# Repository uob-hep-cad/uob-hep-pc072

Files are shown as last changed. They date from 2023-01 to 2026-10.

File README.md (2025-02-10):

# uob-hep-pc072
DUNE Timing System MicroTCA Interface Board(MIB). 

Schematic capture in Cadence DE-HDL. PCB Layout in Cadence Allegro.

Design files for the current (v3) board at https://github.com/uob-hep-cad/uob-hep-pc072/tree/main/hardware/Cadence/top/mtca_interface_board_reocc/top_mib_v3 (project file https://github.com/uob-hep-cad/uob-hep-pc072/blob/main/hardware/Cadence/top/top_mib_v3.cpm)

Design files for the tongue-2 board at https://github.com/uob-hep-cad/uob-hep-pc072/tree/main/hardware/Cadence/top/mtca_interface_board_reocc/mib_tongue2 (project file https://github.com/uob-hep-cad/uob-hep-pc072/blob/main/hardware/Cadence/top/top_mib_v3.cpm)

Schematic capture and PCB layout of the original (v1) version done at University of Pensylvania by Godwin Meyers in Cadence Orcad/Allegro

The v1 design translated to Cadence Allegro Design Entry HDL by Elgris Technologies

Changes to v1 design done by Magnus Loutit and David Cussans to produce the v2 and then v3 design

PCB layout of the v3 design done at the University of Oxford by Pete Hastings

The MIB v2 onwards has no ADN2814 CDR - recovery of clock done directly by Si5395 PLL

List of changes w.r.t. v0.1 MIB at https://webapps-pp.bris.ac.uk/elog/DUNE/34

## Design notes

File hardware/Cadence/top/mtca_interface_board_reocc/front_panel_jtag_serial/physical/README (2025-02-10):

pc072_mib_jtag_serial

Version = A
Subversion = 20

This file describes PCB fabrication details for the
JTAG/Serial mezzanine board for the MIB v2 
for the DUNE timing system
 
contact:	David.Cussans@bristol.ac.uk
		tel: 0117 95 46879
		     0117 33 17199
		fax: 0117 925 5624

Files produced by Cadence Allegro PE17.4

Artwork:
--------

Format: Gerber RS-274X , parameters described in art_param.txt. 
All layers viewed from top

Build:
------

"PCBTrain" 4-layer build from Newbury
Immersion silver finish to outer layers

Layers as follows:

pc072_mib_jtag_serial_20_01_Top.art
pc072_mib_jtag_serial_20_02_Gnd.art
pc072_mib_jtag_serial_20_03_Vcc.art
pc072_mib_jtag_serial_20_04_Bottom.art

Solder Masks
------------

pc072_mib_jtag_serial_20_13_smask_top.art
pc072_mib_jtag_serial_20_14_smask_bot.art

Colour - green. 

Solderpaste mask (N.B. No SMD components on bottom face of board)
-----------------

pc072_mib_jtag_serial_20_27_pmask_top.art
pc072_mib_jtag_serial_20_28_pmask_bot.art

Silk screen
-----------

pc072_mib_jtag_serial_20_11_silk_top.art
pc072_mib_jtag_serial_20_12_silk_bot.art

Colour - white.

Board outline: (Gerber RS-274X)
-------------------------------

pc072_mib_jtag_serial_20_18_DESIGN_OUTLINE.art

Fabrication drawing: ( Including illustration of hole sizes/position and board stack-up)
----------------------------------------------------------------------------------------

pc072_mib_jtag_serial_20_fab_plot.art

Drill information ( Excellon format, described in nc_param.txt. Drill size also in nc_tools_auto.txt )
----------------------------------------------------------------

pc072_mib_jtag_serial_20-1-4.drl

Router information ( Excellon format, described in nc_param.txt. Router bit information also in ncroutebits_auto.txt )
----------------------------------------------------------------

mib_fp_jtag_serial_20_1-4.rou 

Drill figure (Gerber format)
----------------------------

pc072_mib_jtag_serial_20_10_drill_figure.art

Bill of Materials for Assembly (Microsoft Excel XLSX format)
------------------------------------------------------------

uob-hep-pc072-mib_fp_jtag_serial_10.xlsx

Assembly Information (IPC2581 format)
-------------------------------------

mib_fp_jtag_serial_20_ipc2581.xml

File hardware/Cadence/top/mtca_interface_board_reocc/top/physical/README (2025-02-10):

pc072

Version = A
Subversion = 205

This file describes PCB fabrication details for the MIB v2 
for the DUNE timing system
 
contact:	David.Cussans@bristol.ac.uk
		tel: 0117 95 46879
		     0117 33 17199
		fax: 0117 925 5624

Files produced by Cadence Allegro PE17.4

Artwork:
--------

Format: Gerber RS-274X , parameters described in art_param.txt. 
All layers viewed from top

Build:
------

"PCBTrain" 10-layer build from Newbury
ENIG finish to outer layers

Layers as follows:

mib_rev2_v205_01_Top.art
mib_rev2_v205_02_GND.art
mib_rev2_v205_03_sig1.art
mib_rev2_v205_04_GND.art
mib_rev2_v205_05_PWR1.art
mib_rev2_v205_06_GND.art
mib_rev2_v205_07_SIG2.art
mib_rev2_v205_08_GND.art
mib_rev2_v205_09_SIG3.art
mib_rev2_v205_10_Bottom.art

Solder Masks
------------

mib_rev2_v205_13_smask_top.art
mib_rev2_v205_14_smask_bot.art

Colour - green. 

Solderpaste mask
-----------------

mib_rev2_v205_27_pmask_top.art
mib_rev2_v205_28_pmask_bot.art

Silk screen
-----------

mib_rev2_v205_11_silk_top.art
mib_rev2_v205_12_silk_bot.art

Colour - white.

Board outline: (Gerber RS-274X)
-------------------------------

mib_rev2_v205_18_DESIGN_OUTLINE.art

Board cutout: 
-------------------------------

The board has one cutout. outline of cutout in:

mib_rev2_v199_19_CUTOUT.art  (Gerber RS-274X)
mib_rev2_v205_1-10.rou       (Excellon)

Fabrication drawing: ( Including illustration of hole sizes/position and board stack-up)
-------------

N.B. Ignore comments about hard-gold on connector "fingers"

mib_rev2_v199_15_fab_plot.art

Drill information ( Excellon format, described in nc_param.txt )
----------------------------------------------------------------

mib_rev2_v205-1-10.drl

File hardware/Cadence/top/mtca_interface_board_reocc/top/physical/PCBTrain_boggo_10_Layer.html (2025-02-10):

Version : 17.400

Date/Time : 2023-03-20T18:32:34

Worksheet Name : Cross Section\Layer\Cross Section\Properties

Objects | | Types | | | | Thickness | | | Physical | | | | | | Embedded | | Signal Integrity
# | Name | Layer | Layer Function | Manufacture | Constraint | Value | (+)Tol. | (-)Tol. | Layer ID | Material | Negative Artwork | No Fillet | Unused Pin Suppression | Unused Via Suppression | Embedded Status | Attach Method | Conductivity | Dielectric Constant | Width | Impedance | Loss Tangent | Shield | Freq. Dep. File | Etch Factor | Diff Coupling Type | Diff Spacing | Diff Z0 | SI Ignore

| | | | | | mm | mm | mm | | | | | | | | | mho/cm | | mm | Ohm | | | | | | mm | Ohm
* | * | * | * | * | * | * | * | * | * | * | * | * | * | * | * | * | * | * | * | * | * | * | * | * | * | * | * | *
| | Surface | | | | | | | | | | | | | | | | 1 | | | 0
1 | TOP | Conductor | Conductor | | | 0.035 | 0.00254 | 0.00254 | 1 | 1oz Copper | | | | | Not embedded | | 580000 | 1 | 0.1871 | 54.267 | 0 | | | 90 | Edge | 0.2500 | 99.932
| | Dielectric | Dielectric | | | 0.12 | 0 | 0 | | Fr-4 | | | | | | | 0 | 4.2 | | | 0.035
2 | 02_GND | Plane | Plane | | | 0.035 | 0.00254 | 0.00254 | 2 | 1oz Copper | | | | | Not embedded | | 580000 | 1 | | | 0 | | | 90
| | Dielectric | Dielectric | | | 0.2 | 0 | 0 | | Fr-4 | | | | | | | 0 | 4.2 | | | 0.035
3 | 03_SIG1 | Conductor | Conductor | | | 0.035 | 0.00254 | 0.00254 | 3 | 1oz Copper | | | | | Not embedded | | 580000 | 1 | 0.1250 | 49.054 | 0 | | | 90 | Edge | 0.5000 | 96.692
| | Dielectric | Dielectric | | | 0.12 | 0 | 0 | | Fr-4 | | | | | | | 0 | 4.2 | | | 0.035
4 | 04_GND | Plane | Plane | | | 0.035 | 0 | 0 | 4 | 1oz Copper | | | | | Not embedded | | 580000 | 1 | | | 0 | | | 90
| | Dielectric | Dielectric | | | 0.2 | 0 | 0 | | Fr-4 | | | | | | | 0 | 4.2 | | | 0.035
5 | 05_PWR1 | Plane | Plane | | | 0.035 | 0 | 0 | 5 | 1oz Copper | | | | | Not embedded | | 580000 | 1 | | | 0 | | | 90
| | Dielectric | Dielectric | | | 0.12 | 0 | 0 | | Fr-4 | | | | | | | 0 | 4.2 | | | 0.035
6 | 06_GND | Plane | Plane | | | 0.035 | 0.00254 | 0.00254 | 6 | 1oz Copper | | | | | Not embedded | | 580000 | 1 | | | 0 | | | 90
| | Dielectric | Dielectric | | | 0.2 | 0 | 0 | | Fr-4 | | | | | | | 0 | 4.2 | | | 0.035
7 | 07_SIG2 | Conductor | Conductor | | | 0.035 | 0.00254 | 0.00254 | 7 | 1oz Copper | | | | | Not embedded | | 580000 | 1 | 0.1250 | 49.054 | 0 | | | 90 | Edge | 0.5000 | 96.692
| | Dielectric | Dielectric | | | 0.12 | 0 | 0 | | Fr-4 | | | | | | | 0 | 4.2 | | | 0.035
8 | 08_GND | Plane | Plane | | | 0.035 | 0.00254 | 0.00254 | 8 | 1oz Copper | | | | | Not embedded | | 580000 | 1 | | | 0 | | | 90
| | Dielectric | Dielectric | | | 0.2 | 0 | 0 | | Fr-4 | | | | | | | 0 | 4.2 | | | 0.035
9 | 09_SIG3 | Conductor | Conductor | | | 0.035 | 0.00254 | 0.00254 | 9 | 1oz Copper | | | | | Not embedded | | 580000 | 1 | 0.1917 | 64.587 | 0 | | | 90 | Edge | 0.2000 | 100.04
| | Dielectric | Dielectric | | | 0.12 | 0 | 0 | | Fr-4 | | | | | | | 0 | 4.2 | | | 0.035
10 | BOTTOM | Conductor | Conductor | | | 0.035 | 0.00254 | 0.00254 | 10 | 1oz Copper | | | | | Not embedded | | 580000 | 1 | 0.3272 | 79.191 | 0 | | | 90 | Edge | 0.1250 | 99.968
| | Surface | | | | | | | | | | | | | | | | 1 | | | 0

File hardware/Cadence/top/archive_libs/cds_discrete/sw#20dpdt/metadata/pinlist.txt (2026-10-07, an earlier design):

(Pinlist
	(Pin
		(Name COMMON1)
		(MSB )
		(LSB )
		(Type ANALOG)
		(Location Left)
		(InputLoadLow )
		(InputLoadHigh )
		(OutputLoadLow )
		(OutputLoadHigh )
		(CheckLoad Off)
		(CheckIO Off)
		(CheckDir 0)
		(CheckAssert 0)
		(CheckOutput 0)
		(UnknownLoading 0)
		(PinShape )
		(DIFF_PAIR_PINS_POS )
		(DIFF_PAIR_PINS_NEG )
	)

	(Pin
		(Name NC1)
		(MSB )
		(LSB )
		(Type ANALOG)
		(Location Right)
		(InputLoadLow )
		(InputLoadHigh )
		(OutputLoadLow )
		(OutputLoadHigh )
		(CheckLoad Off)
		(CheckIO Off)
		(CheckDir 0)
		(CheckAssert 0)
		(CheckOutput 0)
		(UnknownLoading 0)
		(PinShape )
		(DIFF_PAIR_PINS_POS )
		(DIFF_PAIR_PINS_NEG )
	)

	(Pin
		(Name NO1)
		(MSB )
		(LSB )
		(Type ANALOG)
		(Location Right)
		(InputLoadLow )
		(InputLoadHigh )
		(OutputLoadLow )
		(OutputLoadHigh )
		(CheckLoad Off)
		(CheckIO Off)
		(CheckDir 0)
		(CheckAssert 0)
		(CheckOutput 0)
		(UnknownLoading 0)
		(PinShape )
		(DIFF_PAIR_PINS_POS )
		(DIFF_PAIR_PINS_NEG )
	)

	(Pin
		(Name COMMON2)
		(MSB )
		(LSB )
		(Type ANALOG)
		(Location Left)
		(InputLoadLow )
		(InputLoadHigh )
		(OutputLoadLow )
		(OutputLoadHigh )
		(CheckLoad Off)
		(CheckIO Off)
		(CheckDir 0)
		(CheckAssert 0)
		(CheckOutput 0)
		(UnknownLoading 0)
		(PinShape )
		(DIFF_PAIR_PINS_POS )
		(DIFF_PAIR_PINS_NEG )
	)

	(Pin
		(Name NC2)
		(MSB )
		(LSB )
		(Type ANALOG)
		(Location Right)
		(InputLoadLow )
		(InputLoadHigh )
		(OutputLoadLow )
		(OutputLoadHigh )
		(CheckLoad Off)
		(CheckIO Off)
		(CheckDir 0)
		(CheckAssert 0)
		(CheckOutput 0)
		(UnknownLoading 0)
		(PinShape )
		(DIFF_PAIR_PINS_POS )
		(DIFF_PAIR_PINS_NEG )
	)

	(Pin
		(Name NO2)
		(MSB )
		(LSB )
		(Type ANALOG)
		(Location Right)
		(InputLoadLow )
		(InputLoadHigh )
		(OutputLoadLow )
		(OutputLoadHigh )
		(CheckLoad Off)
		(CheckIO Off)
		(CheckDir 0)
		(CheckAssert 0)
		(CheckOutput 0)
		(UnknownLoading 0)
		(PinShape )
		(DIFF_PAIR_PINS_POS )
		(DIFF_PAIR_PINS_NEG )
	)

)

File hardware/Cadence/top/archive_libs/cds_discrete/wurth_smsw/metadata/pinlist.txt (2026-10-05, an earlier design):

(Pinlist
	(Pin
		(Name K)
		(MSB )
		(LSB )
		(Type ANALOG)
		(Location Left)
		(InputLoadLow )
		(InputLoadHigh )
		(OutputLoadLow )
		(OutputLoadHigh )
		(CheckLoad Off)
		(CheckIO Off)
		(CheckDir 0)
		(CheckAssert 0)
		(CheckOutput 0)
		(UnknownLoading 0)
		(PinShape )
		(DIFF_PAIR_PINS_POS )
		(DIFF_PAIR_PINS_NEG )
	)

	(Pin
		(Name A)
		(MSB )
		(LSB )
		(Type ANALOG)
		(Location Left)
		(InputLoadLow )
		(InputLoadHigh )
		(OutputLoadLow )
		(OutputLoadHigh )
		(CheckLoad Off)
		(CheckIO Off)
		(CheckDir 0)
		(CheckAssert 0)
		(CheckOutput 0)
		(UnknownLoading 0)
		(PinShape Line)
		(DIFF_PAIR_PINS_POS )
		(DIFF_PAIR_PINS_NEG )
	)

	(Pin
		(Name 1)
		(MSB )
		(LSB )
		(Type ANALOG)
		(Location Left)
		(InputLoadLow )
		(InputLoadHigh )
		(OutputLoadLow )
		(OutputLoadHigh )
		(CheckLoad Off)
		(CheckIO Off)
		(CheckDir 0)
		(CheckAssert 0)
		(CheckOutput 0)
		(UnknownLoading 0)
		(PinShape )
		(DIFF_PAIR_PINS_POS )
		(DIFF_PAIR_PINS_NEG )
	)

	(Pin
		(Name 2)
		(MSB )
		(LSB )
		(Type ANALOG)
		(Location Right)
		(InputLoadLow )
		(InputLoadHigh )
		(OutputLoadLow )
		(OutputLoadHigh )
		(CheckLoad Off)
		(CheckIO Off)
		(CheckDir 0)
		(CheckAssert 0)
		(CheckOutput 0)
		(UnknownLoading 0)
		(PinShape )
		(DIFF_PAIR_PINS_POS )
		(DIFF_PAIR_PINS_NEG )
	)

	(Pin
		(Name WURTH SMSW)
		(MSB )
		(LSB )
		(Type ANALOG)
		(Location Right)
		(InputLoadLow )
		(InputLoadHigh )
		(OutputLoadLow )
		(OutputLoadHigh )
		(CheckLoad Off)
		(CheckIO Off)
		(CheckDir 0)
		(CheckAssert 0)
		(CheckOutput 0)
		(UnknownLoading 0)
		(PinShape Line)
		(DIFF_PAIR_PINS_POS )
		(DIFF_PAIR_PINS_NEG )
	)

)

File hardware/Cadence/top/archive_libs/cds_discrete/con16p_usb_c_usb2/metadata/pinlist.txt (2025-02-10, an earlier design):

(Pinlist
	(Pin
		(Name GND1)
		(MSB )
		(LSB )
		(Type POWER)
		(Location Right)
		(InputLoadLow )
		(InputLoadHigh )
		(OutputLoadLow )
		(OutputLoadHigh )
		(CheckLoad Off)
		(CheckIO Off)
		(CheckDir 0)
		(CheckAssert 0)
		(CheckOutput 0)
		(UnknownLoading 0)
		(PinShape )
		(DIFF_PAIR_PINS_POS )
		(DIFF_PAIR_PINS_NEG )
	)

	(Pin
		(Name VBUS1)
		(MSB )
		(LSB )
		(Type POWER)
		(Location Left)
		(InputLoadLow )
		(InputLoadHigh )
		(OutputLoadLow )
		(OutputLoadHigh )
		(CheckLoad Off)
		(CheckIO Off)
		(CheckDir 0)
		(CheckAssert 0)
		(CheckOutput 0)
		(UnknownLoading 0)
		(PinShape )
		(DIFF_PAIR_PINS_POS )
		(DIFF_PAIR_PINS_NEG )
	)

	(Pin
		(Name CC1)
		(MSB )
		(LSB )
		(Type BIDIR)
		(Location Left)
		(InputLoadLow -0.01)
		(InputLoadHigh 0.01)
		(OutputLoadLow 1.0)
		(OutputLoadHigh -1.0)
		(CheckLoad Both)
		(CheckIO Both)
		(CheckDir 1)
		(CheckAssert 1)
		(CheckOutput 1)
		(UnknownLoading 0)
		(PinShape )
		(DIFF_PAIR_PINS_POS )
		(DIFF_PAIR_PINS_NEG )
	)

	(Pin
		(Name DA+)
		(MSB )
		(LSB )
		(Type BIDIR)
		(Location Left)
		(InputLoadLow -0.01)
		(InputLoadHigh 0.01)
		(OutputLoadLow 1.0)
		(OutputLoadHigh -1.0)
		(CheckLoad Both)
		(CheckIO Both)
		(CheckDir 1)
		(CheckAssert 1)
		(CheckOutput 1)
		(UnknownLoading 0)
		(PinShape )
		(DIFF_PAIR_PINS_POS )
		(DIFF_PAIR_PINS_NEG )
	)

	(Pin
		(Name DA-)
		(MSB )
		(LSB )
		(Type BIDIR)
		(Location Left)
		(InputLoadLow -0.01)
		(InputLoadHigh 0.01)
		(OutputLoadLow 1.0)
		(OutputLoadHigh -1.0)
		(CheckLoad Both)
		(CheckIO Both)
		(CheckDir 1)
		(CheckAssert 1)
		(CheckOutput 1)
		(UnknownLoading 0)
		(PinShape )
		(DIFF_PAIR_PINS_POS )
		(DIFF_PAIR_PINS_NEG )
	)

	(Pin
		(Name SBU1)
		(MSB )
		(LSB )
		(Type BIDIR)
		(Location Left)
		(InputLoadLow -0.01)
		(InputLoadHigh 0.01)
		(OutputLoadLow 1.0)
		(OutputLoadHigh -1.0)
		(CheckLoad Both)
		(CheckIO Both)
		(CheckDir 1)
		(CheckAssert 1)
		(CheckOutput 1)
		(UnknownLoading 0)
		(PinShape )
		(DIFF_PAIR_PINS_POS )
		(DIFF_PAIR_PINS_NEG )
	)

	(Pin
		(Name GND2)
		(MSB )
		(LSB )
		(Type POWER)
		(Location Right)
		(InputLoadLow )
		(InputLoadHigh )
		(OutputLoadLow )
		(OutputLoadHigh )
		(CheckLoad Off)
		(CheckIO Off)
		(CheckDir 0)
		(CheckAssert 0)
		(CheckOutput 0)
		(UnknownLoading 0)
		(PinShape )
		(DIFF_PAIR_PINS_POS )
		(DIFF_PAIR_PINS_NEG )
	)

	(Pin
		(Name VBUS2)
		(MSB )
		(LSB )
		(Type POWER)
		(Location Left)
		(InputLoadLow )
		(InputLoadHigh )
		(OutputLoadLow )
		(OutputLoadHigh )
		(CheckLoad Off)
		(CheckIO Off)
		(CheckDir 0)
		(CheckAssert 0)
		(CheckOutput 0)
		(UnknownLoading 0)
		(PinShape )
		(DIFF_PAIR_PINS_POS )
		(DIFF_PAIR_PINS_NEG )
	)

	(Pin
		(Name SBU2)
		(MSB )
		(LSB )
		(Type BIDIR)
		(Location Right)
		(InputLoadLow -0.01)
		(InputLoadHigh 0.01)
		(OutputLoadLow 1.0)
		(OutputLoadHigh -1.0)
		(CheckLoad Both)
		(CheckIO Both)
		(CheckDir 1)
		(CheckAssert 1)
		(CheckOutput 1)
		(UnknownLoading 0)
		(PinShape )
		(DIFF_PAIR_PINS_POS )
		(DIFF_PAIR_PINS_NEG )
	)

	(Pin
		(Name CC2)
		(MSB )
		(LSB )
		(Type BIDIR)
		(Location Right)
		(InputLoadLow -0.01)
		(InputLoadHigh 0.01)
		(OutputLoadLow 1.0)
		(OutputLoadHigh -1.0)
		(CheckLoad Both)
		(CheckIO Both)
		(CheckDir 1)
		(CheckAssert 1)
		(CheckOutput 1)
		(UnknownLoading 0)
		(PinShape )
		(DIFF_PAIR_PINS_POS )
		(DIFF_PAIR_PINS_NEG )
	)

	(Pin
		(Name DB+)
		(MSB )
		(LSB )
		(Type BIDIR)
		(Location Right)
		(InputLoadLow -0.01)
		(InputLoadHigh 0.01)
		(OutputLoadLow 1.0)
		(OutputLoadHigh -1.0)
		(CheckLoad Both)
		(CheckIO Both)
		(CheckDir 1)
		(CheckAssert 1)
		(CheckOutput 1)
		(UnknownLoading 0)
		(PinShape )
		(DIFF_PAIR_PINS_POS )
		(DIFF_PAIR_PINS_NEG )
	)

	(Pin
		(Name DB-)
		(MSB )
		(LSB )
		(Type BIDIR)
		(Location Right)
		(InputLoadLow -0.01)
		(InputLoadHigh 0.01)
		(OutputLoadLow 1.0)
		(OutputLoadHigh -1.0)
		(CheckLoad Both)
		(CheckIO Both)
		(CheckDir 1)
		(CheckAssert 1)
		(CheckOutput 1)
		(UnknownLoading 0)
		(PinShape )
		(DIFF_PAIR_PINS_POS )
		(DIFF_PAIR_PINS_NEG )
	)

	(Pin
		(Name SHIELD1)
		(MSB )
		(LSB )
		(Type ANALOG)
		(Location Right)
		(InputLoadLow )
		(InputLoadHigh )
		(OutputLoadLow )
		(OutputLoadHigh )
		(CheckLoad Off)
		(CheckIO Off)
		(CheckDir 0)
		(CheckAssert 0)
		(CheckOutput 0)
		(UnknownLoading 0)
		(PinShape )
		(DIFF_PAIR_PINS_POS )
		(DIFF_PAIR_PINS_NEG )
	)

	(Pin
		(Name SHIELD2)
		(MSB )
		(LSB )
		(Type ANALOG)
		(Location Right)
		(InputLoadLow )
		(InputLoadHigh )
		(OutputLoadLow )
		(OutputLoadHigh )
		(CheckLoad Off)
		(CheckIO Off)
		(CheckDir 0)
		(CheckAssert 0)
		(CheckOutput 0)
		(UnknownLoading 0)
		(PinShape )
		(DIFF_PAIR_PINS_POS )
		(DIFF_PAIR_PINS_NEG )
	)

	(Pin
		(Name SHIELD3)
		(MSB )
		(LSB )
		(Type ANALOG)
		(Location Right)
		(InputLoadLow )
		(InputLoadHigh )
		(OutputLoadLow )
		(OutputLoadHigh )
		(CheckLoad Off)
		(CheckIO Off)
		(CheckDir 0)
		(CheckAssert 0)
		(CheckOutput 0)
		(UnknownLoading 0)
		(PinShape )
		(DIFF_PAIR_PINS_POS )
		(DIFF_PAIR_PINS_NEG )
	)

	(Pin
		(Name SHIELD4)
		(MSB )
		(LSB )
		(Type ANALOG)
		(Location Right)
		(InputLoadLow )
		(InputLoadHigh )
		(OutputLoadLow )
		(OutputLoadHigh )
		(CheckLoad Off)
		(CheckIO Off)
		(CheckDir 0)
		(CheckAssert 0)
		(CheckOutput 0)
		(UnknownLoading 0)
		(PinShape )
		(DIFF_PAIR_PINS_POS )
		(DIFF_PAIR_PINS_NEG )
	)

	(Pin
		(Name GND3)
		(MSB )
		(LSB )
		(Type POWER)
		(Location Right)
		(InputLoadLow )
		(InputLoadHigh )
		(OutputLoadLow )
		(OutputLoadHigh )
		(CheckLoad Off)
		(CheckIO Off)
		(CheckDir 0)
		(CheckAssert 0)
		(CheckOutput 0)
		(UnknownLoading 0)
		(PinShape )
		(DIFF_PAIR_PINS_POS )
		(DIFF_PAIR_PINS_NEG )
	)

	(Pin
		(Name VBUS3)
		(MSB )
		(LSB )
		(Type POWER)
		(Location Left)
		(InputLoadLow )
		(InputLoadHigh )
		(OutputLoadLow )
		(OutputLoadHigh )
		(CheckLoad Off)
		(CheckIO Off)
		(CheckDir 0)
		(CheckAssert 0)
		(CheckOutput 0)
		(UnknownLoading 0)
		(PinShape )
		(DIFF_PAIR_PINS_POS )
		(DIFF_PAIR_PINS_NEG )
	)

	(Pin
		(Name GND4)
		(MSB )
		(LSB )
		(Type POWER)
		(Location Right)
		(InputLoadLow )
		(InputLoadHigh )
		(OutputLoadLow )
		(OutputLoadHigh )
		(CheckLoad Off)
		(CheckIO Off)
		(CheckDir 0)
		(CheckAssert 0)
		(CheckOutput 0)
		(UnknownLoading 0)
		(PinShape )
		(DIFF_PAIR_PINS_POS )
		(DIFF_PAIR_PINS_NEG )
	)

	(Pin
		(Name VBUS4)
		(MSB )
		(LSB )
		(Type POWER)
		(Location Left)
		(InputLoadLow )
		(InputLoadHigh )
		(OutputLoadLow )
		(OutputLoadHigh )
		(CheckLoad Off)
		(CheckIO Off)
		(CheckDir 0)
		(CheckAssert 0)
		(CheckOutput 0)
		(UnknownLoading 0)
		(PinShape )
		(DIFF_PAIR_PINS_POS )
		(DIFF_PAIR_PINS_NEG )
	)

)

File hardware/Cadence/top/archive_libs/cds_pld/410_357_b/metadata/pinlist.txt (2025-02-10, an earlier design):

(Pinlist
	(Pin
		(Name GND_1)
		(MSB )
		(LSB )
		(Type UNSPEC)
		(Location Bottom)
		(InputLoadLow )
		(InputLoadHigh )
		(OutputLoadLow )
		(OutputLoadHigh )
		(CheckLoad Off)
		(CheckIO Off)
		(CheckDir 1)
		(CheckAssert 1)
		(CheckOutput 0)
		(UnknownLoading 0)
		(PinShape Line)
		(DIFF_PAIR_PINS_POS )
		(DIFF_PAIR_PINS_NEG )
	)

	(Pin
		(Name VREF)
		(MSB )
		(LSB )
		(Type UNSPEC)
		(Location Bottom)
		(InputLoadLow )
		(InputLoadHigh )
		(OutputLoadLow )
		(OutputLoadHigh )
		(CheckLoad Off)
		(CheckIO Off)
		(CheckDir 1)
		(CheckAssert 1)
		(CheckOutput 0)
		(UnknownLoading 0)
		(PinShape Line)
		(DIFF_PAIR_PINS_POS )
		(DIFF_PAIR_PINS_NEG )
	)

	(Pin
		(Name CTS)
		(MSB )
		(LSB )
		(Type UNSPEC)
		(Location Bottom)
		(InputLoadLow )
		(InputLoadHigh )
		(OutputLoadLow )
		(OutputLoadHigh )
		(CheckLoad Off)
		(CheckIO Off)
		(CheckDir 1)
		(CheckAssert 1)
		(CheckOutput 0)
		(UnknownLoading 0)
		(PinShape Line)
		(DIFF_PAIR_PINS_POS )
		(DIFF_PAIR_PINS_NEG )
	)

	(Pin
		(Name RTS)
		(MSB )
		(LSB )
		(Type UNSPEC)
		(Location Bottom)
		(InputLoadLow )
		(InputLoadHigh )
		(OutputLoadLow )
		(OutputLoadHigh )
		(CheckLoad Off)
		(CheckIO Off)
		(CheckDir 1)
		(CheckAssert 1)
		(CheckOutput 0)
		(UnknownLoading 0)
		(PinShape Line)
		(DIFF_PAIR_PINS_POS )
		(DIFF_PAIR_PINS_NEG )
	)

	(Pin
		(Name RXD)
		(MSB )
		(LSB )
		(Type UNSPEC)
		(Location Bottom)
		(InputLoadLow )
		(InputLoadHigh )
		(OutputLoadLow )
		(OutputLoadHigh )
		(CheckLoad Off)
		(CheckIO Off)
		(CheckDir 1)
		(CheckAssert 1)
		(CheckOutput 0)
		(UnknownLoading 0)
		(PinShape Line)
		(DIFF_PAIR_PINS_POS )
		(DIFF_PAIR_PINS_NEG )
	)

	(Pin
		(Name TXD)
		(MSB )
		(LSB )
		(Type UNSPEC)
		(Location Right)
		(InputLoadLow )
		(InputLoadHigh )
		(OutputLoadLow )
		(OutputLoadHigh )
		(CheckLoad Off)
		(CheckIO Off)
		(CheckDir 1)
		(CheckAssert 1)
		(CheckOutput 0)
		(UnknownLoading 0)
		(PinShape Line)
		(DIFF_PAIR_PINS_POS )
		(DIFF_PAIR_PINS_NEG )
	)

	(Pin
		(Name GND_2)
		(MSB )
		(LSB )
		(Type UNSPEC)
		(Location Right)
		(InputLoadLow )
		(InputLoadHigh )
		(OutputLoadLow )
		(OutputLoadHigh )
		(CheckLoad Off)
		(CheckIO Off)
		(CheckDir 1)
		(CheckAssert 1)
		(CheckOutput 0)
		(UnknownLoading 0)
		(PinShape Line)
		(DIFF_PAIR_PINS_POS )
		(DIFF_PAIR_PINS_NEG )
	)

	(Pin
		(Name VREF_JTAG)
		(MSB )
		(LSB )
		(Type UNSPEC)
		(Location Right)
		(InputLoadLow )
		(InputLoadHigh )
		(OutputLoadLow )
		(OutputLoadHigh )
		(CheckLoad Off)
		(CheckIO Off)
		(CheckDir 1)
		(CheckAssert 1)
		(CheckOutput 0)
		(UnknownLoading 0)
		(PinShape Line)
		(DIFF_PAIR_PINS_POS )
		(DIFF_PAIR_PINS_NEG )
	)

	(Pin
		(Name PS_SRST_B)
		(MSB )
		(LSB )
		(Type UNSPEC)
		(Location Right)
		(InputLoadLow )
		(InputLoadHigh )
		(OutputLoadLow )
		(OutputLoadHigh )
		(CheckLoad Off)
		(CheckIO Off)
		(CheckDir 1)
		(CheckAssert 1)
		(CheckOutput 0)
		(UnknownLoading 0)
		(PinShape Line)
		(DIFF_PAIR_PINS_POS )
		(DIFF_PAIR_PINS_NEG )
	)

	(Pin
		(Name TCK)
		(MSB )
		(LSB )
		(Type UNSPEC)
		(Location Top)
		(InputLoadLow )
		(InputLoadHigh )
		(OutputLoadLow )
		(OutputLoadHigh )
		(CheckLoad Off)
		(CheckIO Off)
		(CheckDir 1)
		(CheckAssert 1)
		(CheckOutput 0)
		(UnknownLoading 0)
		(PinShape Line)
		(DIFF_PAIR_PINS_POS )
		(DIFF_PAIR_PINS_NEG )
	)

	(Pin
		(Name TDO)
		(MSB )
		(LSB )
		(Type UNSPEC)
		(Location Top)
		(InputLoadLow )
		(InputLoadHigh )
		(OutputLoadLow )
		(OutputLoadHigh )
		(CheckLoad Off)
		(CheckIO Off)
		(CheckDir 1)
		(CheckAssert 1)
		(CheckOutput 0)
		(UnknownLoading 0)
		(PinShape Line)
		(DIFF_PAIR_PINS_POS )
		(DIFF_PAIR_PINS_NEG )
	)

	(Pin
		(Name TDI)
		(MSB )
		(LSB )
		(Type UNSPEC)
		(Location Top)
		(InputLoadLow )
		(InputLoadHigh )
		(OutputLoadLow )
		(OutputLoadHigh )
		(CheckLoad Off)
		(CheckIO Off)
		(CheckDir 1)
		(CheckAssert 1)
		(CheckOutput 0)
		(UnknownLoading 0)
		(PinShape Line)
		(DIFF_PAIR_PINS_POS )
		(DIFF_PAIR_PINS_NEG )
	)

	(Pin
		(Name TMS)
		(MSB )
		(LSB )
		(Type UNSPEC)
		(Location Top)
		(InputLoadLow )
		(InputLoadHigh )
		(OutputLoadLow )
		(OutputLoadHigh )
		(CheckLoad Off)
		(CheckIO Off)
		(CheckDir 1)
		(CheckAssert 1)
		(CheckOutput 0)
		(UnknownLoading 0)
		(PinShape Line)
		(DIFF_PAIR_PINS_POS )
		(DIFF_PAIR_PINS_NEG )
	)

	(Pin
		(Name GND_3)
		(MSB )
		(LSB )
		(Type UNSPEC)
		(Location Top)
		(InputLoadLow )
		(InputLoadHigh )
		(OutputLoadLow )
		(OutputLoadHigh )
		(CheckLoad Off)
		(CheckIO Off)
		(CheckDir 1)
		(CheckAssert 1)
		(CheckOutput 0)
		(UnknownLoading 0)
		(PinShape Line)
		(DIFF_PAIR_PINS_POS )
		(DIFF_PAIR_PINS_NEG )
	)

	(Pin
		(Name VDD)
		(MSB )
		(LSB )
		(Type UNSPEC)
		(Location Left)
		(InputLoadLow )
		(InputLoadHigh )
		(OutputLoadLow )
		(OutputLoadHigh )
		(CheckLoad Off)
		(CheckIO Off)
		(CheckDir 1)
		(CheckAssert 1)
		(CheckOutput 0)
		(UnknownLoading 0)
		(PinShape Line)
		(DIFF_PAIR_PINS_POS )
		(DIFF_PAIR_PINS_NEG )
	)

	(Pin
		(Name USB_DM)
		(MSB )
		(LSB )
		(Type UNSPEC)
		(Location Left)
		(InputLoadLow )
		(InputLoadHigh )
		(OutputLoadLow )
		(OutputLoadHigh )
		(CheckLoad Off)
		(CheckIO Off)
		(CheckDir 1)
		(CheckAssert 1)
		(CheckOutput 0)
		(UnknownLoading 0)
		(PinShape Line)
		(DIFF_PAIR_PINS_POS )
		(DIFF_PAIR_PINS_NEG )
	)

	(Pin
		(Name USB_DP)
		(MSB )
		(LSB )
		(Type UNSPEC)
		(Location Left)
		(InputLoadLow )
		(InputLoadHigh )
		(OutputLoadLow )
		(OutputLoadHigh )
		(CheckLoad Off)
		(CheckIO Off)
		(CheckDir 1)
		(CheckAssert 1)
		(CheckOutput 0)
		(UnknownLoading 0)
		(PinShape Line)
		(DIFF_PAIR_PINS_POS )
		(DIFF_PAIR_PINS_NEG )
	)

	(Pin
		(Name VBUS_DETECT)
		(MSB )
		(LSB )
		(Type UNSPEC)
		(Location Left)
		(InputLoadLow )
		(InputLoadHigh )
		(OutputLoadLow )
		(OutputLoadHigh )
		(CheckLoad Off)
		(CheckIO Off)
		(CheckDir 1)
		(CheckAssert 1)
		(CheckOutput 0)
		(UnknownLoading 0)
		(PinShape Line)
		(DIFF_PAIR_PINS_POS )
		(DIFF_PAIR_PINS_NEG )
	)

)

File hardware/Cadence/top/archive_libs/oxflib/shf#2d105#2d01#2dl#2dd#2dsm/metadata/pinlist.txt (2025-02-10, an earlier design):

(Pinlist
	(Pin
		(Name 1)
		(MSB )
		(LSB )
		(Type ANALOG)
		(Location Left)
		(InputLoadLow )
		(InputLoadHigh )
		(OutputLoadLow )
		(OutputLoadHigh )
		(CheckLoad Off)
		(CheckIO Off)
		(CheckDir 0)
		(CheckAssert 0)
		(CheckOutput 0)
		(UnknownLoading 0)
		(PinShape )
		(DIFF_PAIR_PINS_POS )
		(DIFF_PAIR_PINS_NEG )
	)

	(Pin
		(Name 2)
		(MSB )
		(LSB )
		(Type ANALOG)
		(Location Right)
		(InputLoadLow )
		(InputLoadHigh )
		(OutputLoadLow )
		(OutputLoadHigh )
		(CheckLoad Off)
		(CheckIO Off)
		(CheckDir 0)
		(CheckAssert 0)
		(CheckOutput 0)
		(UnknownLoading 0)
		(PinShape )
		(DIFF_PAIR_PINS_POS )
		(DIFF_PAIR_PINS_NEG )
	)

	(Pin
		(Name 3)
		(MSB )
		(LSB )
		(Type ANALOG)
		(Location Left)
		(InputLoadLow )
		(InputLoadHigh )
		(OutputLoadLow )
		(OutputLoadHigh )
		(CheckLoad Off)
		(CheckIO Off)
		(CheckDir 0)
		(CheckAssert 0)
		(CheckOutput 0)
		(UnknownLoading 0)
		(PinShape )
		(DIFF_PAIR_PINS_POS )
		(DIFF_PAIR_PINS_NEG )
	)

	(Pin
		(Name 4)
		(MSB )
		(LSB )
		(Type ANALOG)
		(Location Right)
		(InputLoadLow )
		(InputLoadHigh )
		(OutputLoadLow )
		(OutputLoadHigh )
		(CheckLoad Off)
		(CheckIO Off)
		(CheckDir 0)
		(CheckAssert 0)
		(CheckOutput 0)
		(UnknownLoading 0)
		(PinShape )
		(DIFF_PAIR_PINS_POS )
		(DIFF_PAIR_PINS_NEG )
	)

	(Pin
		(Name 5)
		(MSB )
		(LSB )
		(Type ANALOG)
		(Location Left)
		(InputLoadLow )
		(InputLoadHigh )
		(OutputLoadLow )
		(OutputLoadHigh )
		(CheckLoad Off)
		(CheckIO Off)
		(CheckDir 0)
		(CheckAssert 0)
		(CheckOutput 0)
		(UnknownLoading 0)
		(PinShape )
		(DIFF_PAIR_PINS_POS )
		(DIFF_PAIR_PINS_NEG )
	)

	(Pin
		(Name 6)
		(MSB )
		(LSB )
		(Type ANALOG)
		(Location Right)
		(InputLoadLow )
		(InputLoadHigh )
		(OutputLoadLow )
		(OutputLoadHigh )
		(CheckLoad Off)
		(CheckIO Off)
		(CheckDir 0)
		(CheckAssert 0)
		(CheckOutput 0)
		(UnknownLoading 0)
		(PinShape )
		(DIFF_PAIR_PINS_POS )
		(DIFF_PAIR_PINS_NEG )
	)

	(Pin
		(Name 7)
		(MSB )
		(LSB )
		(Type ANALOG)
		(Location Left)
		(InputLoadLow )
		(InputLoadHigh )
		(OutputLoadLow )
		(OutputLoadHigh )
		(CheckLoad Off)
		(CheckIO Off)
		(CheckDir 0)
		(CheckAssert 0)
		(CheckOutput 0)
		(UnknownLoading 0)
		(PinShape )
		(DIFF_PAIR_PINS_POS )
		(DIFF_PAIR_PINS_NEG )
	)

	(Pin
		(Name 8)
		(MSB )
		(LSB )
		(Type ANALOG)
		(Location Right)
		(InputLoadLow )
		(InputLoadHigh )
		(OutputLoadLow )
		(OutputLoadHigh )
		(CheckLoad Off)
		(CheckIO Off)
		(CheckDir 0)
		(CheckAssert 0)
		(CheckOutput 0)
		(UnknownLoading 0)
		(PinShape )
		(DIFF_PAIR_PINS_POS )
		(DIFF_PAIR_PINS_NEG )
	)

	(Pin
		(Name 9)
		(MSB )
		(LSB )
		(Type ANALOG)
		(Location Left)
		(InputLoadLow )
		(InputLoadHigh )
		(OutputLoadLow )
		(OutputLoadHigh )
		(CheckLoad Off)
		(CheckIO Off)
		(CheckDir 0)
		(CheckAssert 0)
		(CheckOutput 0)
		(UnknownLoading 0)
		(PinShape )
		(DIFF_PAIR_PINS_POS )
		(DIFF_PAIR_PINS_NEG )
	)

	(Pin
		(Name 10)
		(MSB )
		(LSB )
		(Type ANALOG)
		(Location Right)
		(InputLoadLow )
		(InputLoadHigh )
		(OutputLoadLow )
		(OutputLoadHigh )
		(CheckLoad Off)
		(CheckIO Off)
		(CheckDir 0)
		(CheckAssert 0)
		(CheckOutput 0)
		(UnknownLoading 0)
		(PinShape )
		(DIFF_PAIR_PINS_POS )
		(DIFF_PAIR_PINS_NEG )
	)

)

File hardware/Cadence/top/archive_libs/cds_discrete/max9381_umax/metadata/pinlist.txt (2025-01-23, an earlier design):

(Pinlist
	(Pin
		(Name D_P)
		(MSB )
		(LSB )
		(Type INPUT)
		(Location Left)
		(InputLoadLow -0.01)
		(InputLoadHigh 0.01)
		(OutputLoadLow )
		(OutputLoadHigh )
		(CheckLoad Both)
		(CheckIO Both)
		(CheckDir 1)
		(CheckAssert 1)
		(CheckOutput 1)
		(UnknownLoading 0)
		(PinShape Line)
		(DIFF_PAIR_PINS_POS )
		(DIFF_PAIR_PINS_NEG )
	)

	(Pin
		(Name D_N)
		(MSB )
		(LSB )
		(Type INPUT)
		(Location Left)
		(InputLoadLow -0.01)
		(InputLoadHigh 0.01)
		(OutputLoadLow )
		(OutputLoadHigh )
		(CheckLoad Both)
		(CheckIO Both)
		(CheckDir 1)
		(CheckAssert 1)
		(CheckOutput 1)
		(UnknownLoading 0)
		(PinShape Line)
		(DIFF_PAIR_PINS_POS )
		(DIFF_PAIR_PINS_NEG )
	)

	(Pin
		(Name CLK_P)
		(MSB )
		(LSB )
		(Type INPUT)
		(Location Left)
		(InputLoadLow -0.01)
		(InputLoadHigh 0.01)
		(OutputLoadLow )
		(OutputLoadHigh )
		(CheckLoad Both)
		(CheckIO Both)
		(CheckDir 1)
		(CheckAssert 1)
		(CheckOutput 1)
		(UnknownLoading 0)
		(PinShape Line)
		(DIFF_PAIR_PINS_POS )
		(DIFF_PAIR_PINS_NEG )
	)

	(Pin
		(Name CLK_N)
		(MSB )
		(LSB )
		(Type INPUT)
		(Location Left)
		(InputLoadLow -0.01)
		(InputLoadHigh 0.01)
		(OutputLoadLow )
		(OutputLoadHigh )
		(CheckLoad Both)
		(CheckIO Both)
		(CheckDir 1)
		(CheckAssert 1)
		(CheckOutput 1)
		(UnknownLoading 0)
		(PinShape Line)
		(DIFF_PAIR_PINS_POS )
		(DIFF_PAIR_PINS_NEG )
	)

	(Pin
		(Name VEE)
		(MSB )
		(LSB )
		(Type POWER)
		(Location Bottom)
		(InputLoadLow )
		(InputLoadHigh )
		(OutputLoadLow )
		(OutputLoadHigh )
		(CheckLoad Off)
		(CheckIO Off)
		(CheckDir 0)
		(CheckAssert 0)
		(CheckOutput 0)
		(UnknownLoading 0)
		(PinShape )
		(DIFF_PAIR_PINS_POS )
		(DIFF_PAIR_PINS_NEG )
	)

	(Pin
		(Name Q_N)
		(MSB )
		(LSB )
		(Type OUTPUT)
		(Location Right)
		(InputLoadLow )
		(InputLoadHigh )
		(OutputLoadLow 1.0)
		(OutputLoadHigh -1.0)
		(CheckLoad Both)
		(CheckIO Both)
		(CheckDir 1)
		(CheckAssert 1)
		(CheckOutput 1)
		(UnknownLoading 0)
		(PinShape Line)
		(DIFF_PAIR_PINS_POS )
		(DIFF_PAIR_PINS_NEG )
	)

	(Pin
		(Name Q_P)
		(MSB )
		(LSB )
		(Type OUTPUT)
		(Location Right)
		(InputLoadLow )
		(InputLoadHigh )
		(OutputLoadLow 1.0)
		(OutputLoadHigh -1.0)
		(CheckLoad Both)
		(CheckIO Both)
		(CheckDir 1)
		(CheckAssert 1)
		(CheckOutput 1)
		(UnknownLoading 0)
		(PinShape Line)
		(DIFF_PAIR_PINS_POS )
		(DIFF_PAIR_PINS_NEG )
	)

	(Pin
		(Name VCC)
		(MSB )
		(LSB )
		(Type POWER)
		(Location Top)
		(InputLoadLow )
		(InputLoadHigh )
		(OutputLoadLow )
		(OutputLoadHigh )
		(CheckLoad Off)
		(CheckIO Off)
		(CheckDir 0)
		(CheckAssert 0)
		(CheckOutput 0)
		(UnknownLoading 0)
		(PinShape )
		(DIFF_PAIR_PINS_POS )
		(DIFF_PAIR_PINS_NEG )
	)

	(Pin
		(Name D*)
		(MSB )
		(LSB )
		(Type UNSPEC)
		(Location Left)
		(InputLoadLow )
		(InputLoadHigh )
		(OutputLoadLow )
		(OutputLoadHigh )
		(CheckLoad Off)
		(CheckIO Off)
		(CheckDir 0)
		(CheckAssert 0)
		(CheckOutput 0)
		(UnknownLoading 0)
		(PinShape Line)
		(DIFF_PAIR_PINS_POS )
		(DIFF_PAIR_PINS_NEG )
	)

	(Pin
		(Name CLK*)
		(MSB )
		(LSB )
		(Type UNSPEC)
		(Location Left)
		(InputLoadLow )
		(InputLoadHigh )
		(OutputLoadLow )
		(OutputLoadHigh )
		(CheckLoad Off)
		(CheckIO Off)
		(CheckDir 0)
		(CheckAssert 0)
		(CheckOutput 0)
		(UnknownLoading 0)
		(PinShape Line)
		(DIFF_PAIR_PINS_POS )
		(DIFF_PAIR_PINS_NEG )
	)

	(Pin
		(Name Q*)
		(MSB )
		(LSB )
		(Type UNSPEC)
		(Location Right)
		(InputLoadLow )
		(InputLoadHigh )
		(OutputLoadLow )
		(OutputLoadHigh )
		(CheckLoad Off)
		(CheckIO Off)
		(CheckDir 0)
		(CheckAssert 0)
		(CheckOutput 0)
		(UnknownLoading 0)
		(PinShape Line)
		(DIFF_PAIR_PINS_POS )
		(DIFF_PAIR_PINS_NEG )
	)

)

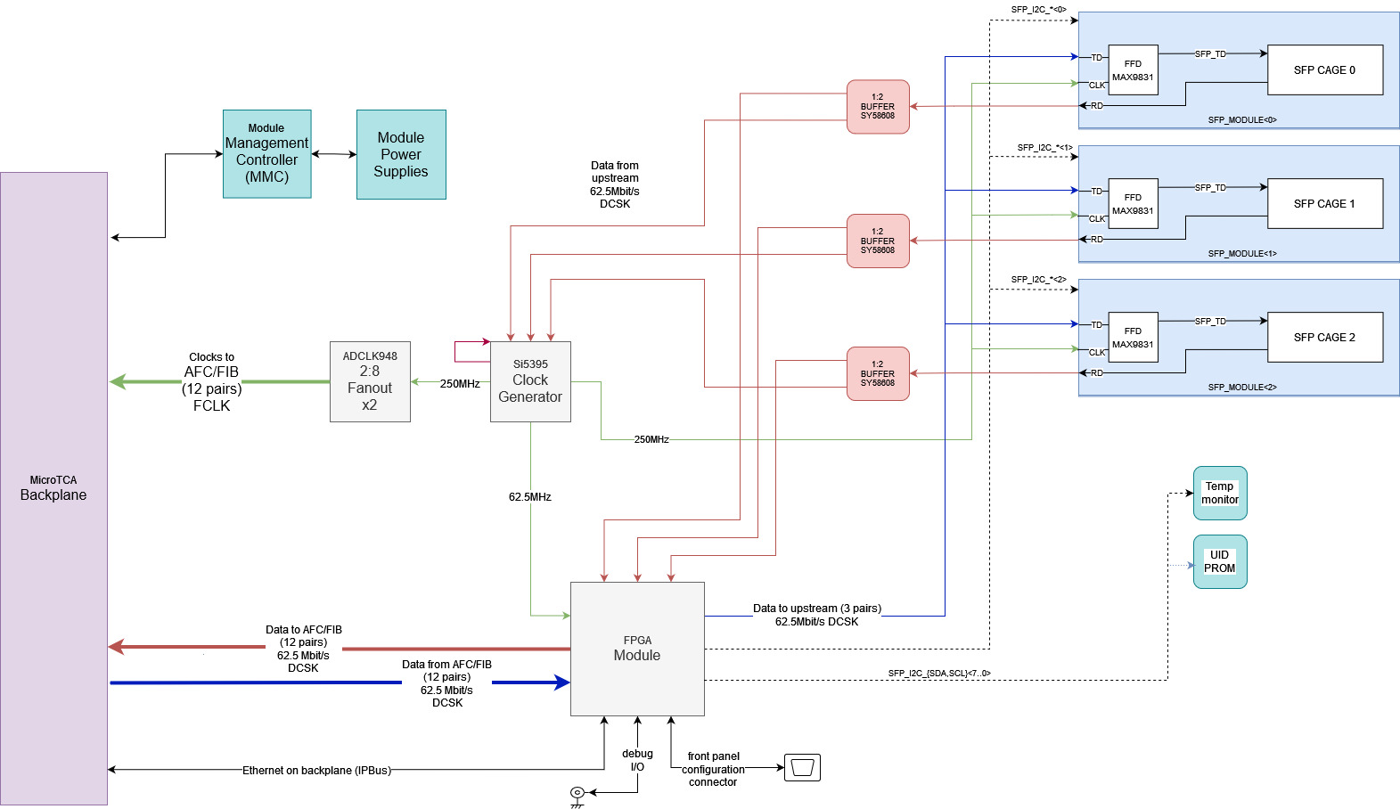
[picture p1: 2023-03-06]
hardware/Cadence/top/mtca_interface_board_reocc/top_mib_v3/images/dune_mib_v2a.jpg

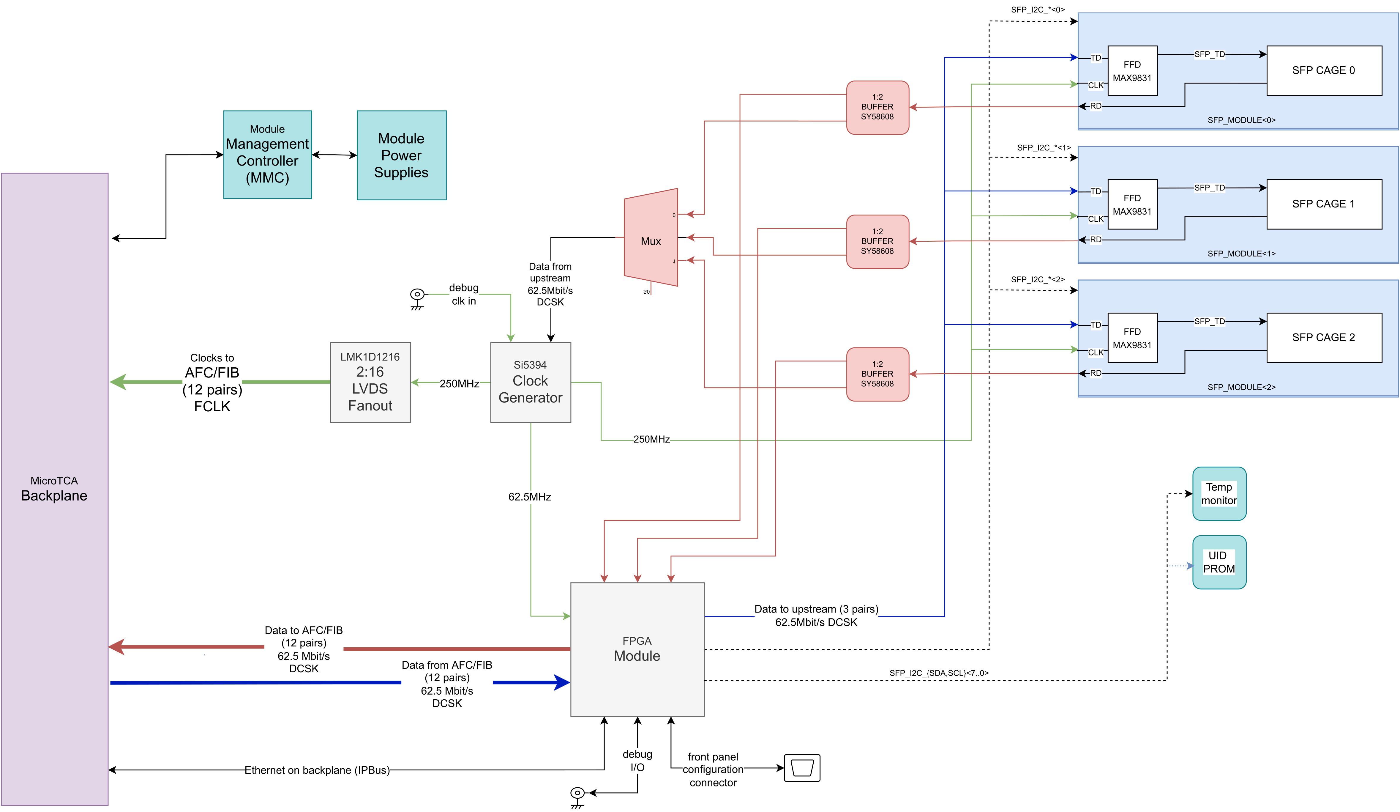
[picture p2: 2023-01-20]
hardware/Cadence/top/mtca_interface_board_reocc/top_mib_v3/images/dune_mib_v2_drawio-1.jpg

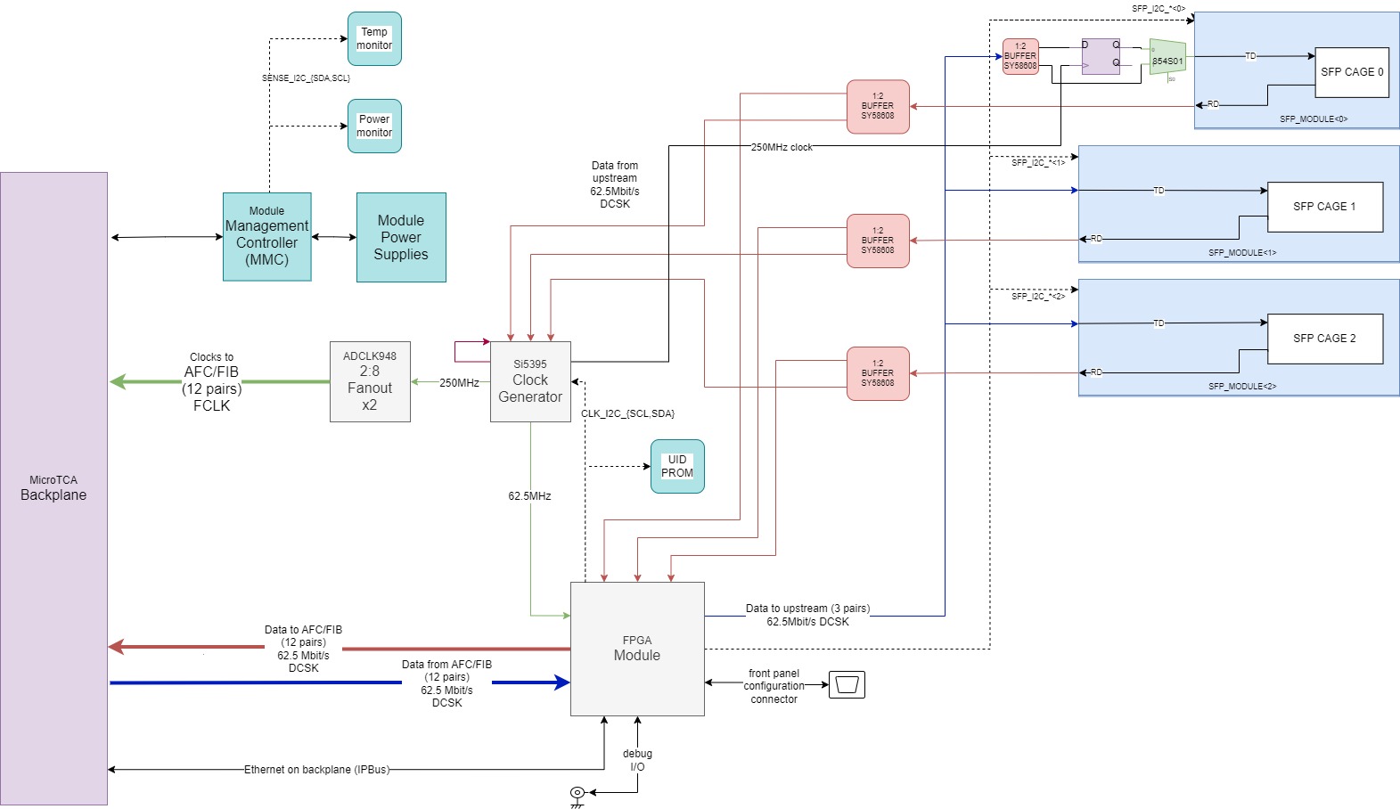
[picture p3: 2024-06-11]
hardware/Cadence/top/mtca_interface_board_reocc/top/images/dune_mib_v2b-7jun24.jpg

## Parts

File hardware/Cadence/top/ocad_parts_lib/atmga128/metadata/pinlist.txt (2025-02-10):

(Pinlist
	(Pin
		(Name AVCC)
		(MSB )
		(LSB )
		(Type BIDIR)
		(Location Right)
		(InputLoadLow -0.01)
		(InputLoadHigh 0.01)
		(OutputLoadLow 1.0)
		(OutputLoadHigh -1.0)
		(CheckLoad Both)
		(CheckIO Both)
		(CheckDir 1)
		(CheckAssert 1)
		(CheckOutput 1)
		(UnknownLoading 0)
		(PinShape )
		(DIFF_PAIR_PINS_POS )
		(DIFF_PAIR_PINS_NEG )
	)

	(Pin
		(Name AREF)
		(MSB )
		(LSB )
		(Type BIDIR)
		(Location Right)
		(InputLoadLow -0.01)
		(InputLoadHigh 0.01)
		(OutputLoadLow 1.0)
		(OutputLoadHigh -1.0)
		(CheckLoad Both)
		(CheckIO Both)
		(CheckDir 1)
		(CheckAssert 1)
		(CheckOutput 1)
		(UnknownLoading 0)
		(PinShape )
		(DIFF_PAIR_PINS_POS )
		(DIFF_PAIR_PINS_NEG )
	)

	(Pin
		(Name PF0)
		(MSB )
		(LSB )
		(Type BIDIR)
		(Location Right)
		(InputLoadLow -0.01)
		(InputLoadHigh 0.01)
		(OutputLoadLow 1.0)
		(OutputLoadHigh -1.0)
		(CheckLoad Both)
		(CheckIO Both)
		(CheckDir 1)
		(CheckAssert 1)
		(CheckOutput 1)
		(UnknownLoading 0)
		(PinShape )
		(DIFF_PAIR_PINS_POS )
		(DIFF_PAIR_PINS_NEG )
	)

	(Pin
		(Name PF1)
		(MSB )
		(LSB )
		(Type BIDIR)
		(Location Right)
		(InputLoadLow -0.01)
		(InputLoadHigh 0.01)
		(OutputLoadLow 1.0)
		(OutputLoadHigh -1.0)
		(CheckLoad Both)
		(CheckIO Both)
		(CheckDir 1)
		(CheckAssert 1)
		(CheckOutput 1)
		(UnknownLoading 0)
		(PinShape )
		(DIFF_PAIR_PINS_POS )
		(DIFF_PAIR_PINS_NEG )
	)

	(Pin
		(Name PF2)
		(MSB )
		(LSB )
		(Type BIDIR)
		(Location Right)
		(InputLoadLow -0.01)
		(InputLoadHigh 0.01)
		(OutputLoadLow 1.0)
		(OutputLoadHigh -1.0)
		(CheckLoad Both)
		(CheckIO Both)
		(CheckDir 1)
		(CheckAssert 1)
		(CheckOutput 1)
		(UnknownLoading 0)
		(PinShape )
		(DIFF_PAIR_PINS_POS )
		(DIFF_PAIR_PINS_NEG )
	)

	(Pin
		(Name PF3)
		(MSB )
		(LSB )
		(Type BIDIR)
		(Location Right)
		(InputLoadLow -0.01)
		(InputLoadHigh 0.01)
		(OutputLoadLow 1.0)
		(OutputLoadHigh -1.0)
		(CheckLoad Both)
		(CheckIO Both)
		(CheckDir 1)
		(CheckAssert 1)
		(CheckOutput 1)
		(UnknownLoading 0)
		(PinShape )
		(DIFF_PAIR_PINS_POS )
		(DIFF_PAIR_PINS_NEG )
	)

	(Pin
		(Name PF4)
		(MSB )
		(LSB )
		(Type BIDIR)
		(Location Right)
		(InputLoadLow -0.01)
		(InputLoadHigh 0.01)
		(OutputLoadLow 1.0)
		(OutputLoadHigh -1.0)
		(CheckLoad Both)
		(CheckIO Both)
		(CheckDir 1)
		(CheckAssert 1)
		(CheckOutput 1)
		(UnknownLoading 0)
		(PinShape )
		(DIFF_PAIR_PINS_POS )
		(DIFF_PAIR_PINS_NEG )
	)

	(Pin
		(Name PF5)
		(MSB )
		(LSB )
		(Type BIDIR)
		(Location Right)
		(InputLoadLow -0.01)
		(InputLoadHigh 0.01)
		(OutputLoadLow 1.0)
		(OutputLoadHigh -1.0)
		(CheckLoad Both)
		(CheckIO Both)
		(CheckDir 1)
		(CheckAssert 1)
		(CheckOutput 1)
		(UnknownLoading 0)
		(PinShape )
		(DIFF_PAIR_PINS_POS )
		(DIFF_PAIR_PINS_NEG )
	)

	(Pin
		(Name PF6)
		(MSB )
		(LSB )
		(Type BIDIR)
		(Location Right)
		(InputLoadLow -0.01)
		(InputLoadHigh 0.01)
		(OutputLoadLow 1.0)
		(OutputLoadHigh -1.0)
		(CheckLoad Both)
		(CheckIO Both)
		(CheckDir 1)
		(CheckAssert 1)
		(CheckOutput 1)
		(UnknownLoading 0)
		(PinShape )
		(DIFF_PAIR_PINS_POS )
		(DIFF_PAIR_PINS_NEG )
	)

	(Pin
		(Name PF7)
		(MSB )
		(LSB )
		(Type BIDIR)
		(Location Right)
		(InputLoadLow -0.01)
		(InputLoadHigh 0.01)
		(OutputLoadLow 1.0)
		(OutputLoadHigh -1.0)
		(CheckLoad Both)
		(CheckIO Both)
		(CheckDir 1)
		(CheckAssert 1)
		(CheckOutput 1)
		(UnknownLoading 0)
		(PinShape )
		(DIFF_PAIR_PINS_POS )
		(DIFF_PAIR_PINS_NEG )
	)

	(Pin
		(Name PA0)
		(MSB )
		(LSB )
		(Type BIDIR)
		(Location Left)
		(InputLoadLow -0.01)
		(InputLoadHigh 0.01)
		(OutputLoadLow 1.0)
		(OutputLoadHigh -1.0)
		(CheckLoad Both)
		(CheckIO Both)
		(CheckDir 1)
		(CheckAssert 1)
		(CheckOutput 1)
		(UnknownLoading 0)
		(PinShape )
		(DIFF_PAIR_PINS_POS )
		(DIFF_PAIR_PINS_NEG )
	)

	(Pin
		(Name PA1)
		(MSB )
		(LSB )
		(Type BIDIR)
		(Location Left)
		(InputLoadLow -0.01)
		(InputLoadHigh 0.01)
		(OutputLoadLow 1.0)
		(OutputLoadHigh -1.0)
		(CheckLoad Both)
		(CheckIO Both)
		(CheckDir 1)
		(CheckAssert 1)
		(CheckOutput 1)
		(UnknownLoading 0)
		(PinShape )
		(DIFF_PAIR_PINS_POS )
		(DIFF_PAIR_PINS_NEG )
	)

	(Pin
		(Name PA2)
		(MSB )
		(LSB )
		(Type BIDIR)
		(Location Left)
		(InputLoadLow -0.01)
		(InputLoadHigh 0.01)
		(OutputLoadLow 1.0)
		(OutputLoadHigh -1.0)
		(CheckLoad Both)
		(CheckIO Both)
		(CheckDir 1)
		(CheckAssert 1)
		(CheckOutput 1)
		(UnknownLoading 0)
		(PinShape )
		(DIFF_PAIR_PINS_POS )
		(DIFF_PAIR_PINS_NEG )
	)

	(Pin
		(Name PA3)
		(MSB )
		(LSB )
		(Type BIDIR)
		(Location Left)
		(InputLoadLow -0.01)
		(InputLoadHigh 0.01)
		(OutputLoadLow 1.0)
		(OutputLoadHigh -1.0)
		(CheckLoad Both)
		(CheckIO Both)
		(CheckDir 1)
		(CheckAssert 1)
		(CheckOutput 1)
		(UnknownLoading 0)
		(PinShape )
		(DIFF_PAIR_PINS_POS )
		(DIFF_PAIR_PINS_NEG )
	)

	(Pin
		(Name PA4)
		(MSB )
		(LSB )
		(Type BIDIR)
		(Location Left)
		(InputLoadLow -0.01)
		(InputLoadHigh 0.01)
		(OutputLoadLow 1.0)
		(OutputLoadHigh -1.0)
		(CheckLoad Both)
		(CheckIO Both)
		(CheckDir 1)
		(CheckAssert 1)
		(CheckOutput 1)
		(UnknownLoading 0)
		(PinShape )
		(DIFF_PAIR_PINS_POS )
		(DIFF_PAIR_PINS_NEG )
	)

	(Pin
		(Name PA5)
		(MSB )
		(LSB )
		(Type BIDIR)
		(Location Left)
		(InputLoadLow -0.01)
		(InputLoadHigh 0.01)
		(OutputLoadLow 1.0)
		(OutputLoadHigh -1.0)
		(CheckLoad Both)
		(CheckIO Both)
		(CheckDir 1)
		(CheckAssert 1)
		(CheckOutput 1)
		(UnknownLoading 0)
		(PinShape )
		(DIFF_PAIR_PINS_POS )
		(DIFF_PAIR_PINS_NEG )
	)

	(Pin
		(Name PA6)
		(MSB )
		(LSB )
		(Type BIDIR)
		(Location Left)
		(InputLoadLow -0.01)
		(InputLoadHigh 0.01)
		(OutputLoadLow 1.0)
		(OutputLoadHigh -1.0)
		(CheckLoad Both)
		(CheckIO Both)
		(CheckDir 1)
		(CheckAssert 1)
		(CheckOutput 1)
		(UnknownLoading 0)
		(PinShape )
		(DIFF_PAIR_PINS_POS )
		(DIFF_PAIR_PINS_NEG )
	)

	(Pin
		(Name PA7)
		(MSB )
		(LSB )
		(Type BIDIR)
		(Location Left)
		(InputLoadLow -0.01)
		(InputLoadHigh 0.01)
		(OutputLoadLow 1.0)
		(OutputLoadHigh -1.0)
		(CheckLoad Both)
		(CheckIO Both)
		(CheckDir 1)
		(CheckAssert 1)
		(CheckOutput 1)
		(UnknownLoading 0)
		(PinShape )
		(DIFF_PAIR_PINS_POS )
		(DIFF_PAIR_PINS_NEG )
	)

	(Pin
		(Name PG2)
		(MSB )
		(LSB )
		(Type BIDIR)
		(Location Right)
		(InputLoadLow -0.01)
		(InputLoadHigh 0.01)
		(OutputLoadLow 1.0)
		(OutputLoadHigh -1.0)
		(CheckLoad Both)
		(CheckIO Both)
		(CheckDir 1)
		(CheckAssert 1)
		(CheckOutput 1)
		(UnknownLoading 0)
		(PinShape )
		(DIFF_PAIR_PINS_POS )
		(DIFF_PAIR_PINS_NEG )
	)

	(Pin
		(Name PC7)
		(MSB )
		(LSB )
		(Type BIDIR)
		(Location Left)
		(InputLoadLow -0.01)
		(InputLoadHigh 0.01)
		(OutputLoadLow 1.0)
		(OutputLoadHigh -1.0)
		(CheckLoad Both)
		(CheckIO Both)
		(CheckDir 1)
		(CheckAssert 1)
		(CheckOutput 1)
		(UnknownLoading 0)
		(PinShape )
		(DIFF_PAIR_PINS_POS )
		(DIFF_PAIR_PINS_NEG )
	)

	(Pin
		(Name PC6)
		(MSB )
		(LSB )
		(Type BIDIR)
		(Location Left)
		(InputLoadLow -0.01)
		(InputLoadHigh 0.01)
		(OutputLoadLow 1.0)
		(OutputLoadHigh -1.0)
		(CheckLoad Both)
		(CheckIO Both)
		(CheckDir 1)
		(CheckAssert 1)
		(CheckOutput 1)
		(UnknownLoading 0)
		(PinShape )
		(DIFF_PAIR_PINS_POS )
		(DIFF_PAIR_PINS_NEG )
	)

	(Pin
		(Name PC5)
		(MSB )
		(LSB )
		(Type BIDIR)
		(Location Left)
		(InputLoadLow -0.01)
		(InputLoadHigh 0.01)
		(OutputLoadLow 1.0)
		(OutputLoadHigh -1.0)
		(CheckLoad Both)
		(CheckIO Both)
		(CheckDir 1)
		(CheckAssert 1)
		(CheckOutput 1)
		(UnknownLoading 0)
		(PinShape )
		(DIFF_PAIR_PINS_POS )
		(DIFF_PAIR_PINS_NEG )
	)

	(Pin
		(Name PC4)
		(MSB )
		(LSB )
		(Type BIDIR)
		(Location Left)
		(InputLoadLow -0.01)
		(InputLoadHigh 0.01)
		(OutputLoadLow 1.0)
		(OutputLoadHigh -1.0)
		(CheckLoad Both)
		(CheckIO Both)
		(CheckDir 1)
		(CheckAssert 1)
		(CheckOutput 1)
		(UnknownLoading 0)
		(PinShape )
		(DIFF_PAIR_PINS_POS )
		(DIFF_PAIR_PINS_NEG )
	)

	(Pin
		(Name PC3)
		(MSB )
		(LSB )
		(Type BIDIR)
		(Location Left)
		(InputLoadLow -0.01)
		(InputLoadHigh 0.01)
		(OutputLoadLow 1.0)
		(OutputLoadHigh -1.0)
		(CheckLoad Both)
		(CheckIO Both)
		(CheckDir 1)
		(CheckAssert 1)
		(CheckOutput 1)
		(UnknownLoading 0)
		(PinShape )
		(DIFF_PAIR_PINS_POS )
		(DIFF_PAIR_PINS_NEG )
	)

	(Pin
		(Name PC2)
		(MSB )
		(LSB )
		(Type BIDIR)
		(Location Left)
		(InputLoadLow -0.01)
		(InputLoadHigh 0.01)
		(OutputLoadLow 1.0)
		(OutputLoadHigh -1.0)
		(CheckLoad Both)
		(CheckIO Both)
		(CheckDir 1)
		(CheckAssert 1)
		(CheckOutput 1)
		(UnknownLoading 0)
		(PinShape )
		(DIFF_PAIR_PINS_POS )
		(DIFF_PAIR_PINS_NEG )
	)

	(Pin
		(Name PC1)
		(MSB )
		(LSB )
		(Type BIDIR)
		(Location Left)
		(InputLoadLow -0.01)
		(InputLoadHigh 0.01)
		(OutputLoadLow 1.0)
		(OutputLoadHigh -1.0)
		(CheckLoad Both)
		(CheckIO Both)
		(CheckDir 1)
		(CheckAssert 1)
		(CheckOutput 1)
		(UnknownLoading 0)
		(PinShape )
		(DIFF_PAIR_PINS_POS )
		(DIFF_PAIR_PINS_NEG )
	)

	(Pin
		(Name PC0)
		(MSB )
		(LSB )
		(Type BIDIR)
		(Location Left)
		(InputLoadLow -0.01)
		(InputLoadHigh 0.01)
		(OutputLoadLow 1.0)
		(OutputLoadHigh -1.0)
		(CheckLoad Both)
		(CheckIO Both)
		(CheckDir 1)
		(CheckAssert 1)
		(CheckOutput 1)
		(UnknownLoading 0)
		(PinShape )
		(DIFF_PAIR_PINS_POS )
		(DIFF_PAIR_PINS_NEG )
	)

	(Pin
		(Name PG1)
		(MSB )
		(LSB )
		(Type BIDIR)
		(Location Right)
		(InputLoadLow -0.01)
		(InputLoadHigh 0.01)
		(OutputLoadLow 1.0)
		(OutputLoadHigh -1.0)
		(CheckLoad Both)
		(CheckIO Both)
		(CheckDir 1)
		(CheckAssert 1)
		(CheckOutput 1)
		(UnknownLoading 0)
		(PinShape )
		(DIFF_PAIR_PINS_POS )
		(DIFF_PAIR_PINS_NEG )
	)

	(Pin
		(Name PG0)
		(MSB )
		(LSB )
		(Type BIDIR)
		(Location Right)
		(InputLoadLow -0.01)
		(InputLoadHigh 0.01)
		(OutputLoadLow 1.0)
		(OutputLoadHigh -1.0)
		(CheckLoad Both)
		(CheckIO Both)
		(CheckDir 1)
		(CheckAssert 1)
		(CheckOutput 1)
		(UnknownLoading 0)
		(PinShape )
		(DIFF_PAIR_PINS_POS )
		(DIFF_PAIR_PINS_NEG )
	)

	(Pin
		(Name PD7)
		(MSB )
		(LSB )
		(Type BIDIR)
		(Location Right)
		(InputLoadLow -0.01)
		(InputLoadHigh 0.01)
		(OutputLoadLow 1.0)
		(OutputLoadHigh -1.0)
		(CheckLoad Both)
		(CheckIO Both)
		(CheckDir 1)
		(CheckAssert 1)
		(CheckOutput 1)
		(UnknownLoading 0)
		(PinShape )
		(DIFF_PAIR_PINS_POS )
		(DIFF_PAIR_PINS_NEG )
	)

	(Pin
		(Name PD6)
		(MSB )
		(LSB )
		(Type BIDIR)
		(Location Right)
		(InputLoadLow -0.01)
		(InputLoadHigh 0.01)
		(OutputLoadLow 1.0)
		(OutputLoadHigh -1.0)
		(CheckLoad Both)
		(CheckIO Both)
		(CheckDir 1)
		(CheckAssert 1)
		(CheckOutput 1)
		(UnknownLoading 0)
		(PinShape )
		(DIFF_PAIR_PINS_POS )
		(DIFF_PAIR_PINS_NEG )
	)

	(Pin
		(Name PD5)
		(MSB )
		(LSB )
		(Type BIDIR)
		(Location Right)
		(InputLoadLow -0.01)
		(InputLoadHigh 0.01)
		(OutputLoadLow 1.0)
		(OutputLoadHigh -1.0)
		(CheckLoad Both)
		(CheckIO Both)
		(CheckDir 1)
		(CheckAssert 1)
		(CheckOutput 1)
		(UnknownLoading 0)
		(PinShape )
		(DIFF_PAIR_PINS_POS )
		(DIFF_PAIR_PINS_NEG )
	)

	(Pin
		(Name PD4)
		(MSB )
		(LSB )
		(Type BIDIR)
		(Location Right)
		(InputLoadLow -0.01)
		(InputLoadHigh 0.01)
		(OutputLoadLow 1.0)
		(OutputLoadHigh -1.0)
		(CheckLoad Both)
		(CheckIO Both)
		(CheckDir 1)
		(CheckAssert 1)
		(CheckOutput 1)
		(UnknownLoading 0)
		(PinShape )
		(DIFF_PAIR_PINS_POS )
		(DIFF_PAIR_PINS_NEG )
	)

	(Pin
		(Name PD3)
		(MSB )
		(LSB )
		(Type BIDIR)
		(Location Right)
		(InputLoadLow -0.01)
		(InputLoadHigh 0.01)
		(OutputLoadLow 1.0)
		(OutputLoadHigh -1.0)
		(CheckLoad Both)
		(CheckIO Both)
		(CheckDir 1)
		(CheckAssert 1)
		(CheckOutput 1)
		(UnknownLoading 0)
		(PinShape )
		(DIFF_PAIR_PINS_POS )
		(DIFF_PAIR_PINS_NEG )
	)

	(Pin
		(Name PD2)
		(MSB )
		(LSB )
		(Type BIDIR)
		(Location Right)
		(InputLoadLow -0.01)
		(InputLoadHigh 0.01)
		(OutputLoadLow 1.0)
		(OutputLoadHigh -1.0)
		(CheckLoad Both)
		(CheckIO Both)
		(CheckDir 1)
		(CheckAssert 1)
		(CheckOutput 1)
		(UnknownLoading 0)
		(PinShape )
		(DIFF_PAIR_PINS_POS )
		(DIFF_PAIR_PINS_NEG )
	)

	(Pin
		(Name PD1)
		(MSB )
		(LSB )
		(Type BIDIR)
		(Location Right)
		(InputLoadLow -0.01)
		(InputLoadHigh 0.01)
		(OutputLoadLow 1.0)
		(OutputLoadHigh -1.0)
		(CheckLoad Both)
		(CheckIO Both)
		(CheckDir 1)
		(CheckAssert 1)
		(CheckOutput 1)
		(UnknownLoading 0)
		(PinShape )
		(DIFF_PAIR_PINS_POS )
		(DIFF_PAIR_PINS_NEG )
	)

	(Pin
		(Name PD0)
		(MSB )
		(LSB )
		(Type BIDIR)
		(Location Right)
		(InputLoadLow -0.01)
		(InputLoadHigh 0.01)
		(OutputLoadLow 1.0)
		(OutputLoadHigh -1.0)
		(CheckLoad Both)
		(CheckIO Both)
		(CheckDir 1)
		(CheckAssert 1)
		(CheckOutput 1)
		(UnknownLoading 0)
		(PinShape )
		(DIFF_PAIR_PINS_POS )
		(DIFF_PAIR_PINS_NEG )
	)

	(Pin
		(Name XTAL1)
		(MSB )
		(LSB )
		(Type BIDIR)
		(Location Left)
		(InputLoadLow -0.01)
		(InputLoadHigh 0.01)
		(OutputLoadLow 1.0)
		(OutputLoadHigh -1.0)
		(CheckLoad Both)
		(CheckIO Both)
		(CheckDir 1)
		(CheckAssert 1)
		(CheckOutput 1)
		(UnknownLoading 0)
		(PinShape )
		(DIFF_PAIR_PINS_POS )
		(DIFF_PAIR_PINS_NEG )
	)

	(Pin
		(Name XTAL2)
		(MSB )
		(LSB )
		(Type BIDIR)
		(Location Left)
		(InputLoadLow -0.01)
		(InputLoadHigh 0.01)
		(OutputLoadLow 1.0)
		(OutputLoadHigh -1.0)
		(CheckLoad Both)
		(CheckIO Both)
		(CheckDir 1)
		(CheckAssert 1)
		(CheckOutput 1)
		(UnknownLoading 0)
		(PinShape )
		(DIFF_PAIR_PINS_POS )
		(DIFF_PAIR_PINS_NEG )
	)

	(Pin
		(Name RESET*)
		(MSB )
		(LSB )
		(Type BIDIR)
		(Location Left)
		(InputLoadLow -0.01)
		(InputLoadHigh 0.01)
		(OutputLoadLow 1.0)
		(OutputLoadHigh -1.0)
		(CheckLoad Both)
		(CheckIO Both)
		(CheckDir 1)
		(CheckAssert 1)
		(CheckOutput 1)
		(UnknownLoading 0)
		(PinShape Dot)
		(DIFF_PAIR_PINS_POS )
		(DIFF_PAIR_PINS_NEG )
	)

	(Pin
		(Name PG4)
		(MSB )
		(LSB )
		(Type BIDIR)
		(Location Right)
		(InputLoadLow -0.01)
		(InputLoadHigh 0.01)
		(OutputLoadLow 1.0)
		(OutputLoadHigh -1.0)
		(CheckLoad Both)
		(CheckIO Both)
		(CheckDir 1)
		(CheckAssert 1)
		(CheckOutput 1)
		(UnknownLoading 0)
		(PinShape )
		(DIFF_PAIR_PINS_POS )
		(DIFF_PAIR_PINS_NEG )
	)

	(Pin
		(Name PG3)
		(MSB )
		(LSB )
		(Type BIDIR)
		(Location Right)
		(InputLoadLow -0.01)
		(InputLoadHigh 0.01)
		(OutputLoadLow 1.0)
		(OutputLoadHigh -1.0)
		(CheckLoad Both)
		(CheckIO Both)
		(CheckDir 1)
		(CheckAssert 1)
		(CheckOutput 1)
		(UnknownLoading 0)
		(PinShape )
		(DIFF_PAIR_PINS_POS )
		(DIFF_PAIR_PINS_NEG )
	)

	(Pin
		(Name PB7)
		(MSB )
		(LSB )
		(Type BIDIR)
		(Location Left)
		(InputLoadLow -0.01)
		(InputLoadHigh 0.01)
		(OutputLoadLow 1.0)
		(OutputLoadHigh -1.0)
		(CheckLoad Both)
		(CheckIO Both)
		(CheckDir 1)
		(CheckAssert 1)
		(CheckOutput 1)
		(UnknownLoading 0)
		(PinShape )
		(DIFF_PAIR_PINS_POS )
		(DIFF_PAIR_PINS_NEG )
	)

	(Pin
		(Name PB6)
		(MSB )
		(LSB )
		(Type BIDIR)
		(Location Left)
		(InputLoadLow -0.01)
		(InputLoadHigh 0.01)
		(OutputLoadLow 1.0)
		(OutputLoadHigh -1.0)
		(CheckLoad Both)
		(CheckIO Both)
		(CheckDir 1)
		(CheckAssert 1)
		(CheckOutput 1)
		(UnknownLoading 0)
		(PinShape )
		(DIFF_PAIR_PINS_POS )
		(DIFF_PAIR_PINS_NEG )
	)

	(Pin
		(Name PB5)
		(MSB )
		(LSB )
		(Type BIDIR)
		(Location Left)
		(InputLoadLow -0.01)
		(InputLoadHigh 0.01)
		(OutputLoadLow 1.0)
		(OutputLoadHigh -1.0)
		(CheckLoad Both)
		(CheckIO Both)
		(CheckDir 1)
		(CheckAssert 1)
		(CheckOutput 1)
		(UnknownLoading 0)
		(PinShape )
		(DIFF_PAIR_PINS_POS )
		(DIFF_PAIR_PINS_NEG )
	)

	(Pin
		(Name PB4)
		(MSB )
		(LSB )
		(Type BIDIR)
		(Location Left)
		(InputLoadLow -0.01)
		(InputLoadHigh 0.01)
		(OutputLoadLow 1.0)
		(OutputLoadHigh -1.0)
		(CheckLoad Both)
		(CheckIO Both)
		(CheckDir 1)
		(CheckAssert 1)
		(CheckOutput 1)
		(UnknownLoading 0)
		(PinShape )
		(DIFF_PAIR_PINS_POS )
		(DIFF_PAIR_PINS_NEG )
	)

	(Pin
		(Name PB3)
		(MSB )
		(LSB )
		(Type BIDIR)
		(Location Left)
		(InputLoadLow -0.01)
		(InputLoadHigh 0.01)
		(OutputLoadLow 1.0)
		(OutputLoadHigh -1.0)
		(CheckLoad Both)
		(CheckIO Both)
		(CheckDir 1)
		(CheckAssert 1)
		(CheckOutput 1)
		(UnknownLoading 0)
		(PinShape )
		(DIFF_PAIR_PINS_POS )
		(DIFF_PAIR_PINS_NEG )
	)

	(Pin
		(Name PB2)
		(MSB )
		(LSB )
		(Type BIDIR)
		(Location Left)
		(InputLoadLow -0.01)
		(InputLoadHigh 0.01)
		(OutputLoadLow 1.0)
		(OutputLoadHigh -1.0)
		(CheckLoad Both)
		(CheckIO Both)
		(CheckDir 1)
		(CheckAssert 1)
		(CheckOutput 1)
		(UnknownLoading 0)
		(PinShape )
		(DIFF_PAIR_PINS_POS )
		(DIFF_PAIR_PINS_NEG )
	)

	(Pin
		(Name PB1)
		(MSB )
		(LSB )
		(Type BIDIR)
		(Location Left)
		(InputLoadLow -0.01)
		(InputLoadHigh 0.01)
		(OutputLoadLow 1.0)
		(OutputLoadHigh -1.0)
		(CheckLoad Both)
		(CheckIO Both)
		(CheckDir 1)
		(CheckAssert 1)
		(CheckOutput 1)
		(UnknownLoading 0)
		(PinShape )
		(DIFF_PAIR_PINS_POS )
		(DIFF_PAIR_PINS_NEG )
	)

	(Pin
		(Name PB0)
		(MSB )
		(LSB )
		(Type BIDIR)
		(Location Left)
		(InputLoadLow -0.01)
		(InputLoadHigh 0.01)
		(OutputLoadLow 1.0)
		(OutputLoadHigh -1.0)
		(CheckLoad Both)
		(CheckIO Both)
		(CheckDir 1)
		(CheckAssert 1)
		(CheckOutput 1)
		(UnknownLoading 0)
		(PinShape )
		(DIFF_PAIR_PINS_POS )
		(DIFF_PAIR_PINS_NEG )
	)

	(Pin
		(Name PE7)
		(MSB )
		(LSB )
		(Type BIDIR)
		(Location Right)
		(InputLoadLow -0.01)
		(InputLoadHigh 0.01)
		(OutputLoadLow 1.0)
		(OutputLoadHigh -1.0)
		(CheckLoad Both)
		(CheckIO Both)
		(CheckDir 1)
		(CheckAssert 1)
		(CheckOutput 1)
		(UnknownLoading 0)
		(PinShape )
		(DIFF_PAIR_PINS_POS )
		(DIFF_PAIR_PINS_NEG )
	)

	(Pin
		(Name PE6)
		(MSB )
		(LSB )
		(Type BIDIR)
		(Location Right)
		(InputLoadLow -0.01)
		(InputLoadHigh 0.01)
		(OutputLoadLow 1.0)
		(OutputLoadHigh -1.0)
		(CheckLoad Both)
		(CheckIO Both)
		(CheckDir 1)
		(CheckAssert 1)
		(CheckOutput 1)
		(UnknownLoading 0)
		(PinShape )
		(DIFF_PAIR_PINS_POS )
		(DIFF_PAIR_PINS_NEG )
	)

	(Pin
		(Name PE5)
		(MSB )
		(LSB )
		(Type BIDIR)
		(Location Right)
		(InputLoadLow -0.01)
		(InputLoadHigh 0.01)
		(OutputLoadLow 1.0)
		(OutputLoadHigh -1.0)
		(CheckLoad Both)
		(CheckIO Both)
		(CheckDir 1)
		(CheckAssert 1)
		(CheckOutput 1)
		(UnknownLoading 0)
		(PinShape )
		(DIFF_PAIR_PINS_POS )
		(DIFF_PAIR_PINS_NEG )
	)

	(Pin
		(Name PE4)
		(MSB )
		(LSB )
		(Type BIDIR)
		(Location Right)
		(InputLoadLow -0.01)
		(InputLoadHigh 0.01)
		(OutputLoadLow 1.0)
		(OutputLoadHigh -1.0)
		(CheckLoad Both)
		(CheckIO Both)
		(CheckDir 1)
		(CheckAssert 1)
		(CheckOutput 1)
		(UnknownLoading 0)
		(PinShape )
		(DIFF_PAIR_PINS_POS )
		(DIFF_PAIR_PINS_NEG )
	)

	(Pin
		(Name PE3)
		(MSB )
		(LSB )
		(Type BIDIR)
		(Location Right)
		(InputLoadLow -0.01)
		(InputLoadHigh 0.01)
		(OutputLoadLow 1.0)
		(OutputLoadHigh -1.0)
		(CheckLoad Both)
		(CheckIO Both)
		(CheckDir 1)
		(CheckAssert 1)
		(CheckOutput 1)
		(UnknownLoading 0)
		(PinShape )
		(DIFF_PAIR_PINS_POS )
		(DIFF_PAIR_PINS_NEG )
	)

	(Pin
		(Name PE2)
		(MSB )
		(LSB )
		(Type BIDIR)
		(Location Right)
		(InputLoadLow -0.01)
		(InputLoadHigh 0.01)
		(OutputLoadLow 1.0)
		(OutputLoadHigh -1.0)
		(CheckLoad Both)
		(CheckIO Both)
		(CheckDir 1)
		(CheckAssert 1)
		(CheckOutput 1)
		(UnknownLoading 0)
		(PinShape )
		(DIFF_PAIR_PINS_POS )
		(DIFF_PAIR_PINS_NEG )
	)

	(Pin
		(Name PE1)
		(MSB )
		(LSB )
		(Type BIDIR)
		(Location Right)
		(InputLoadLow -0.01)
		(InputLoadHigh 0.01)
		(OutputLoadLow 1.0)
		(OutputLoadHigh -1.0)
		(CheckLoad Both)
		(CheckIO Both)
		(CheckDir 1)
		(CheckAssert 1)
		(CheckOutput 1)
		(UnknownLoading 0)
		(PinShape )
		(DIFF_PAIR_PINS_POS )
		(DIFF_PAIR_PINS_NEG )
	)

	(Pin
		(Name PE0)
		(MSB )
		(LSB )
		(Type BIDIR)
		(Location Right)
		(InputLoadLow -0.01)
		(InputLoadHigh 0.01)
		(OutputLoadLow 1.0)
		(OutputLoadHigh -1.0)
		(CheckLoad Both)
		(CheckIO Both)
		(CheckDir 1)
		(CheckAssert 1)
		(CheckOutput 1)
		(UnknownLoading 0)
		(PinShape )
		(DIFF_PAIR_PINS_POS )
		(DIFF_PAIR_PINS_NEG )
	)

	(Pin
		(Name PEN*)
		(MSB )
		(LSB )
		(Type BIDIR)
		(Location Left)
		(InputLoadLow -0.01)
		(InputLoadHigh 0.01)
		(OutputLoadLow 1.0)
		(OutputLoadHigh -1.0)
		(CheckLoad Both)
		(CheckIO Both)
		(CheckDir 1)
		(CheckAssert 1)
		(CheckOutput 1)
		(UnknownLoading 0)
		(PinShape Dot)
		(DIFF_PAIR_PINS_POS )
		(DIFF_PAIR_PINS_NEG )
	)

	(Pin
		(Name VCC2)
		(MSB )
		(LSB )
		(Type POWER)
		(Location Top)
		(InputLoadLow )
		(InputLoadHigh )
		(OutputLoadLow )
		(OutputLoadHigh )
		(CheckLoad Both)
		(CheckIO Both)
		(CheckDir 1)
		(CheckAssert 1)
		(CheckOutput 1)
		(UnknownLoading 0)
		(PinShape )
		(DIFF_PAIR_PINS_POS )
		(DIFF_PAIR_PINS_NEG )
	)

	(Pin
		(Name VCC1)
		(MSB )
		(LSB )
		(Type POWER)
		(Location Top)
		(InputLoadLow )
		(InputLoadHigh )
		(OutputLoadLow )
		(OutputLoadHigh )
		(CheckLoad Both)
		(CheckIO Both)
		(CheckDir 1)
		(CheckAssert 1)
		(CheckOutput 1)
		(UnknownLoading 0)
		(PinShape )
		(DIFF_PAIR_PINS_POS )
		(DIFF_PAIR_PINS_NEG )
	)

	(Pin
		(Name GND3)
		(MSB )
		(LSB )
		(Type GROUND)
		(Location Bottom)
		(InputLoadLow )
		(InputLoadHigh )
		(OutputLoadLow )
		(OutputLoadHigh )
		(CheckLoad Both)
		(CheckIO Both)
		(CheckDir 1)
		(CheckAssert 1)
		(CheckOutput 1)
		(UnknownLoading 0)
		(PinShape )
		(DIFF_PAIR_PINS_POS )
		(DIFF_PAIR_PINS_NEG )
	)

	(Pin
		(Name GND2)
		(MSB )
		(LSB )
		(Type GROUND)
		(Location Bottom)
		(InputLoadLow )
		(InputLoadHigh )
		(OutputLoadLow )
		(OutputLoadHigh )
		(CheckLoad Both)
		(CheckIO Both)
		(CheckDir 1)
		(CheckAssert 1)
		(CheckOutput 1)
		(UnknownLoading 0)
		(PinShape )
		(DIFF_PAIR_PINS_POS )
		(DIFF_PAIR_PINS_NEG )
	)

	(Pin
		(Name GND1)
		(MSB )
		(LSB )
		(Type GROUND)
		(Location Bottom)
		(InputLoadLow )
		(InputLoadHigh )
		(OutputLoadLow )
		(OutputLoadHigh )
		(CheckLoad Both)
		(CheckIO Both)
		(CheckDir 1)
		(CheckAssert 1)
		(CheckOutput 1)
		(UnknownLoading 0)
		(PinShape )
		(DIFF_PAIR_PINS_POS )
		(DIFF_PAIR_PINS_NEG )
	)

)

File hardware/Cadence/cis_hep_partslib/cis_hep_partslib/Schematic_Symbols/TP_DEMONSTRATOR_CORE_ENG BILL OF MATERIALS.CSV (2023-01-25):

Item Number | Quantity | Value | Voltage | Tolerance | Description | Part Number | Part Reference
1 | 2 | 5.0PF | 50V |  | CAP 5.0PF 50V CERAMIC 0402 SMD | PCC050CQTR-ND | C1 C2
2 | 2 | 12PF | 50V |  | CAP 12PF 50V CERAMIC 0402 SMD | PCC120CQTR-ND | CB1 CB4
3 | 6 | 4.7UF | 6.3V |  | CAP CER 4.7UF 6.3V X5R 0402 | GRM155R60J475ME87D | CB2 CB18 CB70 CB164 CT2 CT3
4 | 139 | 0.1UF | 25V |  | CAP 0.1µF ±10% 25V Ceramic Capacitor X7R 0402 | C1005X7R1E104K050BB | CB3 CB5-CB15 CB17 CB19 CB20 CB22 CB23 CB28 CB30 CB31 CB33 CB34 CB39 CB40 CB45 CB48 CB52 CB54 CB55 CB57 CB61 CB62 CB71 CB75 CB77 CB89 CB90 CB93-CB95 CB100 CB102 CB104 CB106 CB158 CB161-CB163 CB165-CB169 CB395 CB664 CB678 CB681 CB689 CB690 CB693 CB702 CB710 CB711 CB719 CB727 CB731 CB735 CB737 CB744 CB757 CB769 CB770 CB773-CB775 CB777-CB780 CB782-CB784 CB791 CB797-CB799 CB802 CB803 CB812 CB813 CB820 CB821 CB824 CB827 CB829 CB831 CB832 CT1 CT20 CT22 CT27 CT33 CT42-CT45 CT56-CT61 CT68-CT70 CT72 CT74 CT76 CT78 CT90 CT94 CT102 CT104 CT112 CT113 CT116 CT123 CT130 CT135 CT138-CT140 CT143 CT144 CT157 CT160 CT161 CT169 CT170
5 | 5 | 10UF | 25V |  | CAP 10µF ±10% 25V Ceramic Capacitor X5R 0603 | C1608X5R1E106M080AC | CB16 CB816 CB819 CB825 CT18
6 | 15 | 10UF | 10V |  | CAP CER 10UF 10V X5R 0402 | CL05A106MP5NUNC | CB21 CB27 CB53 CB730 CB758 CB765 CB768 CB818 CB822 CT91 CT93 CT125 CT136 CT137 CT141
7 | 186 | 0.1UF | 25V | 10% | CAP CER 0.1UF 25V X5R 0201 | GRM033R61E104KE14J | CB24 CB25 CB35-CB38 CB41 CB42 CB46 CB47 CB49 CB51 CB56 CB58-CB60 CB63-CB66 CB68 CB69 CB72 CB74 CB76 CB78-CB82 CB85-CB88 CB91 CB92 CB126 CB131 CB159 CB160 CB366 CB368 CB396 CB410 CB436 CB437 CB449 CB450 CB465 CB478 CB508 CB523-CB525 CB536 CB549 CB575-CB577 CB590 CB601 CB602 CB613 CB614 CB624 CB632 CB633 CB635-CB650 CB656 CB657 CB659 CB665 CB666 CB668 CB670 CB673-CB676 CB679 CB682 CB684-CB687 CB691 CB692 CB695 CB696 CB698 CB699 CB701 CB703 CB705 CB706 CB708 CB709 CB713 CB715-CB717 CB720-CB722 CB724 CB725 CB728 CB729 CB732 CB734 CB736 CB740 CB743 CB763 CB764 CB766 CB767 CT6 CT7 CT9 CT11-CT17 CT21 CT23 CT24 CT34-CT41 CT80-CT87 CT96-CT101 CT103 CT105 CT106 CT109 CT110 CT117 CT118 CT120-CT122 CT124 CT126 CT132-CT134 CT145 CT146 CT151 CT152
8 | 25 | 1UF | 25V |  | CAP CER 1UF 25V X5R 0402 | GRT155R61E105ME01D | CB26 CB29 CB32 CB101 CB103 CB105 CB107 CB809 CB810 CB823 CB833 CT19 CT25 CT50-CT52 CT54 CT62-CT65 CT71 CT73 CT75 CT77
9 | 4 | 10UF | 50V | 20% | CAP CER 10UF 50V X5R 1206 | GRT31CR61H106ME01L | CB43 CB44 CB67 CB73
10 | 13 | 10UF | 10V | 10% | CAP CER 10UF 10V X5R 0603 | GRM188R61A106KE69D | CB50 CB96-CB99 CB771 CB776 CT32 CT46-CT48 CT53 CT55
11 | 14 | 22UF | 25V | 20% | CAP CER 22UF 25V X5R 0805 | GRT21BR61E226ME13L | CB83 CB84 CB677 CB718 CB814 CB815 CT67 CT89 CT108 CT142 CT153 CT154 CT167 CT168
12 | 48 | 0.01UF | 25V | 10% | CAP CER 10000PF 25V X5R 0201 | GRM033R61E103KA12D | CB108-CB125 CB127-CB130 CB132-CB157
13 | 11 | 470UF | 2V | 20% | CAP ALUM POLY 470UF 20% 2V SMD | EEF-GX0D471R | CB170 CB479 CB634 CB748 CB756 CT127-CT129 CT148-CT150
14 | 427 | 4.7UF | 4V | 20% | CAP CER 4.7UF 4V X6S 0402 | C1005X6S0G475M050BC | CB171-CB216 CB218-CB256 CB258-CB313 CB315-CB338 CB341-CB365 CB369-CB380 CB382-CB394 CB397-CB409 CB411-CB435 CB438-CB448 CB451-CB464 CB466-CB477 CB480-CB507 CB509-CB522 CB526-CB535 CB537-CB548 CB550-CB574 CB578-CB589 CB591-CB600 CB603-CB612 CB615-CB623 CB625-CB631
15 | 16 | 47UF | 6.3V | 20% | CAP CER 47UF 6.3V X6S 1206 | GRM31CC80J476ME18L | CB217 CB257 CB314 CB658 CB662 CB667 CB672 CB680 CB739 CB742 CB754 CB755 CB805-CB808
16 | 13 | 0.47UF | 16V |  | CAP CER 0.47UF 16V X6S 0402 | GRT155C81C474ME01D | CB339 CB340 CB367 CB381 CB652-CB655 CB738 CB741 CB746 CB747 CB749
17 | 15 | 100UF | 4V | 20% | CAP CER 100UF 4V X6S 1206 | C3216X6S0G107M160AC | CB651 CB694 CB704 CB714 CB723 CB733 CB750-CB753 CB759-CB762 CT147
18 | 22 | 100UF | 6.3V | 20% | CAP CER 100UF 6.3V X6T 1206 | GRM31CD80J107ME39K | CB660 CB661 CB671 CB688 CB726 CB781 CB789 CB790 CB795 CB800 CB811 CB817 CT49 CT88 CT95 CT111 CT114 CT115 CT131 CT162-CT164
19 | 3 | 47UF | 6.3V | 20% | CAP CER 47UF 6.3V X6S 1210 | C3225X6S0J476M250AC | CB663 CT165 CT166
20 | 2 | 1000pF | 2000V (2kV) | 10% | CAP CER 1000PF 2KV X7R 1206 | C1206C102KGRACAUTO | CB669 CB745
21 | 2 | 4.7UF | 10V | 20% | CAP CER 4.7UF 10V X5R 0603 | C0603C475M8PACTU | CB683 CB804
22 | 6 | DNP | 25V | 10% | CAP CER 10000PF 25V X7R 0402 | C0402C103K3RACTU | CB697 CB707 CB712 CB788 CB792 CB796
23 | 2 | 100PF | 50V |  | CAP 100PF 50V CERAMIC 0402 SMD | PCC101CQTR-ND | CB700 CB801
24 | 1 | 470UF | 6.3V | 20% | CAP TANT POLY 470UF 6.3V 2917 | 6TPE470MAZU | CB772
25 | 7 | 47UF | 10V |  | CAP CER 47UF 10V X5R 0805 | LMK212BBJ476MG-T | CB785 CB786 CB793 CB794 CB826 CB828 CT26
26 | 1 | 150PF | 25V |  | CAP CER 150PF 25V C0G/NP0 0402 | GRM1555C1E151JA01D | CB787
27 | 1 | 1000PF | 50V | 20% | CAP CER 1000PF 50V X7R 0402 | CC0402KRX7R9BB102 | CB830
28 | 3 | 0.01UF | 25V |  | CAP CER 10000PF 25V X5R 0402 | C1005X5R1E103K050BA | CT4 CT5 CT10
29 | 1 | 100UF | 100V | 20% | 100µF 100V Aluminum Electrolytic Capacitors Radial, Can 2000 Hrs @ 105°C | URY2A101MHD1TO | CT8
30 | 4 | 330UF | 100V | 20% | CAP ALUM 330UF 20% 100V RADIAL | UHE2A331MHD6 | CT28 CT79 CT155 CT156
31 | 2 | 2700UF | 25V | 20% | CAP ALUM 2700UF 20% 25V RADIAL | EEU-FR1E272SB | CT29 CT30
32 | 1 | 1UF | 6.3V |  | CAP CER 1UF 6.3V X5R 0402 | GRM152R60J105ME15D | CT31
33 | 1 | 1UF | 25V |  | CAP CER 1UF 25V X7R 0603 | C1608X7R1E105M080AB | CT66
34 | 5 | 470UF | 6.3V | 20% | CAP ALUM 470UF 20% 6.3V SMD | EEE-FKJ471XSP | CT92 CT107 CT119 CT158 CT159
35 | 10 | PGB1010603NR |  |  | TVS DIODE 24V 150V 0603 | PGB1010603NR | DB1-DB6 DB11-DB14
36 | 4 | LTST-S270KRKT |  |  | LED RED CLEAR CHIP SMD R/A | LTST-S270KRKT | DB7 DB10 DB19 DB21
37 | 1 | BAS40SL |  |  | Diode Schottky 40V 100mA Surface Mount SOD-923F | BAS40SL | DB8
38 | 6 | LTST-S270KGKT |  |  | LED GREEN CLEAR CHIP SMD R/A | LTST-S270KGKT | DB9 DB15-DB18 DB20
39 | 1 | LTST-S270TBKT |  |  | LED BLUE CLEAR CHIP SMD R/A | LTST-S270TBKT | DB22
40 | 2 | 15A |  |  | FUSE BRD MNT 15A 65VAC/VDC 2SMD | 0448015.MR | FT1 FT2
41 | 4 | 1A |  |  | FUSE BRD MNT 1A 125VAC/VDC 2SMD | 0448001.MR | FT3-FT5 FT8
42 | 2 | 20A |  |  | FUSE BRD MNT 20A 65VAC/VDC 2410 | 2410SFV20.0FM/065-2 | FT6 FT7
43 | 2 | ZA8H-24-0.33-Z-07 |  |  | HIGH-SPEED DUAL COMPRESSION ARRAYS | ZA8H-24-0.33-Z-07_pwr | J1 J5
44 | 2 | ZA8H-24-0.33-Z-07 |  |  | HIGH-SPEED DUAL COMPRESSION ARRAYS | ZA8H-24-0.33-Z-07_B | J2 J6
45 | 4 | ZA8H-24-0.33-Z-07 |  |  | HIGH-SPEED DUAL COMPRESSION ARRAYS | ZA8H-24-0.33-Z-07_A | J3 J4 J7 J8
46 | 9 | HDR1x3 |  |  | CONN3, Header,TH | M20-9990345 | J9 J10 J14 J17-J19 J24 J30 J31
47 | 2 | 7x2RECPT_SMD_2mm |  |  | CONN HEADER SMD 14POS 2MM | 878321420 | J11 J13
48 | 1 | Hdr2x3_SM |  |  | CONN6, Header,SM | Hdr2x3_SM | J12
49 | 1 | HDR1x2 |  |  | CONN2, Header,TH | 77311-118-02LF | J15
50 | 1 | RJMG20162141BER |  |  | CONN MAGJACK 1PORT 1000 BASE-T | RJMG20162141BER | J16
51 | 4 | 2065657-1 |  |  | CONN RCPT HI SPEED 120P EDGE MT | TE-2065657-1 | J20-J23
52 | 2 | EBTF-4-10-2.0-RA-1 |  |  | CONN RCPT EXAMAX 80POS PCB | EBTF-4-10-2.0-RA-1 | J25 J26
53 | 2 | FX10A-168P-SV(71) |  |  | CONN HEADER 168POS W/POST SMD | FX10A-168P-SV(71) | J27 J29
54 | 1 | 87782-3003 |  |  | CONN SKT MINIDIMM 244POS SMD | 87782-3003 | J28
55 | 3 | 10118194-0001LF |  |  | CONN RCPT HI SPEED 120P EDGE MT | 10118194-0001LF | J32-J34
56 | 2 | 600 Ohm@100MHz |  | 25 % | 600 Ohms @ 100MHz 1 Signal Line Ferrite Bead 0603 (1608 Metric) 500mA 400mOhm | MMZ1608Y601BTA00 | LB1 LT1
57 | 11 | 1000ohm |  | 25% | Ferrite Bead, 1000ohm, 25%, 250mA, 0402 | BLM15HD102SN1D | LB2-LB4 LB11-LB13 LT4-LT8
58 | 4 | 220 Ohm |  | 25 % | 220 Ohms @ 100MHz 1 Ferrite Bead 0402 (1005 Metric) 450mA 290mOhm | BLM15AG221SN1D | LB5 LB6 LT2 LT3
59 | 2 | 600 Ohm@100MHz |  | 25 % | 600 Ohms @ 100MHz 1 Signal Line Ferrite Bead 0805 (2012 Metric) 500mA 300mOhm | HZ0805E601R-10 | LB7 LB8
60 | 2 | 30 Ohm@100MHz |  | 25 % | 30 Ohms @ 100MHz 1 Power Line Ferrite Bead 0805 (2012 Metric) 4A 14mOhm | BLM21PG300SZ1D | LB9 LB10
61 | 19 | Mt_Hole |  |  | PCB MOUNT-HOLE PAD200C_128 DRILL | Mt_Hole | MH1-MH19
62 | 9 | DNP |  | - | SHUNT 2.54MM PITCH | MSDA-G | MJB1-MJB9
63 | 1 | 120943-1 |  |  | CONN RCPT BLADE PWR 3POS EDGE MT | TE-120943-1 | P2
64 | 1 | 1766500-1 |  |  | CONN PLUG ATCA 34POS PCB | 1766500-1 | P10
65 | 4 | BSS138K |  |  | MOSFET N-CH 50V 220MA SOT-23-3 | BSS138K | QB1-QB4
66 | 1 | BSC016N03LS G |  |  | MOSFET N-Ch 30V 100A TDSON-8 OptiMOS 3 | BSC016N03LS G | QT1
67 | 1 | DNE |  |  | P-Channel 30V 4A (Ta) 1.4W (Ta) Surface Mount SOT-23-3L | AO3401A | QT2
68 | 3 | 499 Ohm |  | 1 % | RES SMD 499 OHM 1% 1/10W 0402 | ERJ-2RKF4990X | R1 R2 RB138
69 | 35 | 49.9 |  | 1% | RES SMD 49.9 OHM 1% 1/16W 0402 | RC0402FR-0749R9L | R3 R4 RB38 RB39 RB41 RB43 RB46-RB48 RB50 RB52 RB54 RB56 RB57 RB163 RB164 RB167 RB169 RB173 RB176 RB182 RB184 RB188 RB189 RB191 RB192 RB198 RB199 RB201 RB202 RB240-RB244
70 | 24 | 24.9 |  | 1% | RES SMD 24.9 OHM 1% 1/16W 0402 | RC0402FR-0724R9L | RB1-RB4 RB7-RB10 RB13-RB16 RB23 RB24 RB27 RB29 RB31-RB33 RB35 RB219-RB222
71 | 39 | 10K |  | 1% | RES SMD 10K OHM 1% 1/20W 0402 | M55342K11B10E0RS3 | RB5 RB17 RB18 RB20-RB22 RB26 RB34 RB42 RB44 RB79 RB80 RB84 RB86 RB87 RB105 RB108 RB110 RB114 RB116-RB124 RB140 RB168 RB181 RB207 RB208 RB226 RB235 RB238 RB252 RT21 RT40
72 | 35 | 2.2k |  | 1% | RES SMD 2.2K OHM 1% 1/10W 0402 | ERJ-2RKF2201X | RB6 RB51 RB55 RB58 RB60-RB62 RB64 RB68-RB72 RB74-RB77 RB195 RB197 RB203 RB223 RB224 RT9 RT11-RT13 RT17-RT20 RT24 RT25 RT35-RT37
73 | 2 | 499 Ohm |  | 1.0 % | RES, Thick Film, 499 Ohm, 1.0 %, 1/16 W, SMD, 0402 | CRCW0402499RFKEE | RB11 RB12
74 | 2 | 150 |  | 1% | RES SMD 150 OHM 1% 1/20W 0201 | ERJ-1GNF1500C | RB19 RB40
75 | 1 | 39k |  | 1% | RES SMD 39K OHM 0.1% 1/16W 0402 | ERA-2AEB393X | RB25
76 | 7 | 100 |  | 1% | RES SMD 100 OHM 1% 1/10W 0402 | ERJ-2RKF1000X | RB28 RB133 RB134 RB136 RB137 RB142 RB143
77 | 1 | 422 Ohm |  | 1 % | RES SMD 422 OHM 1% 1/10W 0402 | ERJ-2RKF4220X | RB30
78 | 1 | 6.81k |  | 1% | RES SMD 6.81K OHM 1% 1/10W 0402 | ERJ-2RKF6811X | RB36
79 | 2 | 3.32k |  | 1% | RES SMD 3.32K OHM 1% 1/10W 0402 | ERJ-2RKF3321X | RB37 RB109
80 | 28 | DNP |  | 1% | RES NS 1/10W 0402 | NO_STUFF | RB45 RB49 RB53 RB63 RB65 RB73 RB83 RB85 RB113 RB115 RB152-RB155 RB175 RB194 RB196 RB204 RB232 RB239 RB263 RB266 RT22 RT32 RT41 RT42 RT44 RT47
81 | 5 | 0.001 |  | 1% | RES 0.001 OHM 1% 1W 1206 | CSR1206-0R001F1 | RB59 RB210 RB215 RB247 RT23
82 | 34 | 0 |  | Jumper | RES, Thick Film, 0, Jumper, 1/10W, SMD, 0402 | ERJ-2GE0R00X | RB66 RB67 RB78 RB81 RB82 RB106 RB107 RB111 RB112 RB156 RB170 RB177 RB183 RB185 RB211-RB213 RB217 RB225 RB229 RB233 RB236 RB249 RB251 RB264 RB265 RT6 RT14 RT15 RT26 RT33 RT38 RT45 RT46
83 | 7 | 249 Ohm |  | 1.0 % | RES, Thick Film, 249 Ohm, 1.0 %, 1/10 W, SMD, 0603 | MCR03EZPFX2490 | RB88 RB96 RB102 RB160 RB161 RB166 RB172
84 | 21 | 4.99k |  | 1% | RES SMD 4.99K OHM 1% 1/10W 0402 | ERJ-2RKF4991X | RB89-RB95 RB97-RB101 RB103 RB104 RB214 RB227 RB228 RB248 RB250 RB262 RT43
85 | 12 | 240 |  | 1 % | RES SMD 240 OHM 1% 1/10W 0402 | ERJ-2RKF2400X | RB125-RB130 RB148-RB150 RB157-RB159
86 | 4 | 1k |  | 1% | RES SMD 1K OHM 1% 1/10W 0402 | ERJ-2RKF1001X | RB131 RB135 RB139 RB151
87 | 6 | 4.7k |  | 1% | RES SMD 4.7K OHM 1% 1/10W 0402 | ERJ-2RKF4701X | RB132 RB145-RB147 RT2 RT29
88 | 2 | 10 |  | 1% | RES SMD 10 OHM 1% 1/16W 0402 | RC0402FR-0710RL | RB141 RB144
89 | 8 | 75 Ohm |  | 1 % | RES SMD 75 OHM 1% 1/10W 0402 | ERJ-2RKF75R0X | RB162 RB165 RB171 RB180 RB187 RB190 RB193 RB200
90 | 2 | 60.4K |  | 1 % | RES SMD 60.4K OHM 1% 1/10W 0402 | ERJ-2RKF6042X | RB174 RB186
91 | 2 | 100K |  | 1% | RES SMD 100K OHM 1% 1/16W 0402 | RC0402FR-07100KL | RB178 RB245
92 | 3 | 121k |  | 1 % | RES SMD 121K OHM 1% 1/10W 0402 | ERJ-2RKF1213X | RB179 RB230 RB231
93 | 1 | 16.2K |  | 1 % | RES SMD 16.2K OHM 1% 1/10W 0402 | ERJ-2RKF1622X | RB205
94 | 1 | 61.9k |  | 1 % | RES SMD 61.9K OHM 1% 1/10W 0402 | ERJ-2RKF6192X | RB206
95 | 1 | 160 Ohm |  | 1 % | RES SMD 160 OHM 1% 1/10W 0603 | ERJ-3EKF1600V | RB209
96 | 2 | 0.0055 |  | 1 % | Thick Film Resistors - SMD 5.6M ohm 1% 1/8W AEC-Q200 | AC0805FR-075M6L | RB216 RB218
97 | 1 | 19.1k |  | 1 % | RES SMD 19.1K OHM 1% 1/10W 0402 | ERJ-2RKF1912X | RB234
98 | 2 | 2.49K |  | 1% | RES, Thick Film, 2.49K, 1%, 1/10W, SMD, 0603 | ERJ-3EKF2491V | RB237 RT28
99 | 4 | 10 |  | 1% | RES, Thick Film, 10, 1%, 1/10W, SMD, 0603 | RMCF0603FT10R0 | RB246 RT7 RT50 RT51
100 | 8 | 0 Ohm |  | 1 % | RES SMD 0 OHM JUMPER 1/10W 0603 | P0.0GCT-ND | RB253 RB254 RB256-RB261
101 | 1 | 20k |  | 1% | RES SMD 20K OHM 1% 1/5W 0402 | CRCW040220K0FKEDHP | RB255
102 | 1 | 12.1K |  | 1% | RES SMD 12.1K OHM 1% 1/10W 0402 | ERJ-2RKF1212X | RT1
103 | 2 | 499 Ohm |  | 0.1 % | RES SMD 499 OHM 0.1% 1/16W 0402 | ERA-2AEB4990X | RT3 RT4
104 | 1 | 4.99 kOhm |  | 1.0 % | RES, Thick Film, 4.99 kOhm, 1.0 %, 1/16 W, SMD, 0402 | CRCW04024K99FKED | RT5
105 | 2 | 1.24K |  | 1 % | RES SMD 1.24KOHM 0.1% 1/16W 0402 | ERA-2AEB1241X | RT8 RT31
106 | 1 | 0.005 |  | 1% | RES 0.005 OHM 1% 1/2W 0805 | ERJ-6LWFR005V | RT10
107 | 6 | 0.001 |  | 1 % | RES 0.001 OHM 1% 3W 1216 | WSK12161L000FEB | RT16 RT30 RT34 RT39 RT48 RT49
108 | 1 | 6.65 kOhm |  | 1.0 % | RES, Thick Film, 6.65 kOhm, 1.0 %, 1/10 W, SMD, 0603 | RK73H1JTTP6651F | RT27
109 | 2 | 100 |  | 10% | RES SMD 0.75W 100ohm 10% 200ppm Anti-Surge | SG732HTTE101K | RT52 RT53
110 | 2 | 10 M |  | 1% | RES 10M OHM 1% 1W 2010 | HVCB2010FKC10M0 | RT54 RT55
111 | 1 | MDS6500AL02LL |  |  | SWITCH SNAP ACT SPST-NO 100MA 6V | MDS6500AL02LL | SWB1
112 | 3 | PTS645SM43SMTR92 LFS |  |  | SWITCH TACTILE SPST-NO 0.05A 12V | PTS645SM43SMTR92 LFS | SWT1-SWT3
113 | 13 | 5000 Red |  |  | MISC, Testpoint, 5000 Red, TH, 2.5x2.5x4.6 mm | EMA-00001075 | TP1-TP13
114 | 4 | 5002 White |  |  | MISC, Testpoint, 5002 White, TH, 2.5x2.5x4.6 mm | EMA-00001481V22 | TP14-TP17
115 | 3 | 74CBTLV3257 |  |  | IC MUX/DEMUX DUAL 1OF4 16TSSOP | 74CBTLV3257 | UB1 UB2 UB5
116 | 1 | 93LC56BT-I/OT |  |  | IC EEPROM 2K SPI 2MHZ SOT23-6 | 93LC56BT-I/OT | UB3
117 | 1 | FT4232HQ |  |  | USB Bridge, USB to UART USB 2.0 UART Interface 64-QFN (9x9) | FT4232HQ-REEL | UB4
118 | 1 | TPS2458RHBT |  |  | IC CTRLR HOT SWAP 3.3V 32-QFN | TPS2458RHBT | UB6
119 | 1 | TXS0104EDR |  |  | IC TRNSLTR BIDIRECTIONAL 14VQFN | TXS0104EDR | UB7
120 | 2 | BCM5482SA2KFBG |  |  | IC TRANSCEIVER FULL/HALF 2/2 | BCM5482SA2KFBG | UB8 UB17
121 | 2 | 25MHz |  |  | XTAL OSC XO 25.0000MHZ CMOS SMD | SG-210STF 25.0000MS3 | UB9 UB30
122 | 11 | LTC2945CUD |  |  | IC POWER MONITOR I2C 12-QFN | LTC2945CUD | UB10 UB18 UB19 UB21-UB23 UB28 UT3 UT5 UT7 UT12
123 | 1 | TCA9548ARGER |  |  | IC I2C SW 8CH W/RESET 24VQFN | TCA9548ARGER | UB11
124 | 2 | TMP100NA/250 |  |  | SENSOR DGTL -40C-150C 16LFCSP | TMP100NA/250 | UB12 UT11
125 | 2 | XR21V1410IL16-F |  |  | IC UART FIFO USB SGL 16QFN | XR21V1410 | UB13 UB16
126 | 2 | SI5332E-D-GM3-5MHz-333.33MHz |  |  | Clock Generators & Support Products Base/blank prototyping device: 6-output, INT+FRAC, 5MHz - 312.5MHz, embedded ref crystal | SI5332E-D-GM3 | UB14 UB15
127 | 1 | BCM5396KFBG |  |  | Ethernet ICs 16 PORT LAYER 2 GE SWITCH W/SE | BCM5396KFBG | UB20
128 | 1 | TPS3808G25DBVT |  |  | IC SUPERVISOR 1 CHANNEL SOT23-6 | TPS3808G25DBVT | UB24
129 | 3 | TPS7A8500RGRT |  |  | IC REG LINEAR POS ADJ 4A 20VQFN | TPS7A8500RGRT | UB25 UB26 UB31
130 | 1 | LMK00804BPW |  |  | IC CLK BUFFER 1:4 350MHZ 16TSSOP | LMK00804BPW | UB27
131 | 1 | ADM1066ACPZ |  |  | IC, Power Management, Supervisory Circuit, ADM1232A, SOIC-8 | ADM1066ACPZ | UB29
132 | 1 | 24AA025E48T-I/OT |  |  | IC EEPROM 2K I2C 400KHZ SOT23-6 | 24AA025E48T-I/OT | UB32
133 | 1 | ACPL-217-50BE |  |  | OPTOISOLATOR 3KV TRANSISTOR 4-SO | ACPL-217-50BE | UT1
134 | 1 | PQ60120QZB33 |  |  | Isolated DC/DC Converters 600W 40 - 60Vin 12Vout@50A | PQ60120QZB33NNS-G | UT2
135 | 1 | SIP32408DNP-T1-GE4 |  |  | IC PWR SWITCH N-CHAN 1:1 4TDFN | SIP32408DNP-T1-GE4 | UT4
136 | 1 | FPGA-XCVU37P-H2892 |  |  | ULTRASCALE-PLUS VU37P | XCVU37P-L2FSVH2892EES9837 | UT6
137 | 2 | LTM4630EY#PBF |  |  | DC DC CNVRTR 0.6-1.8V 0.6-1.8V | LTM4630EY#PBF | UT8 UT13
138 | 1 | TG1G-S205NV6RL |  |  | Audio Transformers / Signal Transformers GIGABIT ISO MOD SMD 48P 2-Port No Choke | TG1G-S205NV6RL | UT9
139 | 1 | LGA80D-00DADJJ |  |  | DC DC CNVRTR 0.6-5.2V 0.6-5.2V | LGA80D-00DADJJ | UT10
140 | 1 | IQ65033QTA14-G |  |  | POWER INTERFACE MODULE | IQ65033QTA14-G | UT14
141 | 1 | 12MHz |  |  | CRYSTAL 12.0000MHZ 12PF SMD | CX2520DB12000H0FLJC1 | X1
142 | 1 | Mercury Holes 56x54mm |  |  |  |  | Z1

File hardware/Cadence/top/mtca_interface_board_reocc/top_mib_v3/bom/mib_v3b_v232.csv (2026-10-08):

TITLE: Bill of Materials
DATE: 10/08/2026
DESIGN: top_mib_v3
TEMPLATE: Z:\cad\tools\cadence_templates\spreadsheet-format.bom
CALLOUT:
Part Name | Ref Des | Qty | PART_NUMBER | PART_DESCRIPTION | OL_COMMENTS | KL_COMMENTS | PL_COMMENTS | Do Not Fit | MANUFACTURER | DNF
155060RS73200 | DS1 | 1 | 155060RS73200 | Wurth, SMSW, LED, Red, SMD, 0603 [1608 Metric], 20 mA, 2 V, 624 nm | ? | ? | ? | ? | ? | ?
24AA025E48T-I/SN-24AA025E48T-I/SN,24AA025E48T-I/SN | U18 | 1 | 24AA025E48T-I/SN | ? | ? | ? | ? | ? | MICROCHIP TECHNOLOGY | ?
7X2RECPT_SMD_2MM-878321420,7X2RECPT_SMD_2MM | J10 | 1 | 878321420 | ? | ? | ? | ? | ? | MOLEX CONNECTOR CORPORATION | ?
854S01AKILF | IC8 | 1 | 854S01AKILF | ? | ? | ? | ? | ? | IDT | ?
ADCLK948BCPZ | IC3,IC4 | 2 | ADCLK948BCPZ | ? | ? | ? | ? | ? | ANALOG DEVICES | ?
ATMGA128-ATMEGA128A-AU,ATMGA128 | U4 | 1 | ATMEGA128A-AU | ? | ? | ? | ? | ? | MICRO CHIP | ?
CAPCERSMDCL2_0402-100NF,16V_GEN | C8,C12,C13,C14,C15,C19,C24,C27,C29,C32,C37,C49,C79,C80,C84,C97,C99,C102,C122,C133,C135,C136,C137,C138,C139,C142,C146,C148,C149,C150,C151,C152,C153,C154,C157,C158,C159,C165,C166,C167,C169,C170,C174,C175,C176,C177,C178,C179,C180,C181,C182,C183,C184,C185,C186,C187,C188,C189,C190,C191,C192,C193,C194,C195,C196,C197,C198,C199 | 68 | CC0402_100NF_16V_10%_X7R | ? | ? | ? | ? | ? | GENERIC | ?
CAPCERSMDCL2_0402-1NF_X7R,50V | C18,C21,C22,C85,C125 | 5 | CC0402_1NF_50V_10%_X7R | ? | ? | ? | ? | ? | GENERIC | ?
CAPCERSMDCL2_0402-1UF,16V | C5,C6,C7,C83,C118,C130,C131,C132,C134,C160,C168,C173 | 12 | CC0402_1.0UF_16V_10%_X5R | ? | ? | ? | ? | ? | GENERIC | ?
CAPCERSMDCL2_0603-10UF,6.3V | C126,C127,C128,C129,C162,C163,C171,C172 | 8 | CC0603_10UF_6V3_20%_X5R | ? | ? | ? | ? | ? | GENERIC | ?
CAPCERSMDCL2_0603-1UF,16V | C23,C41 | 2 | CC0603_1UF_16V_10%_X5R | ? | ? | ? | ? | ? | GENERIC | ?
CAP_NP-445-7348-2-ND,CAP_NP | C57,C62,C64,C66,C69,C86,C90,C94,C103,C107,C111,C115,C140,C145,C156 | 15 | 445-7348-2-ND | ? | ? | ? | ? | ? | TDK CORP | ?
CAP_NP-445-8173-1-ND,CAP_NP | C42,C47,C48,C75,C76,C92 | 6 | 445-8173-1-ND | ? | ? | ? | ? | ? | TDK CORP | ?
CAP_NP-C0402C104K9RACTU,CAP_NP | C53,C93,C104 | 3 | C0402C104K9RACTU | ? | ? | ? | ? | ? | KEMET | ?
CAP_NP-GRM152R60J105ME15D,CAP_NP | C9,C20,C38,C147 | 4 | GRM152R60J105ME15D | ? | ? | ? | ? | ? | MURATA | ?
CAP_NP-GRM155R60J474KE19J,CAP_NP | C46 | 1 | GRM155R60J474KE19J | ? | ? | ? | ? | ? | MURATA | ?
CAP_NP-GRM188R60J226MEA0D,CAP_NP | C88,C96,C109,C117,C143,C161 | 6 | GRM188R60J226MEA0D | ? | ? | ? | ? | ? | MURATA | ?
CAP_NP-GRM188R61A106KE69D,CAP_NP | C87,C108,C112,C121,C141,C155 | 6 | GRM188R61A106KE69D | ? | ? | ? | ? | ? | MURATA | ?
CAP_NP-GRM21BR60J476ME15K,CAP_NP | C50,C54,C55,C56,C59,C60,C65,C68,C71,C72,C81,C82 | 12 | GRM21BR60J476ME15K | ? | ? | ? | ? | ? | MURATA | ?
CAP_NP-GRM31CD80J107ME39K,CAP_NP | C16,C95 | 2 | GRM31CD80J107ME39K | ? | ? | ? | ? | ? | MURATA | ?
CAP_NP-GRT155R61E105ME01D,CAP_NP | C89,C110,C144 | 3 | GRT155R61E105ME01D | ? | ? | ? | ? | ? | MURATA | ?
CAP_NP_0-445-7348-2-ND,CAP_NP_0 | C1,C2,C3,C4,C10,C11,C26,C28,C30,C31,C33,C34,C35,C36,C39,C40,C43,C45,C91 | 19 | 445-7348-2-ND | ? | ? | ? | ? | ? | TDK CORP | ?
CON20P_SFP-1367073-1-1367073-1,CON20P_SFP-1367073-1 | J3,J6,J11 | 3 | 1367073-1 | ? | ? | ? | ? | ? | TE CONNECTIVITY AMP CONNECTORS | ?
CON4P-53398-0471 | J16 | 1 | 53398-0471 | ? | ? | ? | ? | ? | MOLEX | ?
CONN30P-FTSH-115-01-L-DV,CONN30P | J4 | 1 | FTSH-115-01-L-DV | ? | ? | ? | ? | ? | SAMTEC | ?
ELCAPTAN_SMD-220UF,25V | C25,C51,C52,C58 | 4 | 597D227X0025M2T | ? | ? | ? | ? | ? | VISHAY | ?
FERRITE_SMD-BLM21PG221SN1,MURATA | L9 | 1 | BLM21PG221SN1 | ? | ? | ? | ? | ? | MURATA | ?
FERRITE_SMD-MPZ1608S101A,TDK | L12 | 1 | MPZ1608S101A | ? | ? | ? | ? | ? | TDK | ?
HDR1X3-HDR1X3,HDR1X3 | J12 | 1 | HDR1x3 | ? | ? | ? | ? | ? | SAMTEC | ?
HDT0001-HDT0001,HDT0001 | SW1 | 1 | HDT0001 | ? | ? | ? | ? | ? | C&K | ?
HEADER2X1_STR-HARWIN | PL1 | 1 | Harwin M20-999 02 05 | Harwin Straight 2 pin Header | Can be cut from M20-999 36 05 | - | - | ? | ? | ?
IND-74438323100,IND | L4 | 1 | 74438323100 | ? | ? | ? | ? | ? | W__RTH ELEKTRONIK | ?
IND-BLM18AG121SN1D,IND | L1,L2,L3,L10 | 4 | BLM18AG121SN1D | ? | ? | ? | ? | ? | MURATA ELECTRONICS | ?
IND-CIGT201208EH1R0MNE,IND | L5,L6,L7,L8,L11,L13 | 6 | CIGT201208EH1R0MNE | ? | ? | ? | ? | ? | SAMSUNG ELECTRO-MECHANICS | ?
INV_1CH_OD-SN74LVC1G06DBVTE4,INV_1CH_OD | U15 | 1 | SN74LVC1G06DBVTE4 | ? | ? | ? | ? | ? | TEXAS INSTRUMENTS | ?
KKCON3_STR-MOLEX | SK1 | 1 | Onecall 146-2950 | Square pin header 0.1 straight | - | - | - | ? | ? | ?
KPA-2107LVVBC-D | DS2 | 1 | KPA-2107LVVBC-D | Kingbright, edge launch LED, 2.1mm x 0.6mm, Blue, SMD, 2.1mm x 0.7mm, 2 mA, 2.65 V, 470 nm | ? | ? | ? | ? | ? | ?
LED GREEN 0603_0-LNJ326W83RA,LED GREEN 0603_0 | D1,D5,D6 | 3 | LNJ326W83RA | ? | ? | ? | ? | ? | PANASONIC | ?
LED RED 0603_0-LNJ237W82RA,LED RED 0603_0 | D4 | 1 | LNJ237W82RA | ? | ? | ? | ? | ? | PANASONIC | ?
LM75A-LM75AIMME/NOPB,LM75A | U25 | 1 | LM75AIMME/NOPB | ? | ? | ? | ? | ? | TEXAS INSTRUMENTS | ?
LSHM-130-0XXX-L-DV-A-S-LSHM-130-03.0-L-DV-A-S-K-TR,LSHM-130-0XXX-L-DV-A-S | J2 | 1 | LSHM-130-03.0-L-DV-A-S-K-TR | ? | ? | ? | ? | ? | SAMTEC | ?
LSHM-150-0XXX-L-DV-A-S-LSHM-150-03.0-L-DV-A-S-K-TR,LSHM-150-0XXX-L-DV-A-S | J9 | 1 | LSHM-150-03.0-L-DV-A-S-K-TR | ? | ? | ? | ? | ? | SAMTEC | ?
LTC2991CMS#PBF | IC6 | 1 | LTC2991CMS#PBF | ? | ? | ? | ? | ? | LINEAR TECHNOLOGY | ?
MAX9381ESA_SMD-MAX9381ESA | U2 | 1 | MAX9381ESA | ? | ? | ? | ? | ? | ? | ?
MCH_CONNECTOR1-MCH1B-EDGE-170,MCH_CONNECTOR1 | J7 | 1 | MCH1B-EDGE-170 | ? | ? | ? | ? | ? | HEP | ?
MT_HOLE-MT_HOLE,MT_HOLE | MH1,MH2,MH3,MH4,MH5,MH6,MH7,MH8,MH9,MH10 | 10 | Mt_Hole | ? | ? | ? | ? | ? | HEP | ?
PCOAX-U.FL-R-SMT-1(10) | J14,J15,J17,J18,J19,J20 | 6 | U.FL-R-SMT-1(10) | ? | ? | ? | ? | ? | HIROSE | ?
PTH08T210WAD | POWER1,PWR1 | 2 | PTH08T210WAD | ? | ? | ? | ? | ? | TEXAS INSTRUMENTS | ?
R-311-24.9LRCT-ND,R | R16,R31,R48,R50,R51,R53 | 6 | 311-24.9LRCT-ND | ? | ? | ? | ? | ? | YAGEO | ?
R-311-49.9LRCT-ND,R | R8,R9,R20,R23 | 4 | 311-49.9LRCT-ND | ? | ? | ? | ? | ? | YAGEO | ?
R-CRCW060310M0FKEAC,R | R137,R138 | 2 | CRCW060310M0FKEAC | ? | ? | ? | ? | ? | VISHAY DALE | ?
R-DNF,R | R81,R103 | 2 | DNF | ? | ? | ? | ? | ? | DNF | ?
R-EMA-00003608,R | R3,R63,R135 | 3 | EMA-00003608 | ? | ? | ? | ? | ? | ROHM | ?
R-EMA-00007500V42,R | R19,R26,R28,R29,R35,R36,R73,R75,R77,R91,R97,R147,R154,R191,R192 | 15 | EMA-00007500V42 | ? | ? | ? | ? | ? | PANASONIC | ?
R-ERA-2AEB303X,R | R110 | 1 | ERA-2AEB303X | ? | ? | ? | ? | ? | PANASONIC | ?
R-ERJ-2RKF1000X,R | R1,R10,R25,R27,R30,R32,R34,R134 | 8 | ERJ-2RKF1000X | ? | ? | ? | ? | ? | PANASONIC | ?
R-ERJ-2RKF1001X,R | R68,R107,R108,R109,R113 | 5 | ERJ-2RKF1001X | ? | ? | ? | ? | ? | PANASONIC | ?
R-ERJ-2RKF1503X,R | R33,R111 | 2 | ERJ-2RKF1503X | ? | ? | ? | ? | ? | PANASONIC | ?
R-ERJ-2RKF2201X,R | R54,R58,R119,R120,R121,R122,R124,R125,R126,R127 | 10 | ERJ-2RKF2201X | ? | ? | ? | ? | ? | PANASONIC | ?
R-ERJ-2RKF3302X,R | R39,R44,R45,R47,R57,R61,R93 | 7 | ERJ-2RKF3302X | ? | ? | ? | ? | ? | PANASONIC | ?
R-ERJ-2RKF33R0X,R | R102 | 1 | ERJ-2RKF33R0X | ? | ? | ? | ? | ? | PANASONIC | ?
R-ERJ-2RKF3903X,R | R104 | 1 | ERJ-2RKF3903X | ? | ? | ? | ? | ? | PANASONIC | ?
R-ERJ-2RKF4701X,R | R41,R52 | 2 | ERJ-2RKF4701X | ? | ? | ? | ? | ? | PANASONIC | ?
R-ERJ-2RKF4990X,R | R21,R22 | 2 | ERJ-2RKF4990X | ? | ? | ? | ? | ? | PANASONIC | ?
R-ERJ-2RKF4991X,R | R13,R17,R59,R67,R71,R86,R92,R95,R96,R98,R99,R112,R114,R115,R116,R117,R123,R128,R129,R130,R131,R132,R133 | 23 | ERJ-2RKF4991X | ? | ? | ? | ? | ? | PANASONIC | ?
R-ERJ-2RKF49R9X,R | R55,R56 | 2 | ERJ-2RKF49R9X | ? | ? | ? | ? | ? | PANASONIC | ?
R-ERJ-6GEY0R00V,R | R80 | 1 | ERJ-6GEY0R00V | ? | ? | ? | ? | ? | PANASONIC | ?
R-ERJ-PA2F3300X,R | R105 | 1 | ERJ-PA2F3300X | ? | ? | ? | ? | ? | PANASONIC - SCD | ?
R-M55342K11B10E0RS3,R | R72,R85,R94,R106,R136 | 5 | M55342K11B10E0RS3 | ? | ? | ? | ? | ? | VISHAY DALE | ?
R-NO_STUFF,R | R74,R76,R78 | 3 | NO_STUFF | ? | ? | ? | ? | ? | NS | ?
RES_SR_LVK12-0.05,1% | R62,R90 | 2 | LVK12R050FER | ? | ? | ? | ? | ? | OHMITE | ?
RSMD0402_1/16W-1K,1% | R11,R24,R37,R38,R40,R42,R155,R156 | 8 | R0402_1K_1%_0.063W_100PPM | ? | ? | ? | ? | ? | GENERIC | ?
RSMD0402_1/16W-2.2K,1% | R43,R46,R49,R100,R157,R158 | 6 | R0402_2K2_1%_0.063W_200PPM | ? | ? | ? | ? | ? | GENERIC | ?
RSMD0402_1/16W-200,1% | R159,R160,R161,R162,R163,R164,R165,R166,R167,R168,R169,R170,R171,R172,R173,R174,R175,R176,R177,R178,R179,R180,R181,R182,R183,R184,R185,R186,R187,R188,R189,R190 | 32 | R0402_200R_1%_0.063W_200PPM | ? | ? | ? | ? | ? | GENERIC | ?
RSMD0402_1/16W-6.2K,1% | R88 | 1 | R0402_6K2_1%_0.063W_200PPM | ? | ? | ? | ? | ? | GENERIC | ?
RSMD0603_-00, | R2,R5,R64,R66,R82,R89 | 6 | R0603_00_JUMPER | ? | ? | ? | ? | ? | GENERIC | ?
RSMD0603_1/10W-1,1% | R69,R84 | 2 | R0603_1R_1%_0.1W_100PPM | ? | ? | ? | ? | ? | GENERIC | ?
RSMD0603_1/10W-1.6K,1% | R70 | 1 | R0603_1K6_1%_0.1W_100PPM | ? | ? | ? | ? | ? | GENERIC | ?
RSMD0603_1/10W-20,1% | R4,R12 | 2 | R0603_20R_1%_0.1W_100PPM | ? | ? | ? | ? | ? | GENERIC | ?
RSMD0603_1/10W-5.6K,1% | R60 | 1 | R0603_5K6_1%_0.1W_100PPM | ? | ? | ? | ? | ? | GENERIC | ?
RSMD0603_1/10W-75K,1% | R6 | 1 | R0603_75K_1%_0.1W_100PPM | ? | ? | ? | ? | ? | GENERIC | ?
RSMD0603_1/10W-XX,1% | R65,R79 | 2 | R0603_XX_1%_0.1W_100PPM | ? | ? | ? | ? | ? | GENERIC | ?
RSMD0603_1/16W-270,1% | R7 | 1 | R0603_270R_1%_0.063W_100PPM | ? | ? | ? | ? | ? | GENERIC | ?
RSMD0805_125MW-0.27,1% | R87 | 1 | R0805_0R27_1%_0.125W_100PPM | ? | ? | ? | ? | ? | GENERIC | ?
SF-0603FP015F-2 | F2,F3 | 2 | ? | ? | ? | ? | ? | ? | ? | ?
SF-0603S300-2 | F1 | 1 | ? | ? | ? | ? | ? | ? | ? | ?
SFP_CAGE-2227023-1-2227023-1,SFP_CAGE-2227023-1 | U5,U11,U14 | 3 | 2227023-1 | ? | ? | ? | ? | ? | TE CONNECTIVITY AMP CONNECTORS | ?
SHF-105-01-L-D-SM | J13 | 1 | ? | ? | ? | ? | ? | ? | ? | ?
SI5395A-A-GM-SI5395A-A-GM,SI5395A-A-GM | U6 | 1 | SI5395A-A-GM | ? | ? | ? | ? | ? | SILICON LABS | ?
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

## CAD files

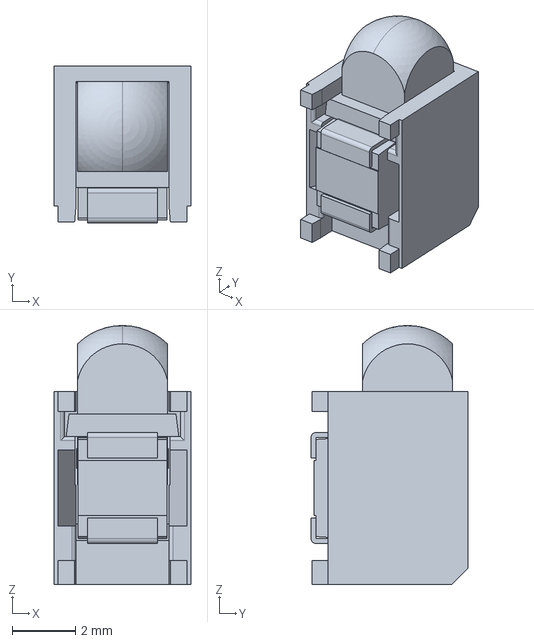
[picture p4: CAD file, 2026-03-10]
hardware/591-3001-113F.stp
4.32 x 4.95 x 8.18 mm

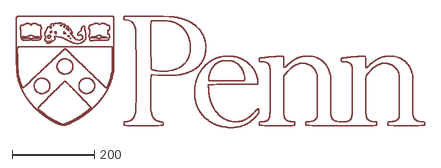
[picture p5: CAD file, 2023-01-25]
hardware/Cadence/cis_hep_partslib/cis_hep_partslib/Allegro_Library/symbols/Logos/UPENN_Logo.dxf
995.1 x 271.5

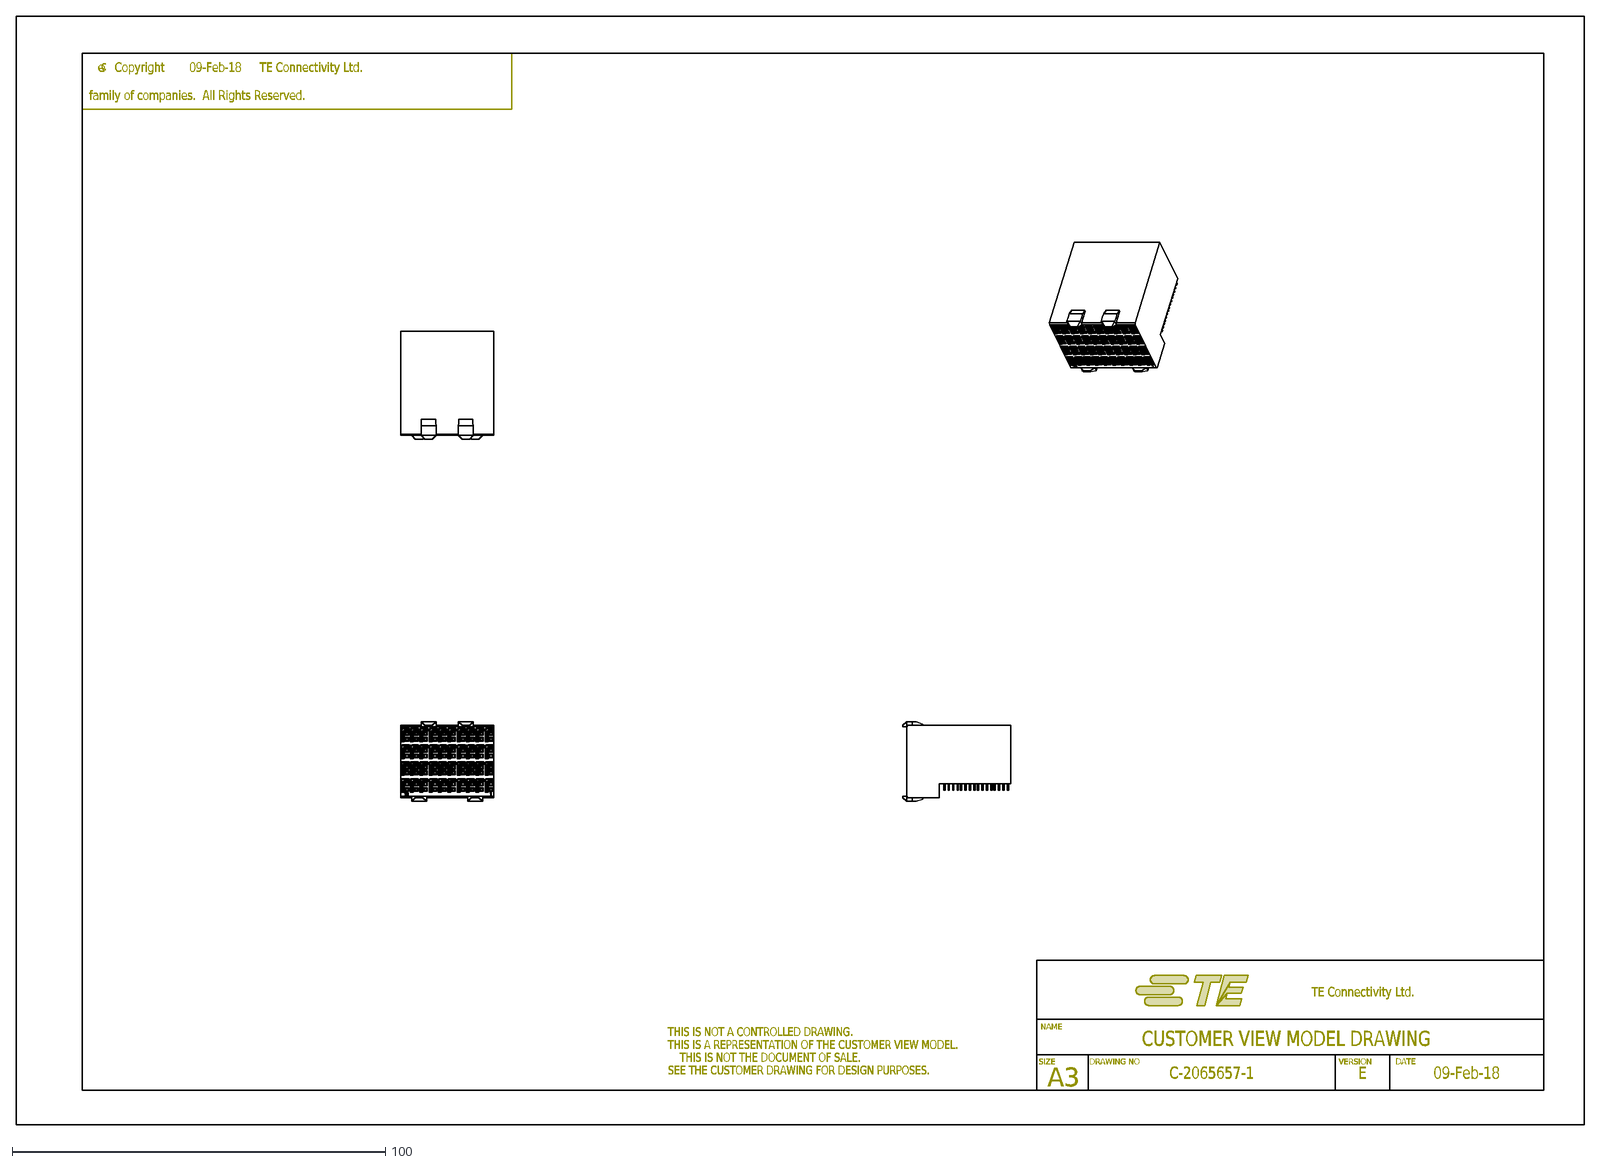
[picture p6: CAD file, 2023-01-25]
hardware/Cadence/cis_hep_partslib/cis_hep_partslib/DataSheets/c-2065657-1-e-2d.dxf
SIZE
DRAWING NO
VERSION
NAME
A3
CUSTOMER VIEW MODEL DRAWING
TE Connectivity Ltd.
DATE
THIS IS NOT A CONTROLLED DRAWING.
THIS IS A REPRESENTATION OF THE CUSTOMER VIEW MODEL.
THIS IS NOT THE DOCUMENT OF SALE.
SEE THE CUSTOMER DRAWING FOR DESIGN PURPOSES.
c
C-2065657-1
E
09-Feb-18
Copyright
family of companies. All Rights Reserved.

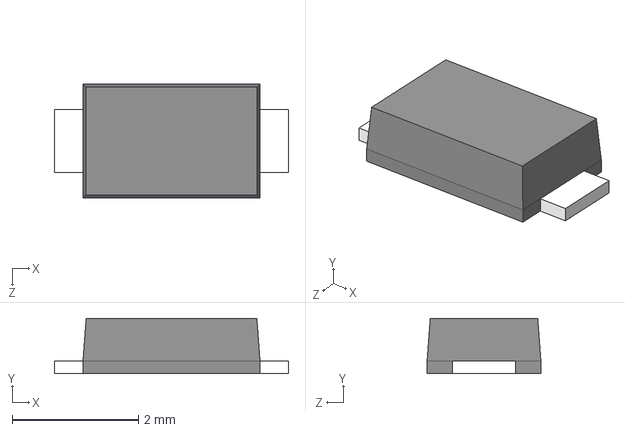
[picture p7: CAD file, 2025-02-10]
hardware/Cadence/top/mtca_interface_board_reocc/top_mib_v3/physical/SS16FP.stp
3.70 x 0.875 x 1.80 mm

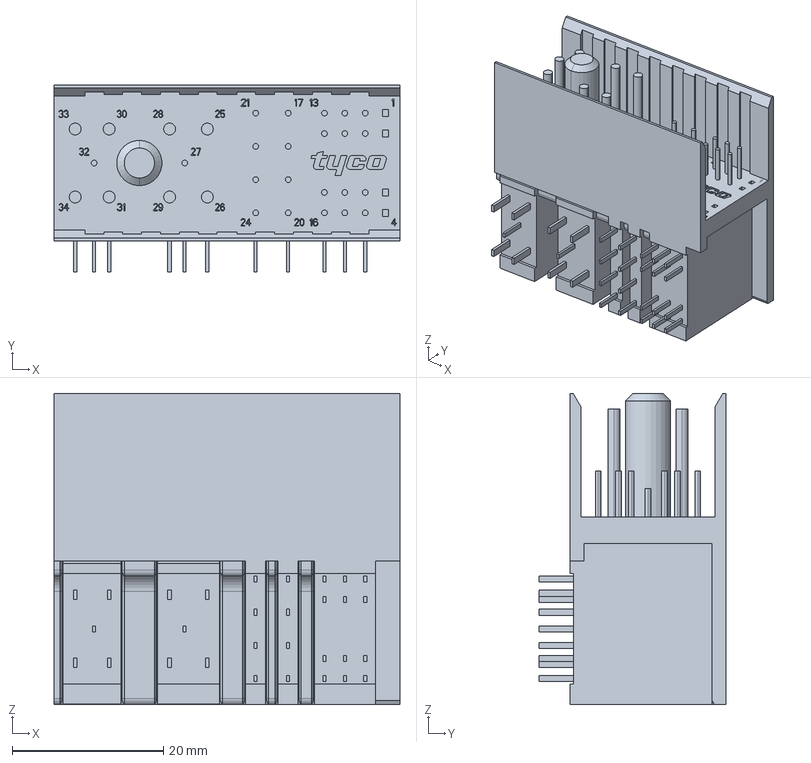
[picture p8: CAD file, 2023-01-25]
hardware/Cadence/cis_hep_partslib/cis_hep_partslib/DataSheets/c-1766500-1-c-3d.stp
45.8 x 24.8 x 41.2 mm

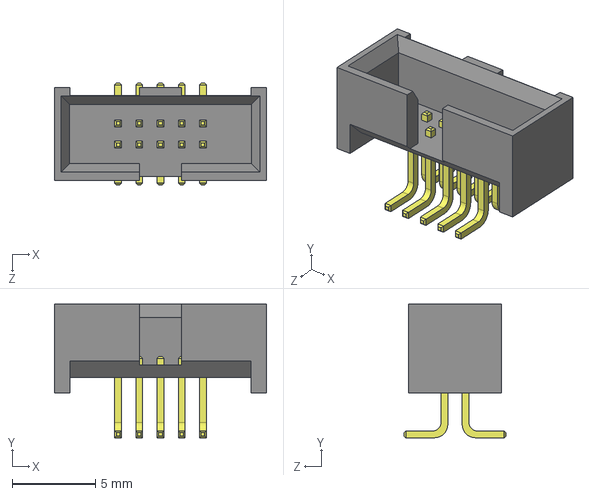
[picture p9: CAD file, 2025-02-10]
hardware/Cadence/top/mtca_interface_board_reocc/top_mib_v3/physical/SHF-105-01-L-D-SM.stp
12.7 x 8.00 x 6.10 mm

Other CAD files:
hardware/Cadence/cis_hep_partslib/cis_hep_partslib/Allegro_Library/ADC10065CIMT/sop65p640x120-28n.psm
hardware/Cadence/cis_hep_partslib/cis_hep_partslib/Allegro_Library/PTC_B/soic16.psm
hardware/Cadence/cis_hep_partslib/cis_hep_partslib/Allegro_Library/PTC_B/tssop24.psm
hardware/Cadence/cis_hep_partslib/cis_hep_partslib/Allegro_Library/ROCSTAR/1210rf_wv_12d.psm
hardware/Cadence/cis_hep_partslib/cis_hep_partslib/Allegro_Library/ROCSTAR/21-0382.psm
hardware/Cadence/cis_hep_partslib/cis_hep_partslib/Allegro_Library/ROCSTAR/ad9222_cp64-3.psm
hardware/Cadence/cis_hep_partslib/cis_hep_partslib/Allegro_Library/ROCSTAR/ad9287_cp48-1.psm
hardware/Cadence/cis_hep_partslib/cis_hep_partslib/Allegro_Library/ROCSTAR/as11av.psm
hardware/Cadence/cis_hep_partslib/cis_hep_partslib/Allegro_Library/ROCSTAR/asemp_cmos.psm
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

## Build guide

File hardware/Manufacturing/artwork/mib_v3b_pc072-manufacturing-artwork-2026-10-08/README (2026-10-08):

pc072

Version = £b
Subversion = 232

This file describes PCB fabrication details for the MIB v3b 
for the DUNE timing system
 
contact:	David.Cussans@bristol.ac.uk
		tel: 0117 95 46879
		     0117 33 17199
		fax: 0117 925 5624

Files produced by Cadence Allegro PE24.1

Artwork:
--------

Format: Gerber RS-274X , parameters described in art_param.txt. 
All layers viewed from top

Build:
------

10-layers
ENIG finish to outer layers except for edge connector which should have a "hard gold" finish.

Layers as follows:

mib_rev3b_v232_01_Top.art
mib_rev3b_v232_02_GND.art
mib_rev3b_v232_03_sig1.art
mib_rev3b_v232_04_GND.art
mib_rev3b_v232_05_PWR1.art
mib_rev3b_v232_06_GND.art
mib_rev3b_v232_07_SIG2.art
mib_rev3b_v232_08_GND.art
mib_rev3b_v232_09_SIG3.art
mib_rev3b_v232_10_Bottom.art

Areas with selective hard gold finish:
--------------------------------------
mib_rev3b_v232_16_hardgold_top.art
mib_rev3b_v232_17_hardgold_bot.art

Solder Masks
------------

mib_rev3b_v232_13_smask_top.art
mib_rev3b_v232_14_smask_bot.art

Colour - green. 

Solderpaste mask
-----------------

mib_rev3b_v232_27_pmask_top.art
mib_rev3b_v232_28_pmask_bot.art

Silk screen
-----------

mib_rev3b_v232_11_silk_top.art
mib_rev3b_v232_12_silk_bot.art

Colour - white.

Board outline: (Gerber RS-274X)
-------------------------------

mib_rev3b_v232_18_DESIGN_OUTLINE.art

Board cutout: 
-------------------------------

The board has one cutout. outline of cutout in:

mib_rev3b_v232_19_CUTOUT.art (Gerber RS-274X)
mib_rev3b_v232_1-10.rou      (Excellon)

Fabrication drawing: ( Including illustration of hole sizes/position and board stack-up)
-------------

mib_rev3b_v232_15_fab_plot.art

Drill information ( Excellon format, described in nc_param.txt )
----------------------------------------------------------------

mib_rev3b_v232_glossed-1-10.drl

Assembly drawings:
------------------
mib_rev3b_v232_29_assy_top.art
mib_rev3b_v232_30_assy_bot.art

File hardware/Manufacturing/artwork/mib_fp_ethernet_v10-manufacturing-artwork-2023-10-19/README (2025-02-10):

mib_fp_ethernet

Version = A
Subversion = 10

This file describes PCB fabrication details for the
Ethernet mezzanine board for the MIB v2 
for the DUNE timing system
 
contact:	David.Cussans@bristol.ac.uk
		tel: 0117 95 46879
		     0117 33 17199
		fax: 0117 925 5624

Files produced by Cadence Allegro PE17.4

Artwork:
--------

Format: Gerber RS-274X , parameters described in art_param.txt. 
All layers viewed from top

Build:
------

"PCBTrain" 4-layer build from Newbury
Immersion silver finish to outer layers

Layers as follows:

mib_fp_ethernet_10_01_Top.art
mib_fp_ethernet_10_02_Gnd.art
mib_fp_ethernet_10_03_Vcc.art
mib_fp_ethernet_10_04_Bottom.art

Solder Masks
------------

mib_fp_ethernet_10_13_smask_top.art
mib_fp_ethernet_10_14_smask_bot.art

Colour - green. 

Solderpaste mask
-----------------

mib_fp_ethernet_10_27_pmask_top.art
mib_fp_ethernet_10_28_pmask_bot.art

Silk screen
-----------

mib_fp_ethernet_10_11_silk_top.art
mib_fp_ethernet_10_12_silk_bot.art

Colour - white.

Board outline: (Gerber RS-274X)
-------------------------------

mib_fp_ethernet_10_18_DESIGN_OUTLINE.art

Fabrication drawing: ( Including illustration of hole sizes/position and board stack-up)
-------------

mib_fp_ethernet_10_fab_plot.art

Drill information ( Excellon format, described in nc_param.txt )
----------------------------------------------------------------

mib_fp_ethernet_10-1-4.drl

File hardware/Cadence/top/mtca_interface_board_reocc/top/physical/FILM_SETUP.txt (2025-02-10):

axlFilmCreate( "Display_ALL" ?negative nil ?undefineLineWidth 0.0000 ?sequence 45 
	?rotation 0 ?xOffset 0.0000 ?yOffset 0.0000 ?shapeBoundingBox 2.5400 ?mirrored nil ?fullContact nil 
	?suppressUnconnectPads nil ?drawMissingPadApertures nil ?useApertureRotation nil 
	?suppressShapeFill nil ?vectorBasedPad t ?drawHolesOnly nil 
	?domains '(ipc2581 pdf artwork visibility ) ?ipc2581 '() 
	?layers '("VIA CLASS/TOP" "REF DES/SILKSCREEN_TOP" "REF DES/SILKSCREEN_BOTTOM" "PIN/TOP" "PACKAGE GEOMETRY/SILKSCREEN_TOP" "PACKAGE GEOMETRY/SILKSCREEN_BOTTOM" "MANUFACTURING/NCDRILL_LEGEND" "MANUFACTURING/NCDRILL_FIGURE" "MANUFACTURING/XSECTION_CHART" "MANUFACTURING/NCBACKDRILL-14-9" "MANUFACTURING/NCLEGEND-1-14" "MANUFACTURING/NCLEGEND-SLOTS" "MANUFACTURING/NCLEGEND-1-10" "MANUFACTURING/NCLEGEND-1-22" "MANUFACTURING/NCLEGEND-1-16" "DRAWING FORMAT/OUTLINE" "DRAWING FORMAT/TITLE_BLOCK" "DRAWING FORMAT/TITLE_DATA" "DRAWING FORMAT/REVISION_BLOCK" "DRAWING FORMAT/REVISION_DATA" "DRAWING FORMAT/FAB_NOTES" "DRAWING FORMAT/ASSY_INFO" "DRAWING FORMAT/PROJ_INFO" "DRAWING FORMAT/FAB_DWG_INFO" "DRAWING FORMAT/ASSY_DWG_INFO" "DRAWING FORMAT/POT_INFO" "DRAWING FORMAT/WHIZZ_LOGO" "DRAWING FORMAT/FORMAT" "DRAWING FORMAT/FORMAT_SHT1" "DRAWING FORMAT/FTB_INFO" "DRAWING FORMAT/FILM_TITLE_BLOCK" "DRAWING FORMAT/STACKUP_DETAIL" "DRAWING FORMAT/DESIGNER_COMMENTS" "DRAWING FORMAT/ASSEMBLY_NOTES" "DRAWING FORMAT/FABRICATION_NOTES" "BOARD GEOMETRY/OUTLINE" "BOARD GEOMETRY/SILKSCREEN_TOP" "BOARD GEOMETRY/SILKSCREEN_BOTTOM" "BOARD GEOMETRY/SOLDERMASK_BOTTOM" "BOARD GEOMETRY/DESIGN_OUTLINE" "BOARD GEOMETRY/CUTOUT" "BOARD GEOMETRY/TFM_DESIGN_OUTLINE" "BOARD GEOMETRY/FAB1" "BOARD GEOMETRY/FABRICATION_NOTES" ))

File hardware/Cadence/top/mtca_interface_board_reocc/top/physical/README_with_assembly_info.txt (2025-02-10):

pc072

Version = A
Subversion = 205

This file describes PCB fabrication details for the MIB v2 
for the DUNE timing system
 
contact:	David.Cussans@bristol.ac.uk
		tel: 0117 95 46879
		     0117 33 17199
		fax: 0117 925 5624

Files produced by Cadence Allegro PE17.4

Artwork:
--------

Format: Gerber RS-274X , parameters described in art_param.txt. 
All layers viewed from top

Build:
------

"PCBTrain" 10-layer build from Newbury

Layers as follows:

mib_rev2_v205_01_Top.art
mib_rev2_v205_02_GND.art
mib_rev2_v205_03_sig1.art
mib_rev2_v205_04_GND.art
mib_rev2_v205_05_PWR1.art
mib_rev2_v205_06_GND.art
mib_rev2_v205_07_SIG2.art
mib_rev2_v205_08_GND.art
mib_rev2_v205_09_SIG3.art
mib_rev2_v205_10_Bottom.art

Solder Masks
------------

mib_rev2_v205_13_smask_top.art
mib_rev2_v205_14_smask_bot.art

Solderpaste mask
-----------------

mib_rev2_v205_27_pmask_top.art
mib_rev2_v205_28_pmask_bot.art

Silk screen
-----------

mib_rev2_v205_11_silk_top.art
mib_rev2_v205_12_silk_bot.art

Board outline: (Gerber RS-274X)
-------------------------------

mib_rev2_v205_18_DESIGN_OUTLINE.art

Board cutout: 
-------------------------------

The board has one cutout. outline of cutout in:

mib_rev2_v199_19_CUTOUT.art  (Gerber RS-274X)
mib_rev2_v205_1-10.rou       (Excellon)

Fabrication drawing: ( Including illustration of hole sizes/position and board stack-up)
-------------

N.B. Ignore comments about hard-gold on connector "fingers"

mib_rev2_v199_15_fab_plot.art

Drill information ( Excellon format, described in nc_param.txt )
----------------------------------------------------------------

pc069a-1-6.drl

Bill of Materials (including component placement information)
-----------------

pc069a_bom.xlsx

Component placement
-------------------

placement_pin1.txt

( Position of pin-1 in mm and rotation in degrees of each component.
  Origin = lower left of board )

Fiducial Marks
--------------

Three 2mm diameter round copper marks. Repeated top and bottom

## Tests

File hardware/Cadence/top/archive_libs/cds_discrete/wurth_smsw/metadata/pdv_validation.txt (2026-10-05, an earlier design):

SPLBPD-170,Cell 'wurth_smsw':Pin(s) K,1,2 is (are) not present in any package or symbol. You can choose Pins - Add from the Package Pin page and delete these pins. If the HAS_FIXED_SIZE value has been reduced, reload the part.,Warning

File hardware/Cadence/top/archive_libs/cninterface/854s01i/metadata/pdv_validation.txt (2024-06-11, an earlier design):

SPLBPD-412,Cell '854s01i':Pin(s) PCLK<0>,NPCLK<0> are present as fixed-size but not present as sizeable on any symbol.,Information

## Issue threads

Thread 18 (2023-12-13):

Remove D-FF from two upstream SFPs. Add mux to allow either direct or via D-FF on third

DavidCussans, 2023-12-13:
The three upstream SFPs can each be connected to a different timing source. Hence return data can't be clocked from same clock.

However, would still like to preserve the ability to have clocking path go direct from clock gen , rather than via FPGA

-->
1. On two SFPs Remove D-FF (driven by the single board PLL) registering the data going from FPGA to SFP Tx
2. On third (primary) SFP, add a 1:2 fanout and 2:1 Mux with straight through in one arm and via D-FF in the other. Use, for example 854S01 as LVDS Mux

DavidCussans, 2024-06-21:
Pete,

Yes, the “issue” doesn’t give much detail.

On two upstream channels remove the D-FF on SFP 0,1 and connect the FPGA directly to the SFP Tx pins:

U8 should be removed and UPSTREAM_DATA_{P,N}(0) connected directly to SFP_TD_{P,N}(0) via C106/C100

U3 should be removed and UPSTREAM_DATA_{P,N}(1) connected directly to SFP_TD_{P,N}(1) via C101/C98

On the third upstream channel it should be possible to switch between direct connect to the FPGA and connection via a D-FF:

SFP_TD_{P,N}(2) should be disconnected from U2 and instead connected to the output of multiplexer IC8 ( 854S01 )

One input of IC8 should be connected to the output of U2

For the other input of IC8 there are two choices:

  1.  Disconnect one pair of AUXIO signals from J4 and instead connect to U8 ( adding DC-blocking capacitors in series and adding 100-Ohm termination resistor near U8)
  2.  Disconnect UPSTREAM_DATA_{P,N}(2) from U2 and connect to the input of a 1:2 LVDS fanout ( Use a SY58608 like IC2 etc. ). One output of the newly added 1:2 fanout should go to the input of U2. The other output should go directly to the second input of U8

I don’t have a preference for which option is chosen ( 1. or 2. ). Go with the lowest staff cost one. Probably option 1. I guess.

Cheers!
   David

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

oxfpete, 2024-06-27:
Think it is almost done, need your eyes to look at schematic.

DavidCussans, 2024-07-03:
Schematic change looks good.
Need to double-check that it is OK to connect the "direct out" signal to B16_L14_P/N

DavidCussans, 2024-07-23:
Need to check that direct output is on suitable FPGA pins.

DavidCussans, 2024-09-11:
Both clocked and direct output data pins are on same bank (16)

Outputs are on the same bank as input

DavidCussans, 2024-09-12:
Closed after review

Closed 2024-09-12.

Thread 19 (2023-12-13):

Allow AVR programming cable to override RESET line from uTCA backplane

DavidCussans, 2023-12-13:
When MIB unplugged from backplane RESET line is asserted. This prevents correct programing of MMC uController (ATMEGA128) via JTAG.

---> Add circuitry that allows programming cable to override RESET line

Suggested:
1. Put 0.1 inch header between input of U15 and GND, to allow a link to de-assert RESET*
2. Add a connection from pin-6 ( RESET* line of ATMEL programming header) to output of U15 ( to allow programming header to pull RESET* low. Add a zero ohm link in this path, because David isn't entirely sure of what he is doing...

oxfpete, 2024-06-19:
Done.

DavidCussans, 2024-07-03:
Schematic looks good.

DavidCussans, 2024-07-22:
PL1 needs to move. The space between the two mounting holes is taken up with a solid block of plastic that stabilized the joint between the main PCB and the tongue-2 PCB

oxfpete, 2024-07-23:
PL1 moved closer to C58

oxfpete, 2024-07-24:
PL1 well away from C58 and original position, above SK1 and clear of Trenz module

DavidCussans, 2024-07-24:
Looks Good To Me

Dr David Cussans                    University of Bristol,
office: +44-(117)-95 46879   H.H. Wills Physics Laboratory,
     lab: +44-(117)-33 17199   Tyndall Avenue,
     fax: +44-(117)-925 5624   Bristol BS8 1TL, UK
________________________________
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

DavidCussans, 2024-09-12:
Problem spotted - this allows us to program on bench,
but Stoyan points out that this won't allow us to program in crate - since MCH will apply reset at intervals

Conclusion - Pass for pre-production. Continue investigation

Closed 2024-09-12.

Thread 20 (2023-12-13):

Replace 0.1-inch header for MMC uController programming with 0.05-inch header (to match modern cables)

DavidCussans, 2023-12-13:
Replace 0.1-inch header for MMC programming (J13)  with 0.05-inch header (to match modern cables)

oxfpete, 2024-06-21:
Samtec SHF-105-01-L-D-SM in place of 0.1" connector. Done.

DavidCussans, 2024-07-03:
Looks good.

DavidCussans, 2024-07-23:
PCB looks good

Closed 2024-07-23.

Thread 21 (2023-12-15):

Alter RESET line on MMC uController so that uController can be programmed with MIB out of crate

DavidCussans, 2023-12-15:
Having RESET line asserted (almost always) prevents JTAG control of MMC uController

Alter RESET line circuitry  on MMC uController so that uController can be programmed with MIB out of crate

DavidCussans, 2024-06-12:
Duplicate issue. Closing

Closed 2024-06-12.

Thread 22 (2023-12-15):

Add fuses to main 12V and 3.3V management power line from backplane

DavidCussans, 2023-12-15:
Fermilab electrical safety reportedly insist on fuses at power input to boards. This isn't usually done on uTCA boards, but add fuses to make life easier for ourselves

Normal operating power for MIB ~ 12W ( i.e. 1A from 12V )

Put in 3A slow-blow surface mount fuse.

oxfpete, 2024-06-21:
SF-0603FP015F-2 will used on 3V3 line, it is a 150mA fast fuse - hopefully has enough head room to compensate for in rush at power on. 100mA was originally requested but not available in slow-blow as an 0603.

oxfpete, 2024-06-21:
Done.

DavidCussans, 2024-07-03:
Schematic looks good.

DavidCussans, 2024-07-23:
Measure plastic blocks between main PCB and tongue-2 and make sure that FS2 doesn't interfere

oxfpete, 2024-07-24:
F2 and F1 moved well away from plastic block locations

oxfpete, 2024-07-24:
R11 may still be close - please check

DavidCussans, 2024-07-24:
R11 is OK. It doesn't get squashed under the plastic block on the current design so doesn't need moving.

( The block is 6mm wide (+/- 3mm) , and R11is 4.36mm below the mounting holes )

Dr David Cussans                    University of Bristol,
office: +44-(117)-95 46879   H.H. Wills Physics Laboratory,
     lab: +44-(117)-33 17199   Tyndall Avenue,
     fax: +44-(117)-925 5624   Bristol BS8 1TL, UK
________________________________
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

DavidCussans, 2024-09-12:
Not necessary since FNAL safety office have accepoted that uTCA baords don't need fuse.

However, reduces QC requirements on MMC code, so leave in.

Passed after review

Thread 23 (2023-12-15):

Replace DNF resistors R81,R83 with 100nF capacitors

DavidCussans, 2023-12-15:
The current sense resistors in 2.5V , 3.3V lines seem to prevent PTH08T210WAD from operating if voltage is sensed from far side of resistor.
Want accurate voltage regulation
Replace DNF resistors R81,R83 with 100nF capacitors. This seems to solve the issue.

Experiment with also replacing R69,R84 with 1-Ohm resistors

oxfpete, 2024-06-21:
R81/R83 replace with 100nF - done

oxfpete, 2024-06-21:
R69/R84 now 1 Ohm 0603 resistors

DavidCussans, 2024-07-03:
Schematic looks good.

Closed 2024-07-23.

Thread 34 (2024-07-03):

uTCA handle almost shorts to C51. Move C51

DavidCussans, 2024-07-03:
uTCA handle almost shorts to C51 when pushed in ( evident when front panel attached to MIB)

 Move C51 at least 2mm left

Perhaps rotate 3-pin jumper J12 through 90-degrees and move to the right of C51 , above SW1

Closed 2024-07-23.

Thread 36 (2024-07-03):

PRESENCE_12V line ( currently connected to PA1 ) should be connected to PF0 .

DavidCussans, 2024-07-03:
PRESENCE_12V line ( currently connected to PA1 , which is a digital-only line ) should be connected to PF0 instead ( which can function as an ADC )

oxfpete, 2024-07-03:
Done and done.

DavidCussans, 2024-07-03:
Needs a correction:
DCDC_3V3_PG has been connected to PF0 , *not* PRESENCE_12V

DavidCussans, 2024-07-03:
Updated schematic looks good.

DavidCussans, 2024-07-23:
Patched MMC works in Bristol.

Closed 2024-07-23.

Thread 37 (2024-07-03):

dcdc_2v5_pg line should be moved from PE6 to PF1

DavidCussans, 2024-07-03:
the dcdc_2v5_pg signal is connected to PE6 (which is a digital-only pin) . It should be moved to PF1 ( and ADC capable pin)

Less important than issue

oxfpete, 2024-07-03:
Done.

DavidCussans, 2024-07-23:
Layout looks good. Not tested in hardware but not a show-stopper so closing.

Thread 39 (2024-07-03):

All I2C current/voltage/temperatures sensors should be powered from MP3V3 , not just the temperature sensor.

DavidCussans, 2024-07-03:
U25 (temperature sensor) is powered from MP3V3 . This is good since it allows the temperature to be measured , even it the main board power isn't switched on.

IC6 is powered form VCC3V3. This is bad, since when VCC3V3 is not enabled ( at ~ 0V ) the I2C lines are pulled low and prevent the temperature monitoring working.

--> Change VCC=VCC3V3 on IC6 to VCC=MP3V3 .

if MP3V3 drops then the DC-DC converters will shut down, so it should be safe to connect the voltage inputs of IC6 to the output of the DC-DC converters

DavidCussans, 2024-09-12:
Closed after review

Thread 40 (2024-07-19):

Pull ADR0 pin on the LT2991 voltage sensor high (rather than low)

DavidCussans, 2024-07-19:
Address clash on I2C bus.

--> pull ADR0 pin (pin 13) on U6, the voltage sensor high (rather than low) . Keep resistor in series (just in case... )

DavidCussans, 2024-07-24:
Schematic change LGTM

Closed 2024-09-12.

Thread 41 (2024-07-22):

One mounting block for tongue-2 PCB needs to have recess milled to avoid C188/C189

DavidCussans, 2024-07-22:
There are plastic blocks that fit between the main MIB PCB and the tongue-2 PCB
( between MH7 and MH8 , MH9 and MH 10 ).

One the the plastic blocks covers C188/C189. Moving the caps seems like a PITA, so remember to add a milled recess into the CAD design for the blocks.

(N.B. - Get the CAD drawing from Keith and add to the repository.)

oxfpete, 2024-07-24:
Caps moved to back side, plastic blocks should both be clear of components

DavidCussans, 2024-07-24:
Looks good.

Dr David Cussans                    University of Bristol,
office: +44-(117)-95 46879   H.H. Wills Physics Laboratory,
     lab: +44-(117)-33 17199   Tyndall Avenue,
     fax: +44-(117)-925 5624   Bristol BS8 1TL, UK
________________________________
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

DavidCussans, 2024-09-12:
Closed - DGC checked last night

Closed 2024-09-12.

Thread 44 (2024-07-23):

Move  blue LED to correct position to follow uTCA standard.

DavidCussans, 2024-07-23:
Blue LED should be on the underside of the board near the front ( i.e. near the extraction handle)

Images taken from AFC design using Altium Designer:

(Looking at the board it seems that the LED would be better aligned with light pipe if about 0.5mm higher ( further away from the bottom of the board)

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

Photograph of AFC in crate with blue LED illuminated:
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

Another photo of AFC:
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

oxfpete, 2024-07-24:
I don't think the new position is correct at all on the layout I have just submitted. Is that mounting point on the PCB I have?

DavidCussans, 2024-07-24:
The blue LED is in roughly the right place - on the bottom near the front of the board - but needs tweaking.

The image at https://github.com/user-attachments/assets/12ca9d7b-fdcc-4e8c-895e-896952bf6baa shows the position relative to MH6 on the DUNE MIB. ( There are other holes on the AFC which are used to mount the FMCs but these aren't present on the MIB ).

In its new position LED also needs to be a "side launch" (like on the FIB ) to type to shine the light horizontally (rather than a vertical mount )

Dr David Cussans                    University of Bristol,
office: +44-(117)-95 46879   H.H. Wills Physics Laboratory,
     lab: +44-(117)-33 17199   Tyndall Avenue,
     fax: +44-(117)-925 5624   Bristol BS8 1TL, UK

________________________________
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

DavidCussans, 2024-08-28:
Blue LED , DS1 still needs to be moved.

oxfpete, 2024-09-02:
Done

DavidCussans, 2024-09-11:
Checked on mib_rev3ox_v223.

Looks Good To Me

Closed 2024-09-12.

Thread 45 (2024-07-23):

Check to see if data from Endpoints arrives on clock-capable pins on FPGA.

DavidCussans, 2024-07-23:
Would give ability to measure fine-phase of returning data.
May be difficult to implement.

DavidCussans, 2024-07-31:
May not be needed. Phase measurement blocks use BUFR which can be driven by normal I/O

strilov, 2024-09-17:
CC pins with non-clock input

bank 13:

```
Y11   IO_L11P_T1_SRCC_13
Y12   IO_L11N_T1_SRCC_13
```

```
W11   IO_L12P_T1_MRCC_13
W12   IO_L12N_T1_MRCC_13
```

```
U15   IO_L14P_T2_SRCC_13
V15   IO_L14N_T2_SRCC_13
```

bank 14:
```
U20   IO_L11P_T1_SRCC_14
V20   IO_L11N_T1_SRCC_14
```

```
W19   IO_L12P_T1_MRCC_14
W20   IO_L12N_T1_MRCC_14
```

```
Y18   IO_L13P_T2_MRCC_14
Y19   IO_L13N_T2_MRCC_14
```

```
V18   IO_L14P_T2_SRCC_14
V19   IO_L14N_T2_SRCC_14
```

bank 15:
```
J20   IO_L11P_T1_SRCC_15
J21   IO_L11N_T1_SRCC_15
```

```
K18   IO_L13P_T2_MRCC_15
K19   IO_L13N_T2_MRCC_15
```

bank 16:
```
B17   IO_L11P_T1_SRCC_16
B18   IO_L11N_T1_SRCC_16
```

```
E19   IO_L14P_T2_SRCC_16
D19   IO_L14N_T2_SRCC_16
```

CC pins with clock input (not available)

```
data_from_upstream_0
V13   IO_L13P_T2_MRCC_13
V14   IO_L13N_T2_MRCC_13
```

```
data_from_upstream_1
L19   IO_L14P_T2_SRCC_15
L20   IO_L14N_T2_SRCC_15
```

```
data_from_upstream_2
D17   IO_L12P_T1_MRCC_16
C17   IO_L12N_T1_MRCC_16
```

```
CLK_GEN_IN_1
J19   IO_L12P_T1_MRCC_15
H19   IO_L12N_T1_MRCC_15
```

```
CLK_GEN_IN_0
C18   IO_L13P_T2_MRCC_16
C19   IO_L13N_T2_MRCC_16
```

strilov, 2024-09-29:
One option to get 10/12 BP data links into CC pins, with some caveats:

* Some PLL/SFP controls signals move to 2.5V IO (from 3.3V on bank 14). 2.5V CMOS output levels should be compatible with 3.3V CMOS input levels.
* Artix 7 does not support LVDS_33, and bank 14 is fixed at 3.3V. Artix 7 does support the LVDS25 inputs into IO bank at a different voltage, but internal termination cannot be used -> external termination required.

```
swaps to free up B14_L11
SFP_TX_DISABLE_0 : B14_L8_N -> B15_L18_P (output 2.5V CMOS into 3.3V input on SFP)
SFP_TX_FAULT_0 : B14_L8_P -> B14_L24_P
SFP_TX_FAULT/LOS 2 : B14_L11 -> B14_L8
BP_DATA_IN_3: B16_L24 -> B14_L11 (LVDS25 into 3.3V IO bank, will require external termination)
```

```
swaps to free up B14_L12
CLK_SEL: B14_L10 -> B15_L23 (output 2.5V into 3.3V input on PLL)
CLK_GEN INTR/LOL : B14_L12 -> B14_L10
BP_DATA_IN_9: B16_L16 -> B14_L12 (LVDS25 into 3.3V IO bank, will require external termination)
```

```
swaps to free up B14_L14
SFP_TX_DISABLE_1 : B14_L17_P -> B15_L16_P (output 2.5V into 3.3V input on SFP)
SFP_LOS_1 : B14_L14_P -> B14_L17_P
SFP_TX_DISABLE_2 : B14_L14_N -> B15_L16_N (output 2.5V into 3.3V input on SFP)
BP_DATA_IN_8: B16_L19 -> B14_L14 (LVDS25 into 3.3V IO bank, will require external termination)
```

```
BP_DATA_IN_0: B13_L3 -> B13_L14
```

```
BP_DATA_OUT_5 : B13_L11 -> B13_L9
BP_DATA_IN_1: B13_L9 -> B13_L11
```

```
BP_DATA_IN_4: B16_L23 -> B15_L13
```

```
BP_DATA_OUT_4: B15_L11 -> B15_L3
BP_DATA_IN_5: B16_L20 -> B15_L11
```

```
DIRECT_US_DATA_2:  B16_L14 -> B16_L10
BP_DATA_IN_7: B16_L18 -> B16_L14
```

```
BP_DATA_IN_6: B16_L9 -> B16_L11
```

```
AUXIO_2: B13_L12 -> B13_L2
BP_DATA_IN_2: B16_L22  -> B13_L12
```

Closed 2024-09-12.

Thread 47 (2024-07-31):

Move red and green LEDs to "standard" positions for Schroff/nvent front panel mechanism. Remove existing light-pipe and rely on front panel mechanism

DavidCussans, 2024-07-31:
Schroff/nVent front panel mechanism includes light pipes for the two auxilliary LEDs ( red / green )
( https://schroff.nvent.com/en-gb/products/enc20849-153 )

--> Remove existing light-pipe (U1)

--> Move Red and Green LEDs to correct positions to suit nVent light pipe
( https://schroff.nvent.com/sites/g/files/hdkjer281/files/acquiadam_assets/2021-06/70849-045.pdf )
... the Blue LED has already been moved in issue #44
N.B.
1. Can probably measure positions from AFC
2. The LED nearest front of board should be replaced with an "edge launch" . The one furthest away should stay as vertical launch.
3. The edge launch LED (shining out of the crate) is on the top surface. The vertical (perpendicular to the board into light pipe) LED is on the bottom surface.
4.

DavidCussans, 2024-08-28:
mob_rev3ox_v221.brd looks like LED positions incorrect.

on LED D1 with respect to mounting hole: delta-x = 6.97mm , delta-y = 1.1mm ,

looking at AFC design it looks like this should be delta-x = 5.583mm , delta-y = 1.069mm . i.e. y position OK within tolerance, x position needs to be shifted by ~ 1.4mm

Screenshot from Altium: 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

oxfpete, 2024-09-02:
LED D1 moved.

DavidCussans, 2024-09-12:
Closing since
1. Checked by DGC
2. WOn't stop the board working

Closed 2024-09-12.

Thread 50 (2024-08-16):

Swap differential pairs to allocate each upstream SFP I/O to a separate bank/clock region on FPGA

DavidCussans, 2024-08-16:
Currently all three `data_from_upstream` differential pairs are attached to the same FPGA bank ( 13) . This means an extra BUFG is required to get the data to the MMCM that generates the clock for that endpoint.

In addition the data returning upstream ( `upstream_data_p/n[2..0]` ) are all on bank 15.

Swap pairs to put `data_from_upstream[0]` and `upstream_data[0]` on bank 13, `data_from_upstream[1]` and `upstream_data[1]` on bank 15, and `data_from_upstream[2]` and `upstream_data[2]` on bank 16

As far as I can see the can be done by the swapping the following four differential pairs:

<html xmlns:v="urn:schemas-microsoft-com:vml"
xmlns:o="urn:schemas-microsoft-com:office:office"
xmlns:x="urn:schemas-microsoft-com:office:excel"
xmlns="http://www.w3.org/TR/REC-html40">

Swap pairs: |  
-- | --
data_from_upstream_p/n[1], Y11 | data_out_p/n[5], L19
data_from_upstream_p/n[2], W11 | auxio_p/n[2]  , D17
upstream_data_p/n[0] , H13 | data_in_p/n[11] , W14
upstream_data_p/n[2] , G17 | auxio_p/n[3] , B13

</body>

</html>

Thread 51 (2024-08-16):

Attach SMD test pad to ATMEGA128 UART0 transmit pin ( PE1 ) to give us more debug options.

DavidCussans, 2024-08-16:

DavidCussans, 2024-09-12:
Not done.
Closing since won't stop board working.
And we have more confidence in MMC code since this issue was opened.

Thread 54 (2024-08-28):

Swap pins 1,3,5 of J4 from GND to VCC3v3 ( to allow powering of LEDs on daughter board)

DavidCussans, 2024-08-28:
There are no LEDs to indicate the status of the upstream links on the MIB.

Add +3.3V power to allow LEDs on daughterboard to be powered from main board.

Swap pins 1,3,5 of J4 from GND to vcc3v3

The attached screenshot shows which pins:
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

oxfpete, 2024-09-02:
Done.

DavidCussans, 2024-09-12:
Closed on review

Closed 2024-09-12.

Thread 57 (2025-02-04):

IC5 on MIB v3 (pre-production MIB) assembled incorrectly

DavidCussans, 2025-02-04:
Hi5 assembled IC5 the wrong way round.
This is an assembly error rather than design error but the Silk could be clearer.
Actions:
1. Rotate IC5 text to make orientation clearer.
2. Send 3D file to assembly house to make it clearer.

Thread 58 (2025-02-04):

IC5 on MIB v3 (pre-production MIB) assembled incorrectly

DavidCussans, 2025-02-04:
Hi5 assembled IC5 the wrong way round.
This is an assembly error rather than design error but the Silk could be clearer.
Actions:
1. Rotate IC5 text to make orientation clearer.
2. Send 3D file to assembly house to make it clearer.

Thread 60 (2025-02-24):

Front panel switch , SW1 , is 180-degrees wrong rotation

DavidCussans, 2025-02-24:
uTCA front panel switch should be rotated by 180-degrees.

Mounting lugs are fat , thin - so can't just give instructions to mount the wrong way way round.

DavidCussans, 2025-02-24:
Should be fixed in mtca_interface_board_reocc/top_mib_v3/physical/mib_rev3b_v225.brd . Check then close.

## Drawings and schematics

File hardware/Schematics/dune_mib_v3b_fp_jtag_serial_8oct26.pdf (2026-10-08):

## 3.3V POWER ON "AUXIO" CONNECTOR

## JTAG FOR FPGA

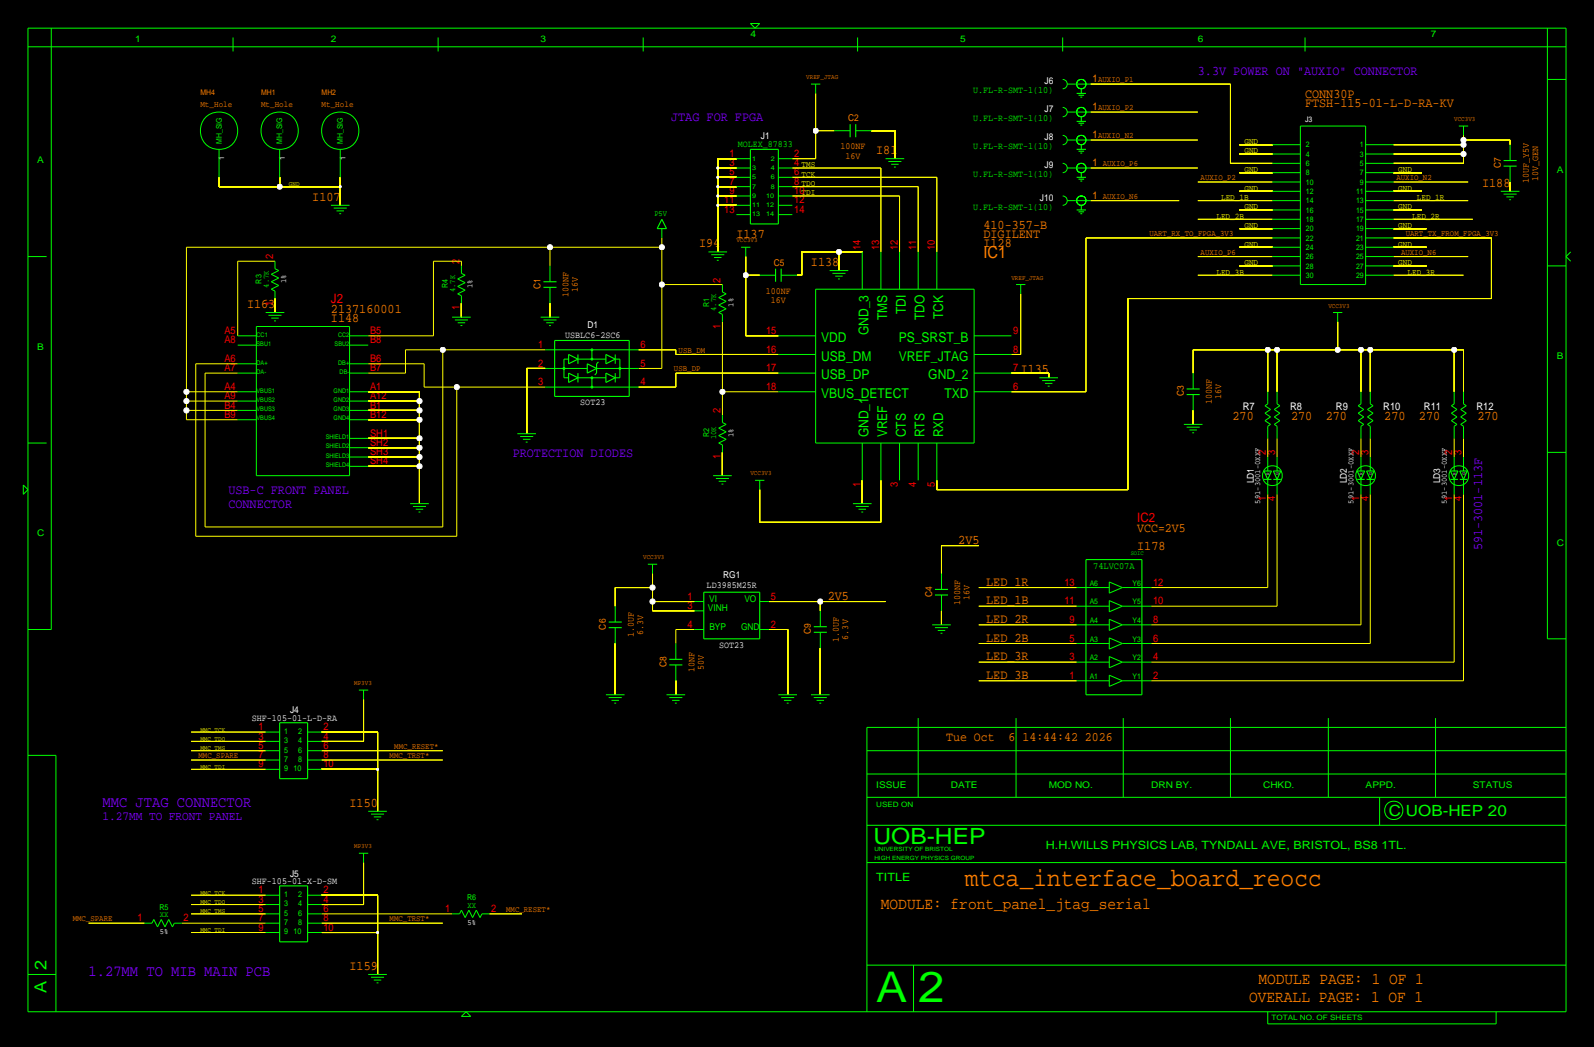
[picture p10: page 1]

3.3V POWER ON "AUXIO" CONNECTOR

3 3 | TMS
5 5 | 6 6 TCK TCK
7 7 | 8 8 TDO TDO
9 9 | 10 10

A9 A9 | A12
B4 B4 | B1 B1
B9 B9 | B12

Tue Oct 6 | 14:44:42 2026

ISSUE | DATE | MOD NO. | DRN BY. | CHKD. | APPD. | STATUS

USED ON | C UOB-HEP 20

H.H.WILLS PHYSICS LAB, TYNDALL AVE, BRISTOL, BS8 1TL.
mtca_interface_board_reocc

UNIVERSITY OF BRISTOL
HIGH ENERGY PHYSICS GROUP
TITLE
MODULE: front_panel_jtag_serial

TOTAL NO. OF SHEETS

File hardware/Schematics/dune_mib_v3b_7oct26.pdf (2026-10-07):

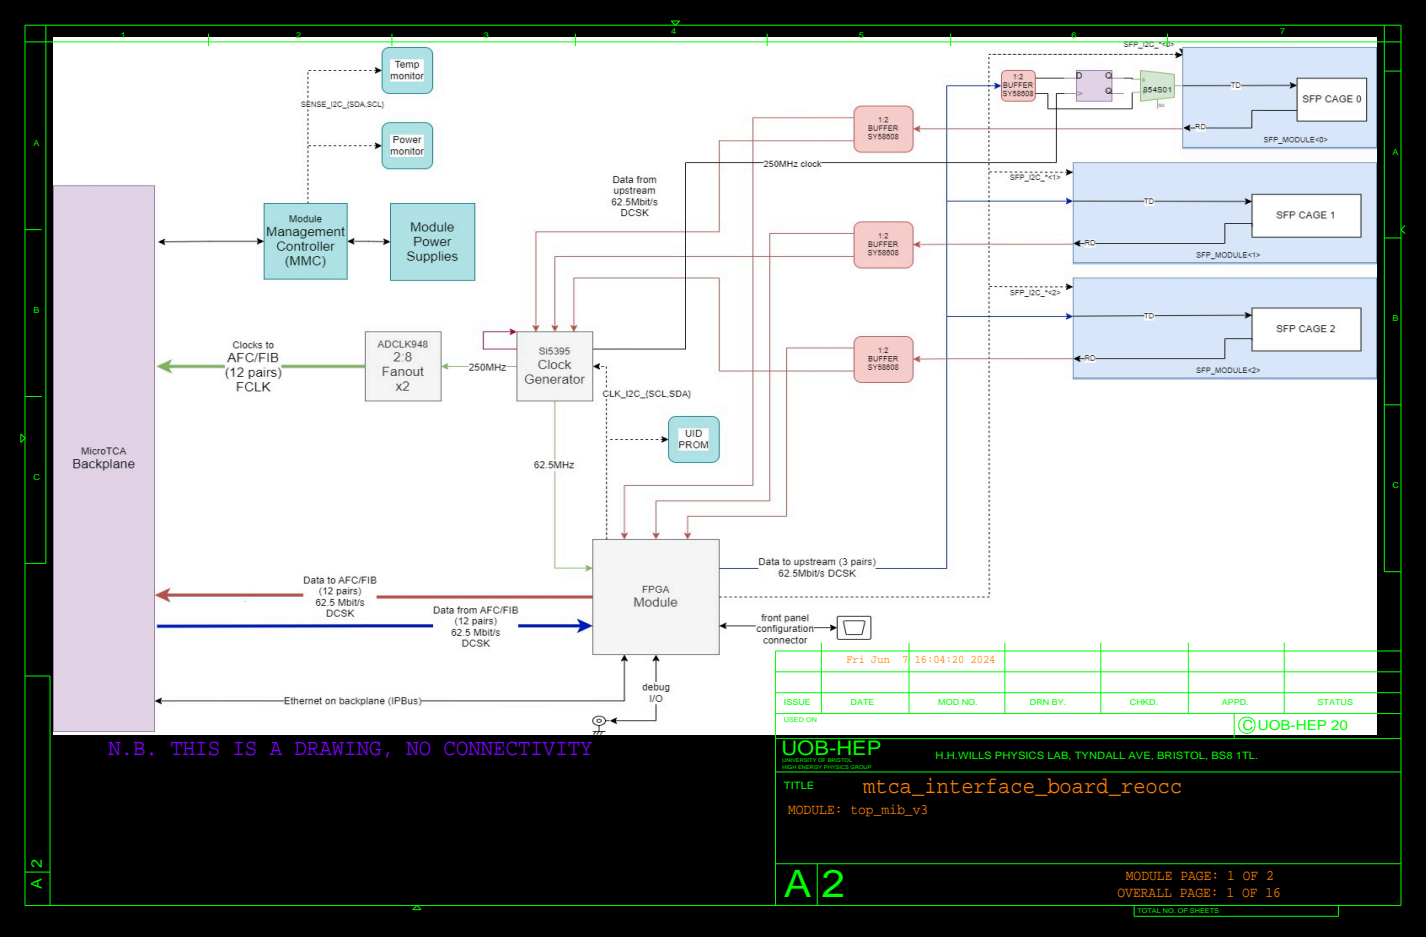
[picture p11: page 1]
Fri Jun 7; mtca_interface_board_reocc; UOB-HEP

ISSUE | DATE | MOD NO. | DRN BY. | CHKD. | APPD. | STATUS

USED ON | C UOB-HEP 20

N.B. THIS IS A DRAWING, NO CONNECTIVITY

H.H.WILLS PHYSICS LAB, TYNDALL AVE, BRISTOL, BS8 1TL.
mtca_interface_board_reocc

UNIVERSITY OF BRISTOL
HIGH ENERGY PHYSICS GROUP
TITLE
MODULE: top_mib_v3

MODULE PAGE: 1 OF 2
OVERALL PAGE: 1 OF 16

TOTAL NO. OF SHEETS

## ROOM=POWER

# BACKPLANE_INTERFACE 07. BACKPLANE INTERFACE

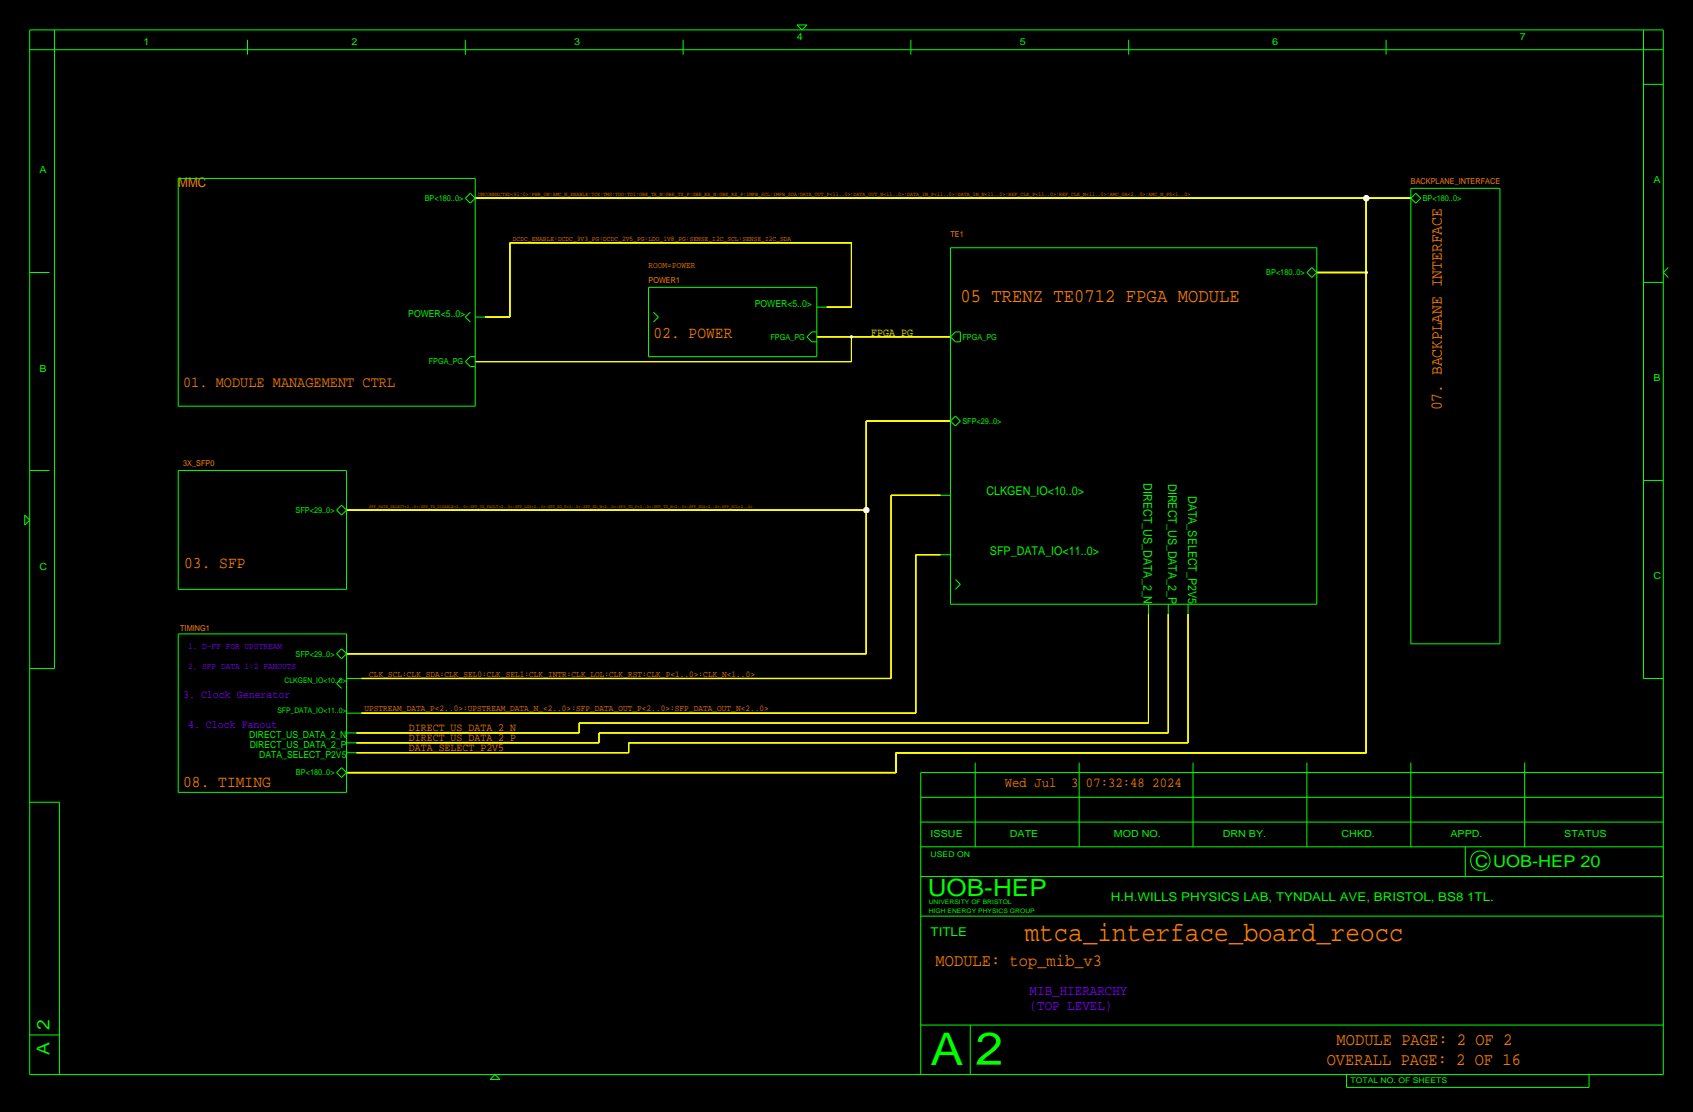
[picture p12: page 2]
MIB_HIERARCHY (TOP LEVEL); Wed Jul 3; mtca_interface_board_reocc; SFP_RATE_SELECT<2..0>:SFP_TX_DISABLE<2..0>:SFP_TX_FAULT<2..0>:SFP_LOS<2..0>:SFP_RD_P<2..0>:SFP_RD_N<2..0>:SFP_TD_P<2..0>:SFP_TD_N<2..0>:SFP_SDA<2..0>:SFP_SCL<2..0>; CLK_SCL:CLK_SDA:CLK_SEL0:CLK_SEL1:CLK_INTR:CLK_LOL:CLK_RST:CLK_P<1..0>:CLK_N<1..0>; UPSTREAM_DATA_P<2..0>:UPSTREAM_DATA_N_<2..0>:SFP_DATA_OUT_P<2..0>:SFP_DATA_OUT_N<2..0>; DATA_SELECT_P2V5; DIRECT_US_DATA_2_P; DIRECT_US_DATA_2_N; 03. SFP; 08. TIMING; FPGA_PG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

UNCONNECTED<91:0>:PWR_ON:AMC_N_ENABLE:TCK:TMS:TDO:TDI:GBE_TX_N:GBE_TX_P:GBE_RX_N:GBE_RX_P:IMPB_SCL:IMPB_SDA:DATA_OUT_P<11..0>:DATA_OUT_N<11..0>:DATA_IN_P<11..0>:DATA_IN_N<11..0>:REF_CLK_P<11..0>:REF_CLK_N<11..0>:AMC_GA<2..0>:AMC_N_PS<1..0>

05 TRENZ TE0712 FPGA MODULE

01. MODULE MANAGEMENT CTRL

TIMING1
1. D-FF FOR UPSTREAM
2. SFP DATA 1:2 FANOUTS
3. Clock Generator
4. Clock Fanout

ISSUE | DATE | MOD NO. | DRN BY. | CHKD. | APPD. | STATUS

USED ON | C UOB-HEP 20

H.H.WILLS PHYSICS LAB, TYNDALL AVE, BRISTOL, BS8 1TL.
mtca_interface_board_reocc

UNIVERSITY OF BRISTOL
HIGH ENERGY PHYSICS GROUP
TITLE
MODULE: top_mib_v3

# VP3V3 IV MONITOR

# 12V @ 6.6A IN

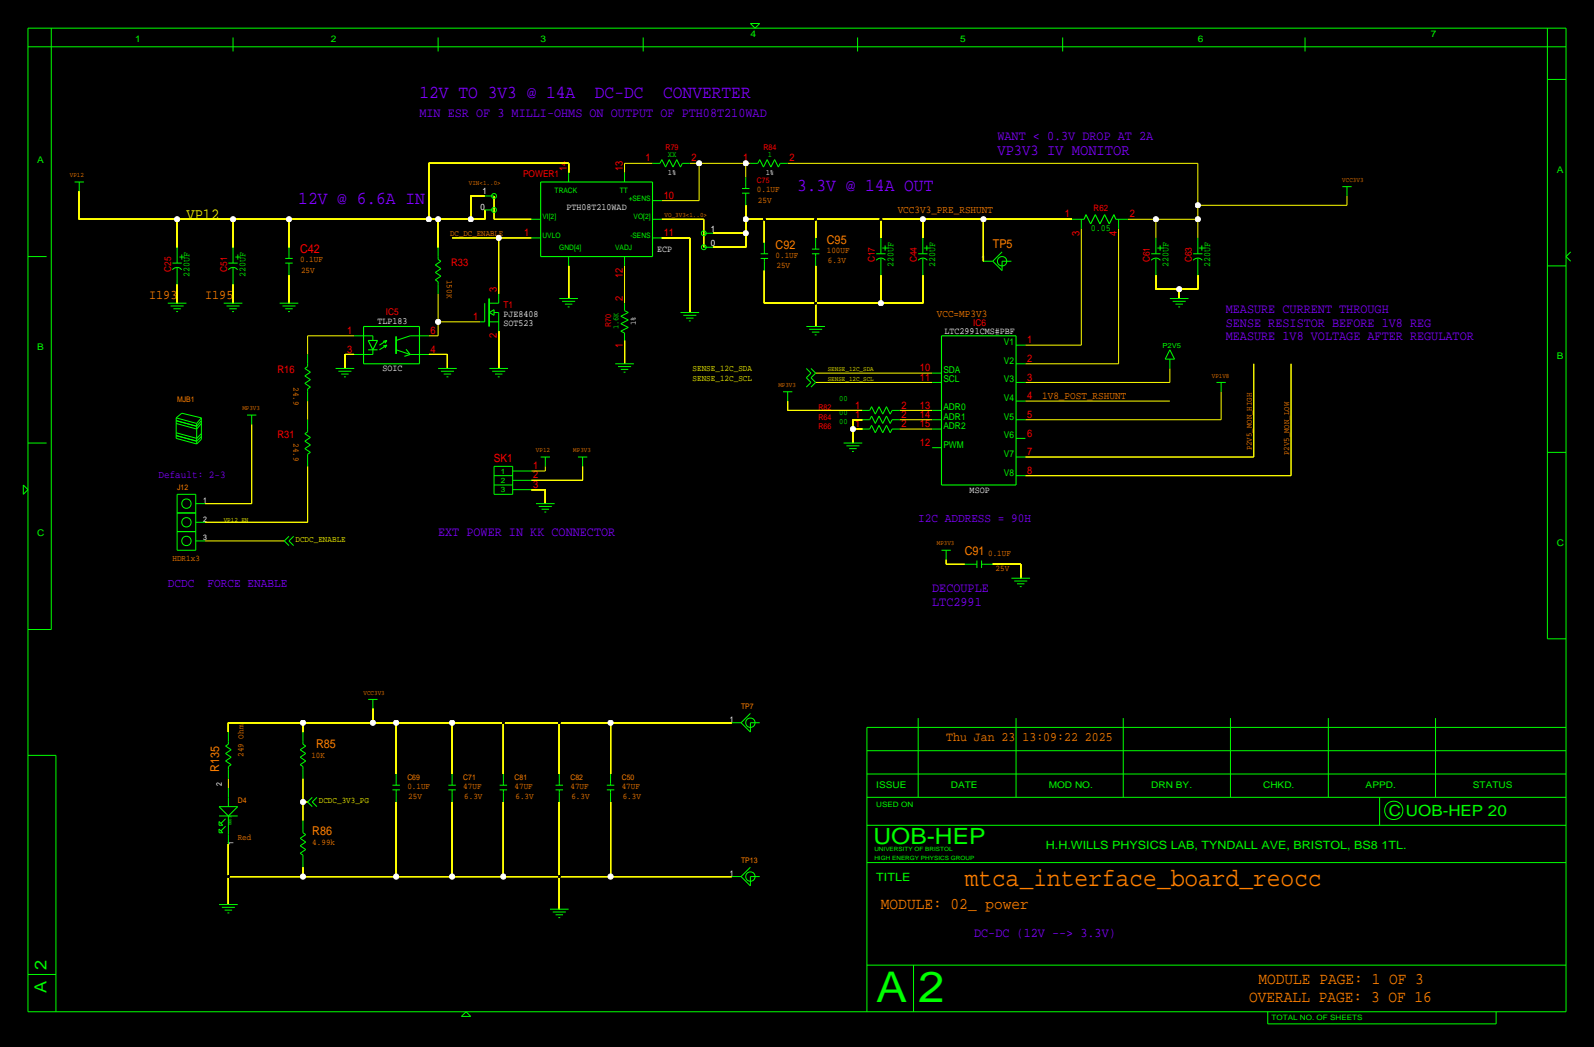
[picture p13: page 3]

12V TO 3V3 @ 14A DC-DC CONVERTER
MIN ESR OF 3 MILLI-OHMS ON OUTPUT OF PTH08T210WAD

MEASURE CURRENT THROUGH
SENSE RESISTOR BEFORE 1V8 REG
MEASURE 1V8 VOLTAGE AFTER REGULATOR

EXT POWER IN KK CONNECTOR

ISSUE | DATE | MOD NO. | DRN BY. | CHKD. | APPD. | STATUS

USED ON | C UOB-HEP 20

H.H.WILLS PHYSICS LAB, TYNDALL AVE, BRISTOL, BS8 1TL.
mtca_interface_board_reocc

UNIVERSITY OF BRISTOL
HIGH ENERGY PHYSICS GROUP
TITLE
MODULE: 02_ power

# WANT <0.3V DROP AT 2A

# P2V5 IV MONITOR

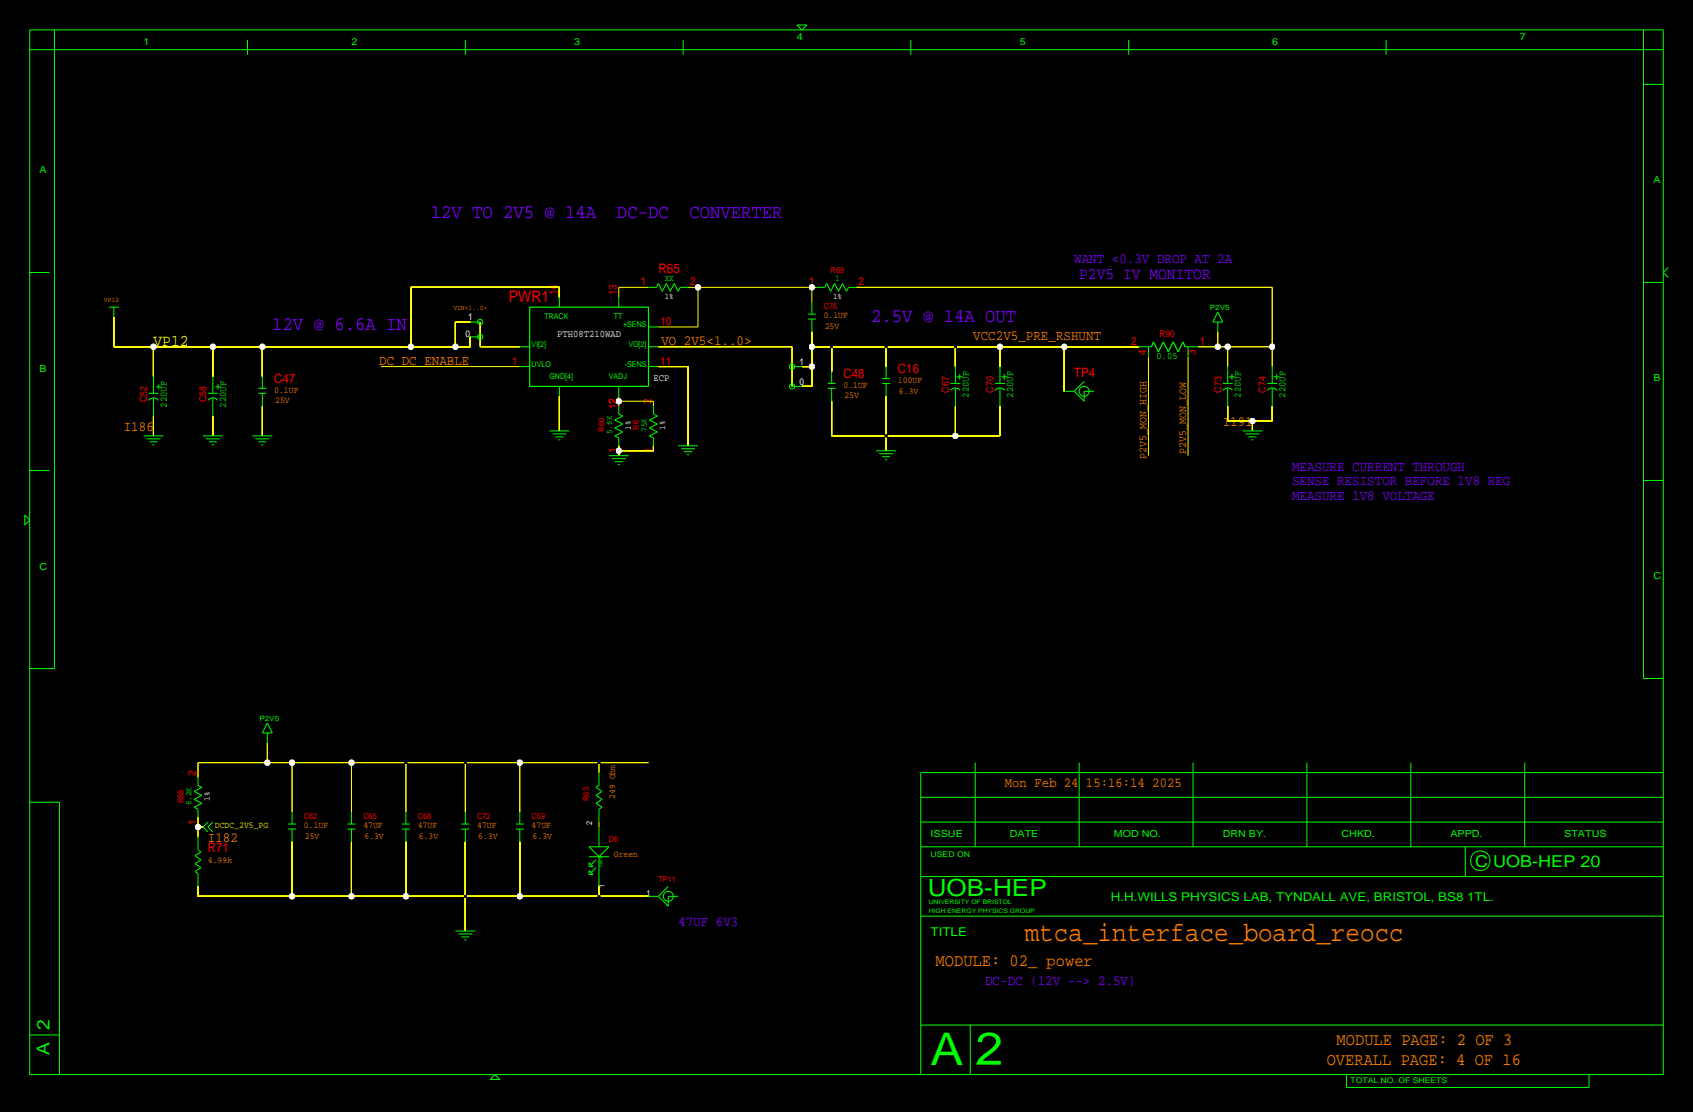
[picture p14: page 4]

12V TO 2V5 @ 14A DC-DC CONVERTER

MEASURE CURRENT THROUGH
SENSE RESISTOR BEFORE 1V8 REG
MEASURE 1V8 VOLTAGE

ISSUE | DATE | MOD NO. | DRN BY. | CHKD. | APPD. | STATUS

USED ON | C UOB-HEP 20

H.H.WILLS PHYSICS LAB, TYNDALL AVE, BRISTOL, BS8 1TL.
mtca_interface_board_reocc

UNIVERSITY OF BRISTOL
HIGH ENERGY PHYSICS GROUP
TITLE
MODULE: 02_ power

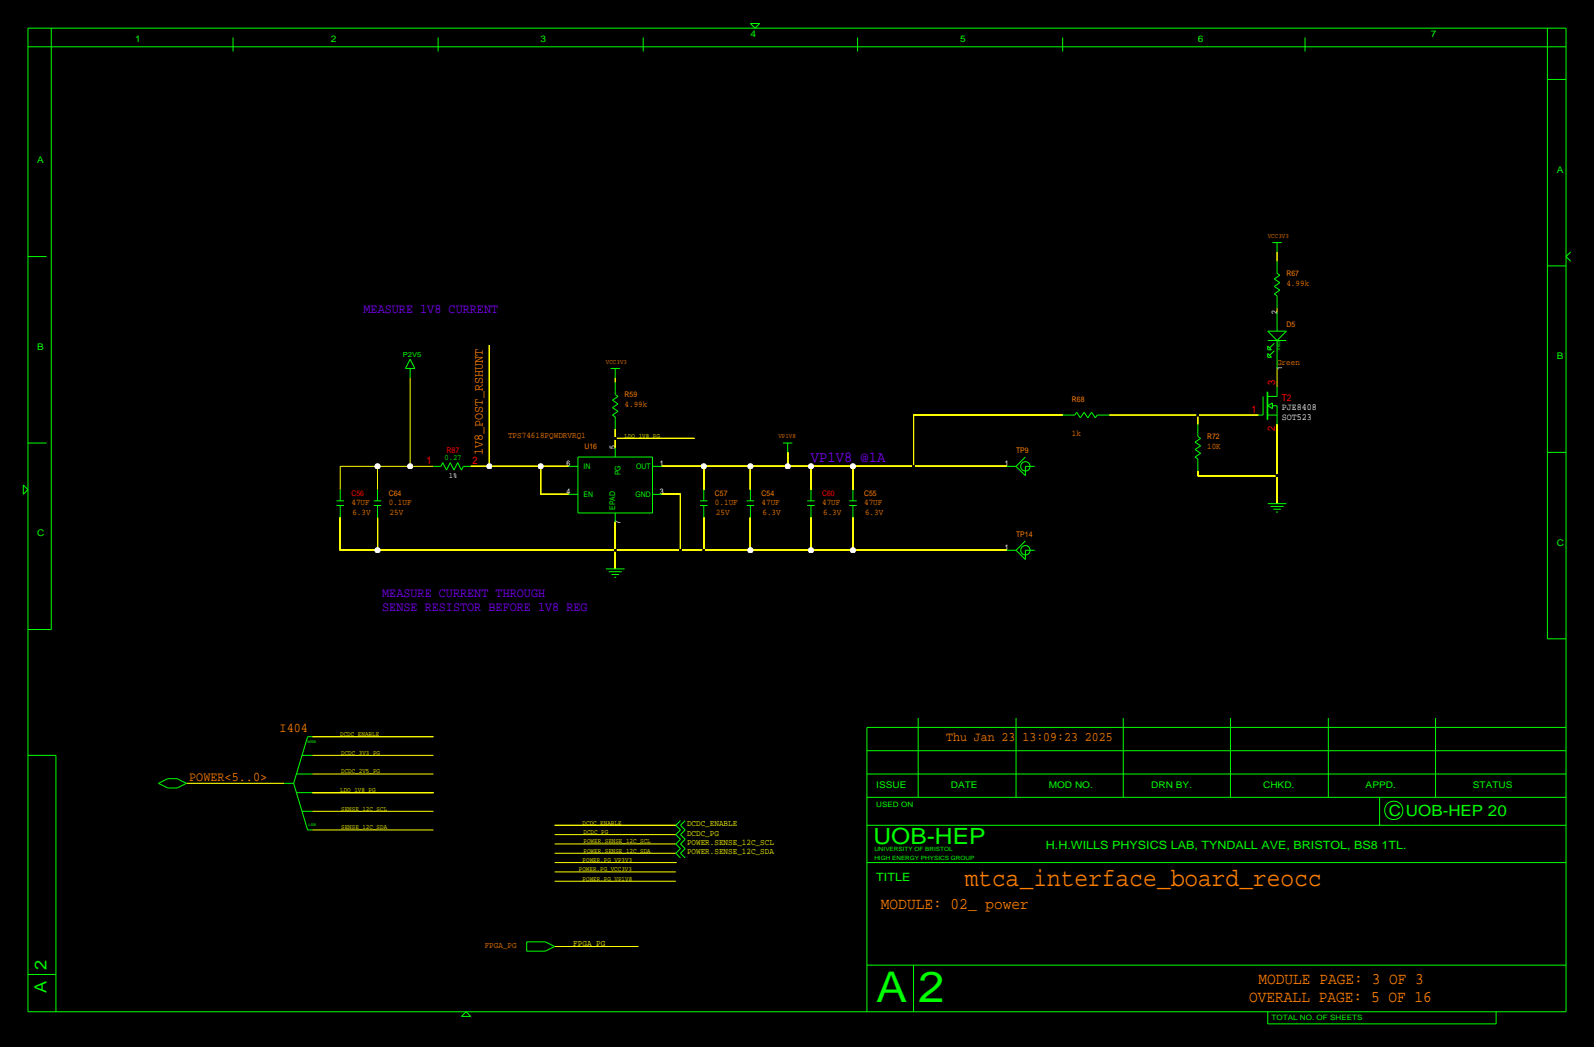
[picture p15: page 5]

MEASURE CURRENT THROUGH
SENSE RESISTOR BEFORE 1V8 REG

ISSUE | DATE | MOD NO. | DRN BY. | CHKD. | APPD. | STATUS

USED ON | C UOB-HEP 20

H.H.WILLS PHYSICS LAB, TYNDALL AVE, BRISTOL, BS8 1TL.
mtca_interface_board_reocc

UNIVERSITY OF BRISTOL
HIGH ENERGY PHYSICS GROUP
TITLE
MODULE: 02_ power

# SFP DATA TO FPGA

IC1

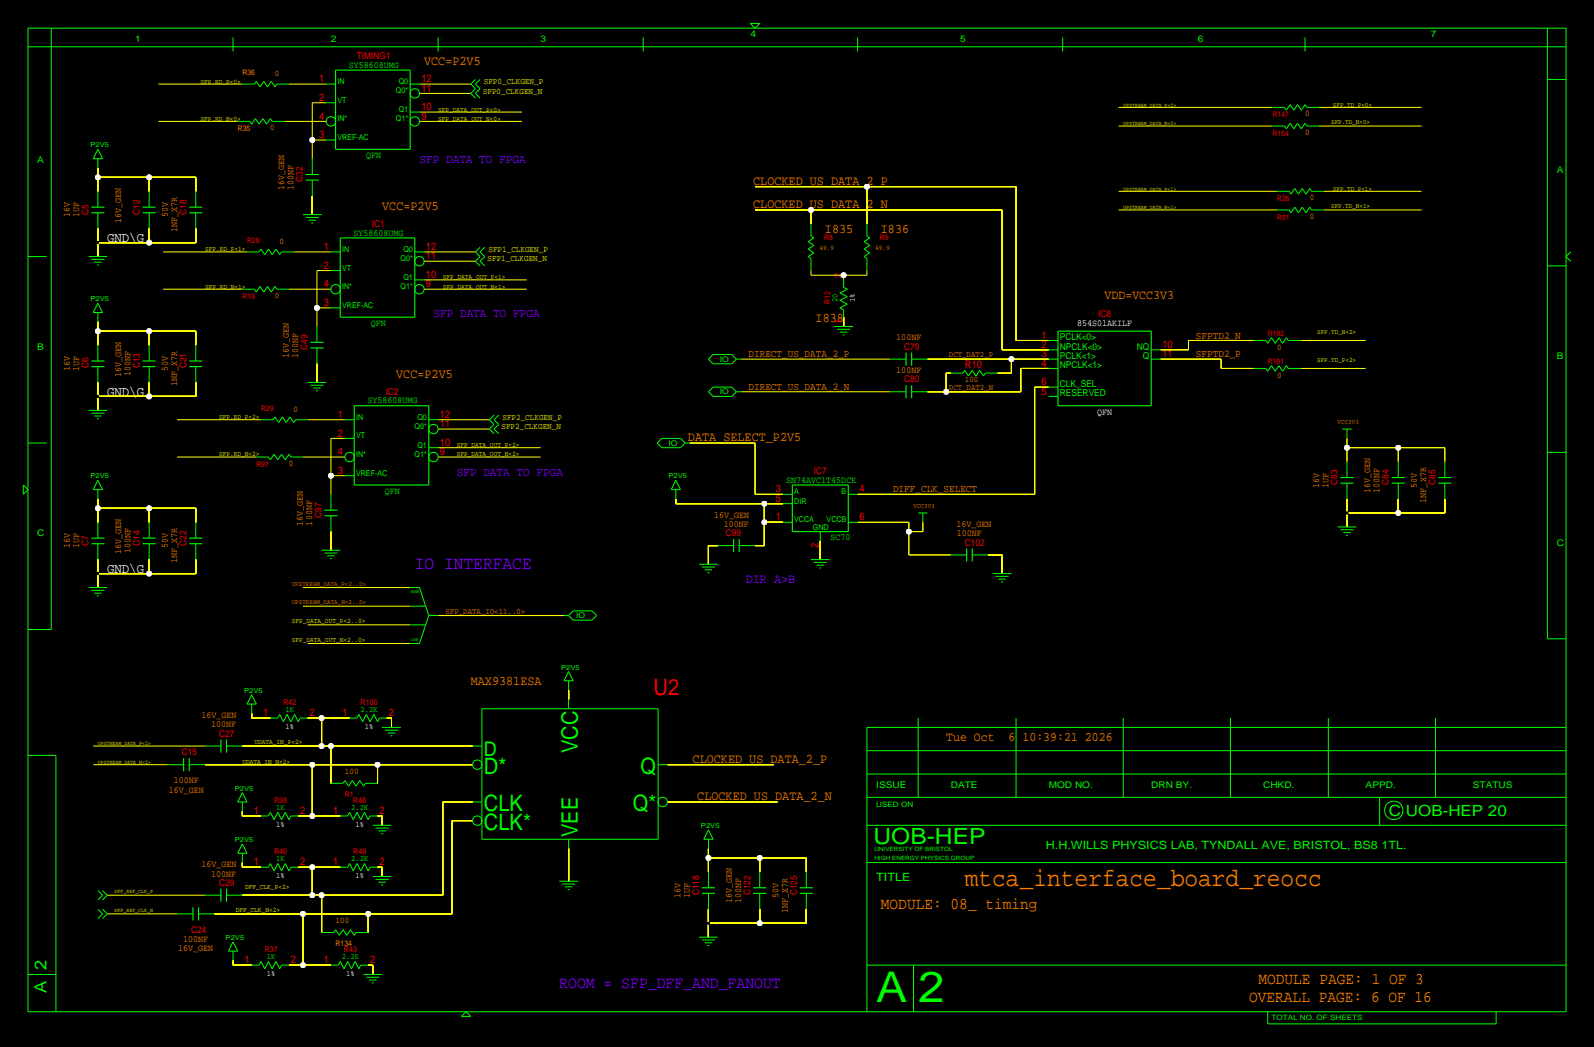
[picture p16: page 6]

ISSUE | DATE | MOD NO. | DRN BY. | CHKD. | APPD. | STATUS

USED ON | C UOB-HEP 20

H.H.WILLS PHYSICS LAB, TYNDALL AVE, BRISTOL, BS8 1TL.
mtca_interface_board_reocc

UNIVERSITY OF BRISTOL
HIGH ENERGY PHYSICS GROUP
TITLE
MODULE: 08_ timing

# ROOM = CLK_GEN_X12

# GND\G ¹⁰UF

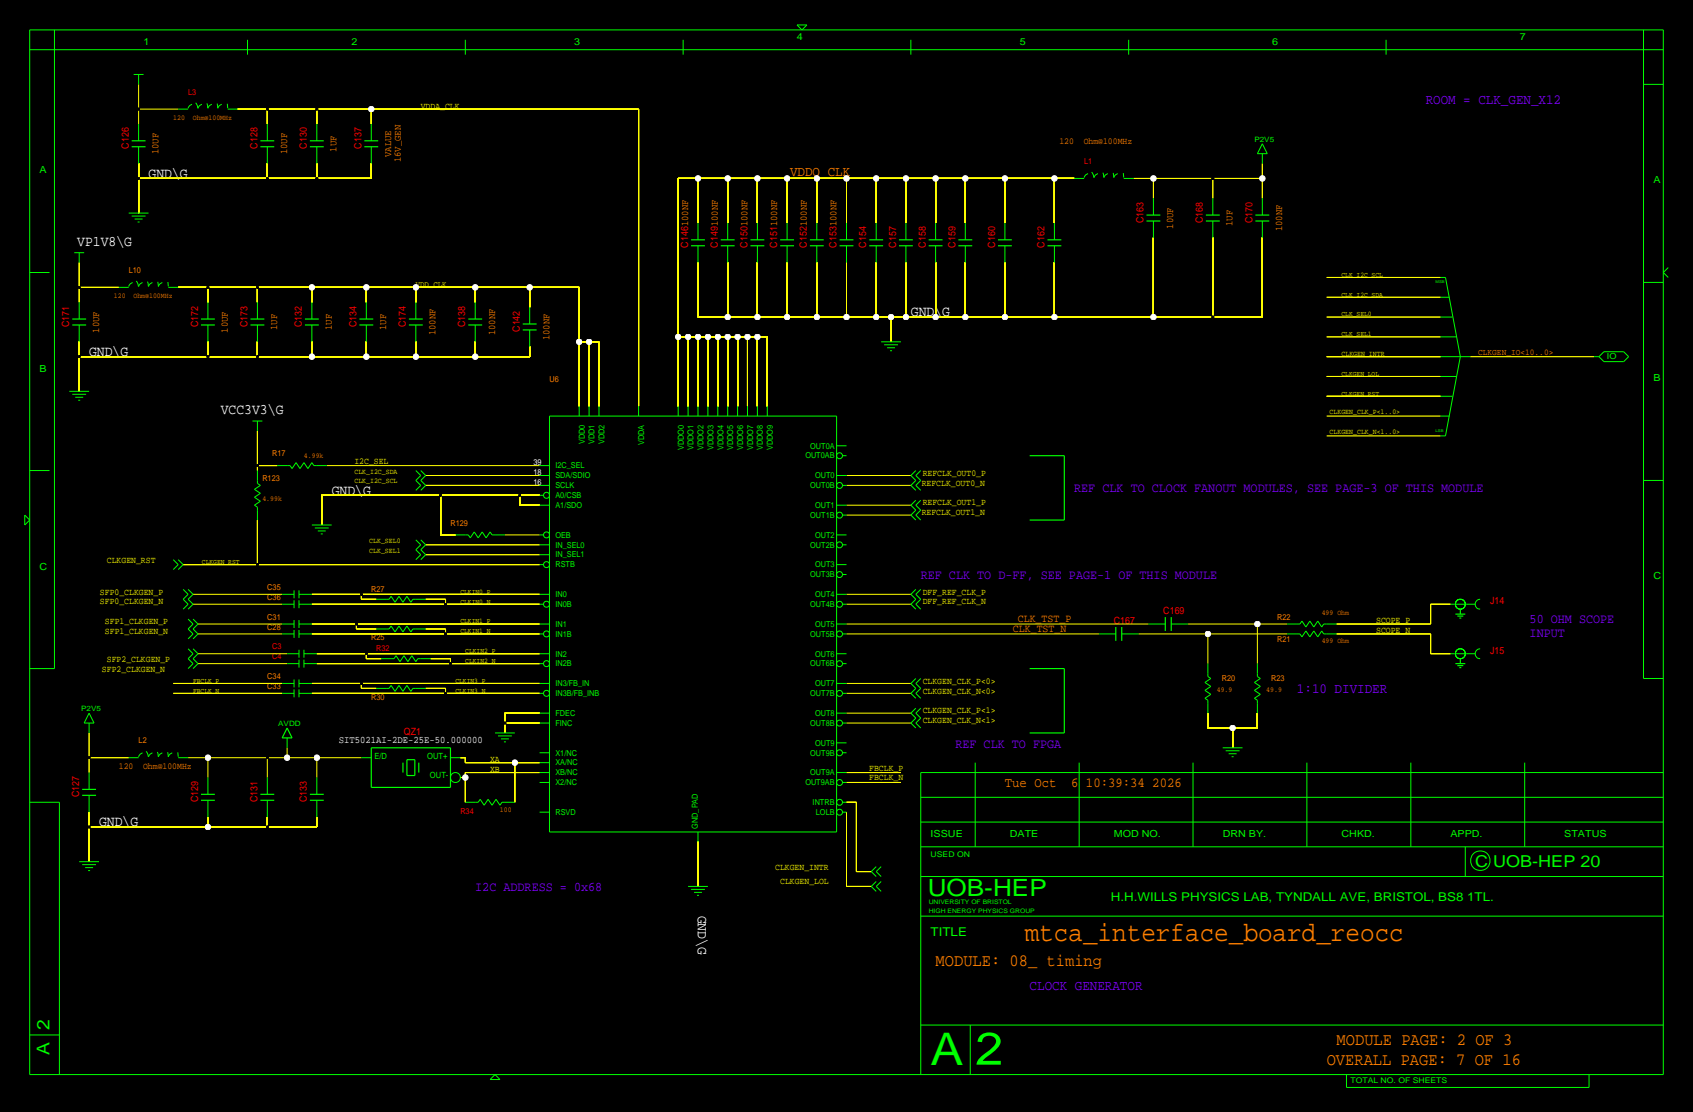
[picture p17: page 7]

REF CLK TO CLOCK FANOUT MODULES, SEE PAGE-3 OF THIS MODULE

REF CLK TO D-FF, SEE PAGE-1 OF THIS MODULE
DFF_REF_CLK_P
DFF_REF_CLK_N

ISSUE | DATE | MOD NO. | DRN BY. | CHKD. | APPD. | STATUS

USED ON | C UOB-HEP 20

H.H.WILLS PHYSICS LAB, TYNDALL AVE, BRISTOL, BS8 1TL.
mtca_interface_board_reocc

UNIVERSITY OF BRISTOL
HIGH ENERGY PHYSICS GROUP
TITLE
MODULE: 08_ timing

# ROOM = CLK_FO_0_5
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

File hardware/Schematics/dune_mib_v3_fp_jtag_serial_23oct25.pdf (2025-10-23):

## 3.3V POWER ON "AUXIO" CONNECTOR

## JTAG FOR FPGA

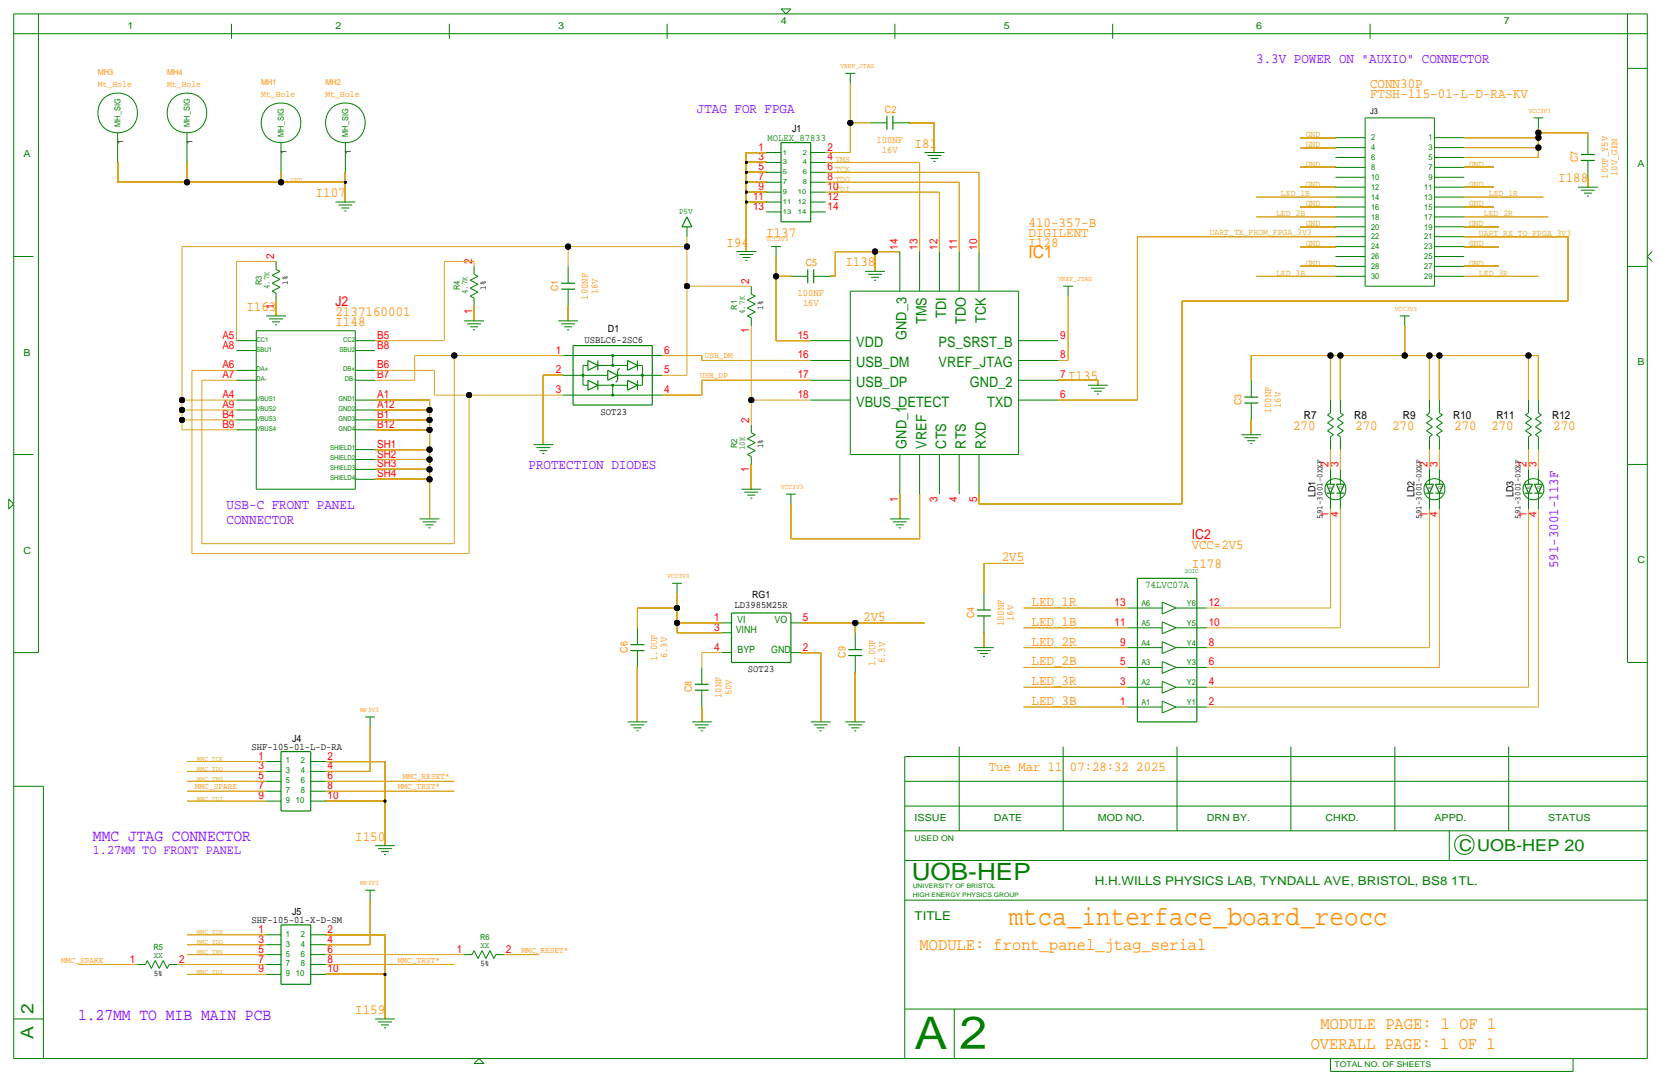
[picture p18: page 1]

3.3V POWER ON "AUXIO" CONNECTOR

3 3 | 4 4 TMS TMS
5 5 | 6 6 TCK TCK
7 7 | 8 8 TDO
9 9 | 10 10

A9 A9 | A12
B4 B4 | B1 B1
B9 B9 | B12

ISSUE | DATE | MOD NO. | DRN BY. | CHKD. | APPD. | STATUS

USED ON | C UOB-HEP 20

H.H.WILLS PHYSICS LAB, TYNDALL AVE, BRISTOL, BS8 1TL.
mtca_interface_board_reocc

UNIVERSITY OF BRISTOL
HIGH ENERGY PHYSICS GROUP
TITLE
MODULE: front_panel_jtag_serial

TOTAL NO. OF SHEETS

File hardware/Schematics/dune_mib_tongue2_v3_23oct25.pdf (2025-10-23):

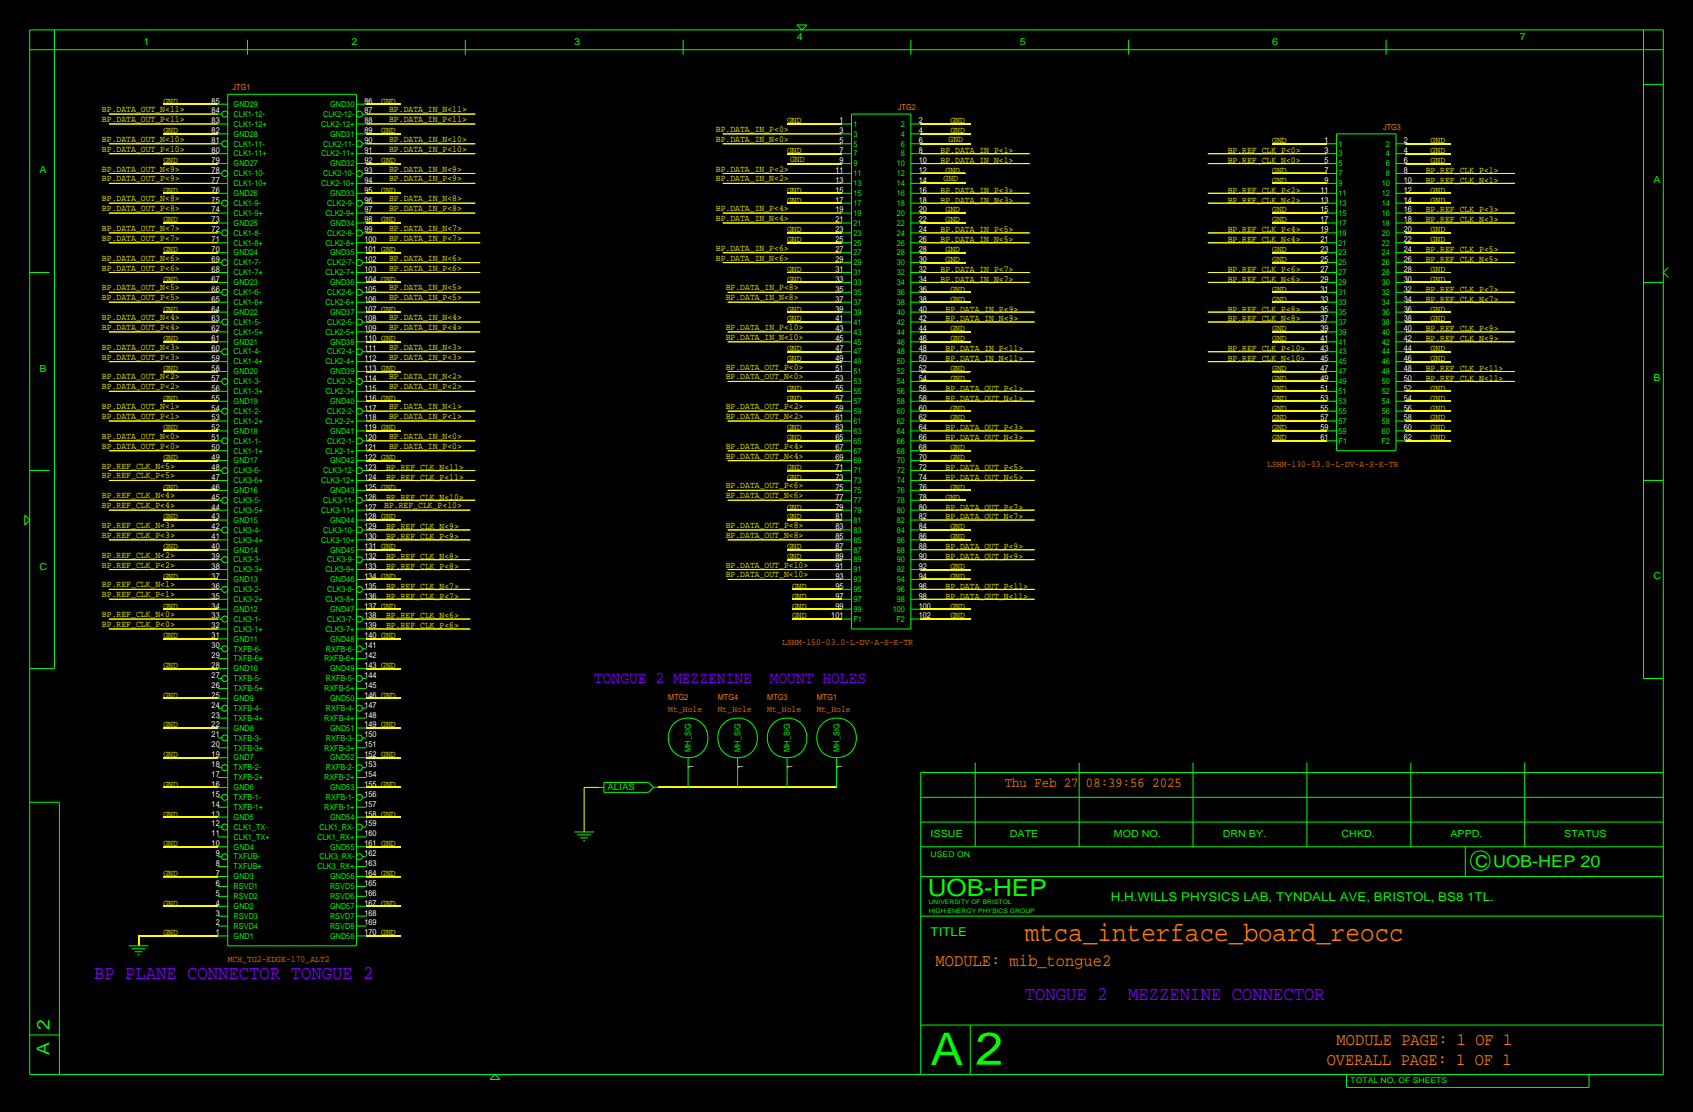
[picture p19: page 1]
Thu Feb 27; mtca_interface_board_reocc; BP.DATA_OUT_N<11>; BP.DATA_IN_N<7>; BP.DATA_IN_N<6>; BP.DATA_IN_P<4>; BP.DATA_IN_N<4>; BP.DATA_IN_P<5>; BP.DATA_IN_N<5>; BP.DATA_IN_P<6>; BP.DATA_IN_P<7>; BP.DATA_IN_P<8>; BP.DATA_IN_N<8>; BP.DATA_IN_P<9>; BP.DATA_OUT_P<4>; BP.DATA_OUT_N<6>; BP.DATA_OUT_P<8>; BP.DATA_OUT_P<3>; BP.DATA_IN_N<11>; BP.DATA_OUT_P<1> BP.DATA_OUT_N<1>; GND; BP.REF_CLK_N<10>; BP.DATA_IN_N<9>; BP.DATA_OUT_P<9>; BP.DATA_OUT_N<7>; BP.DATA_OUT_N<2>; BP.DATA_OUT_N<0>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

LSHM-130-03.0-L-DV-A-S-K-TR

LSHM-150-03.0-L-DV-A-S-K-TR

TONGUE 2 MEZZENINE MOUNT HOLES

ISSUE | DATE | MOD NO. | DRN BY. | CHKD. | APPD. | STATUS

USED ON | C UOB-HEP 20

GND
BP PLANE CONNECTOR TONGUE 2

H.H.WILLS PHYSICS LAB, TYNDALL AVE, BRISTOL, BS8 1TL.
mtca_interface_board_reocc

UNIVERSITY OF BRISTOL
HIGH ENERGY PHYSICS GROUP
TITLE
MODULE: mib_tongue2
TONGUE 2 MEZZENINE CONNECTOR

MODULE PAGE: 1 OF 1
OVERALL PAGE: 1 OF 1

TOTAL NO. OF SHEETS

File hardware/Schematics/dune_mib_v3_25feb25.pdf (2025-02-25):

Fri Jun 7; mtca_interface_board_reocc; UOB-HEP

ISSUE | DATE | MOD NO. | DRN BY. | CHKD. | APPD. | STATUS

USED ON | C UOB-HEP 20

N.B. THIS IS A DRAWING, NO CONNECTIVITY

H.H.WILLS PHYSICS LAB, TYNDALL AVE, BRISTOL, BS8 1TL.
mtca_interface_board_reocc

UNIVERSITY OF BRISTOL
HIGH ENERGY PHYSICS GROUP
TITLE
MODULE: top_mib_v3

MODULE PAGE: 1 OF 2
OVERALL PAGE: 1 OF 16

TOTAL NO. OF SHEETS

## ROOM=POWER

# BACKPLANE_INTERFACE 07. BACKPLANE INTERFACE

MIB_HIERARCHY (TOP LEVEL); Wed Jul 3; mtca_interface_board_reocc; SFP_RATE_SELECT<2..0>:SFP_TX_DISABLE<2..0>:SFP_TX_FAULT<2..0>:SFP_LOS<2..0>:SFP_RD_P<2..0>:SFP_RD_N<2..0>:SFP_TD_P<2..0>:SFP_TD_N<2..0>:SFP_SDA<2..0>:SFP_SCL<2..0>; CLK_SCL:CLK_SDA:CLK_SEL0:CLK_SEL1:CLK_INTR:CLK_LOL:CLK_RST:CLK_P<1..0>:CLK_N<1..0>; UPSTREAM_DATA_P<2..0>:UPSTREAM_DATA_N_<2..0>:SFP_DATA_OUT_P<2..0>:SFP_DATA_OUT_N<2..0>; DATA_SELECT_P2V5; DIRECT_US_DATA_2_P; DIRECT_US_DATA_2_N; 03. SFP; 08. TIMING; FPGA_PG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

UNCONNECTED<91:0>:PWR_ON:AMC_N_ENABLE:TCK:TMS:TDO:TDI:GBE_TX_N:GBE_TX_P:GBE_RX_N:GBE_RX_P:IMPB_SCL:IMPB_SDA:DATA_OUT_P<11..0>:DATA_OUT_N<11..0>:DATA_IN_P<11..0>:DATA_IN_N<11..0>:REF_CLK_P<11..0>:REF_CLK_N<11..0>:AMC_GA<2..0>:AMC_N_PS<1..0>

05 TRENZ TE0712 FPGA MODULE

01. MODULE MANAGEMENT CTRL

TIMING1
1. D-FF FOR UPSTREAM
2. SFP DATA 1:2 FANOUTS
3. Clock Generator
4. Clock Fanout

ISSUE | DATE | MOD NO. | DRN BY. | CHKD. | APPD. | STATUS

USED ON | C UOB-HEP 20

H.H.WILLS PHYSICS LAB, TYNDALL AVE, BRISTOL, BS8 1TL.
mtca_interface_board_reocc

UNIVERSITY OF BRISTOL
HIGH ENERGY PHYSICS GROUP
TITLE
MODULE: top_mib_v3

# VP3V3 IV MONITOR

# 12V @ 6.6A IN


12V TO 3V3 @ 14A DC-DC CONVERTER
MIN ESR OF 3 MILLI-OHMS ON OUTPUT OF PTH08T210WAD

MEASURE CURRENT THROUGH
SENSE RESISTOR BEFORE 1V8 REG
MEASURE 1V8 VOLTAGE AFTER REGULATOR

EXT POWER IN KK CONNECTOR

ISSUE | DATE | MOD NO. | DRN BY. | CHKD. | APPD. | STATUS

USED ON | C UOB-HEP 20

H.H.WILLS PHYSICS LAB, TYNDALL AVE, BRISTOL, BS8 1TL.
mtca_interface_board_reocc

UNIVERSITY OF BRISTOL
HIGH ENERGY PHYSICS GROUP
TITLE
MODULE: 02_ power

# WANT <0.3V DROP AT 2A

# P2V5 IV MONITOR


12V TO 2V5 @ 14A DC-DC CONVERTER

MEASURE CURRENT THROUGH
SENSE RESISTOR BEFORE 1V8 REG
MEASURE 1V8 VOLTAGE

ISSUE | DATE | MOD NO. | DRN BY. | CHKD. | APPD. | STATUS

USED ON | C UOB-HEP 20

H.H.WILLS PHYSICS LAB, TYNDALL AVE, BRISTOL, BS8 1TL.
mtca_interface_board_reocc

UNIVERSITY OF BRISTOL
HIGH ENERGY PHYSICS GROUP
TITLE
MODULE: 02_ power


MEASURE CURRENT THROUGH
SENSE RESISTOR BEFORE 1V8 REG

ISSUE | DATE | MOD NO. | DRN BY. | CHKD. | APPD. | STATUS

USED ON | C UOB-HEP 20

H.H.WILLS PHYSICS LAB, TYNDALL AVE, BRISTOL, BS8 1TL.
mtca_interface_board_reocc

UNIVERSITY OF BRISTOL
HIGH ENERGY PHYSICS GROUP
TITLE
MODULE: 02_ power

# SFP DATA TO FPGA

IC1

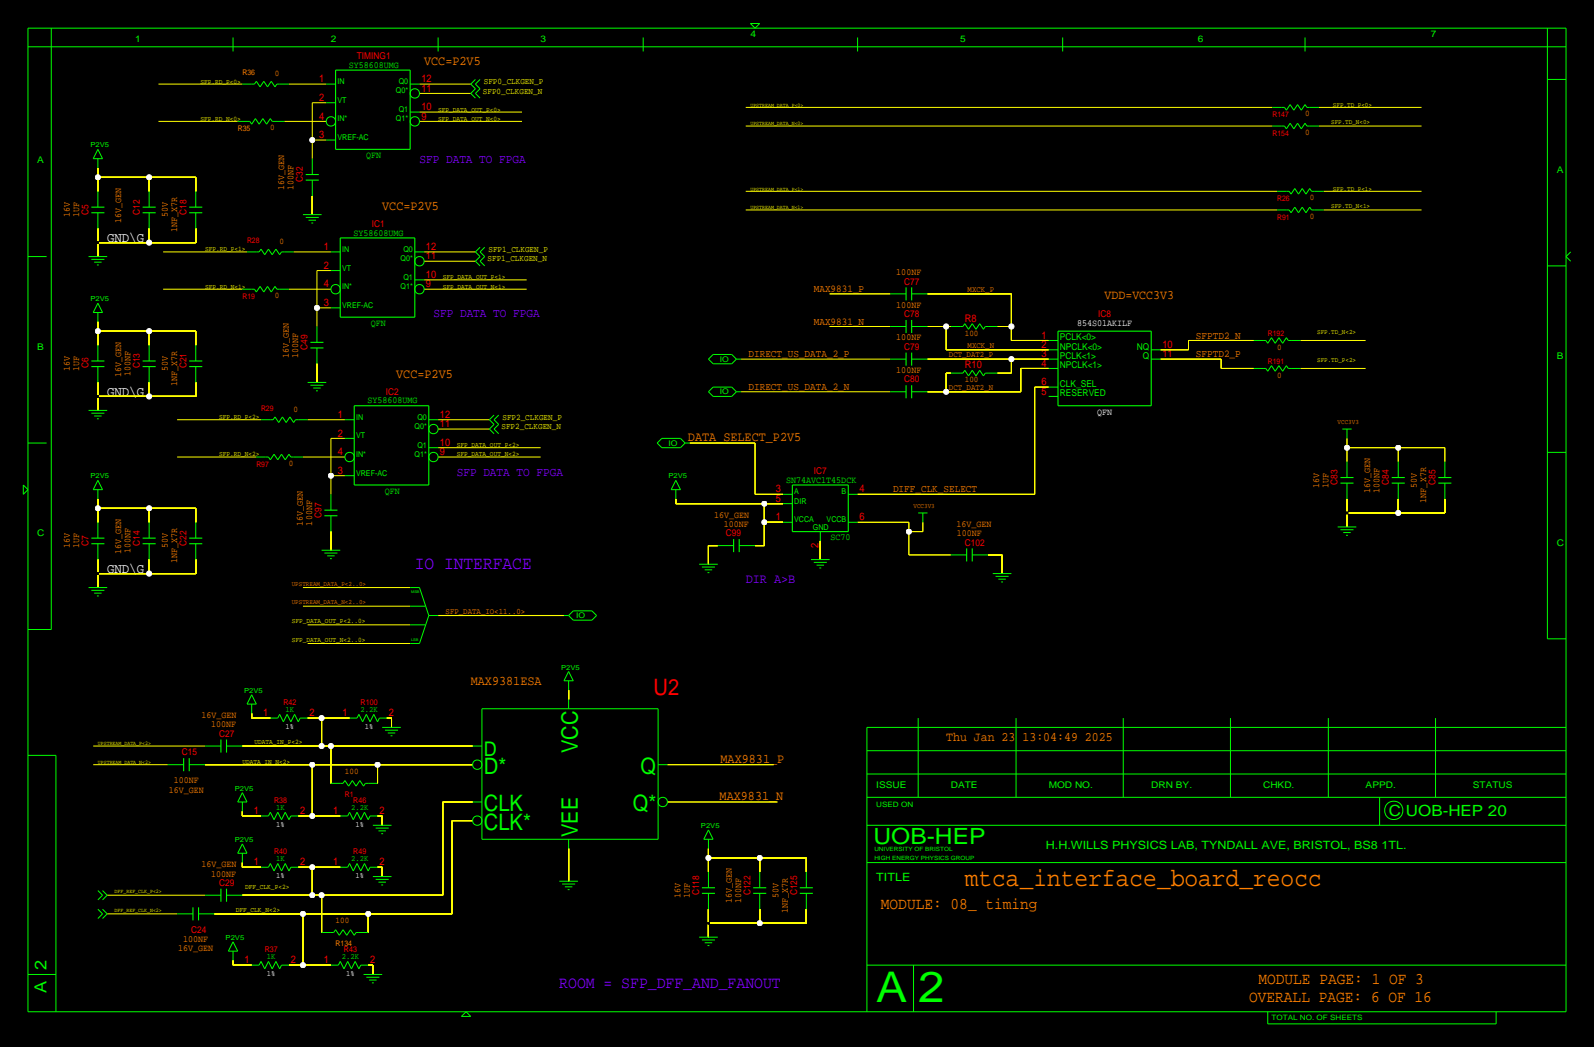
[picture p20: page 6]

ISSUE | DATE | MOD NO. | DRN BY. | CHKD. | APPD. | STATUS

USED ON | C UOB-HEP 20

H.H.WILLS PHYSICS LAB, TYNDALL AVE, BRISTOL, BS8 1TL.
mtca_interface_board_reocc

UNIVERSITY OF BRISTOL
HIGH ENERGY PHYSICS GROUP
TITLE
MODULE: 08_ timing

# ROOM = CLK_GEN_X12

# VDDO_CLK

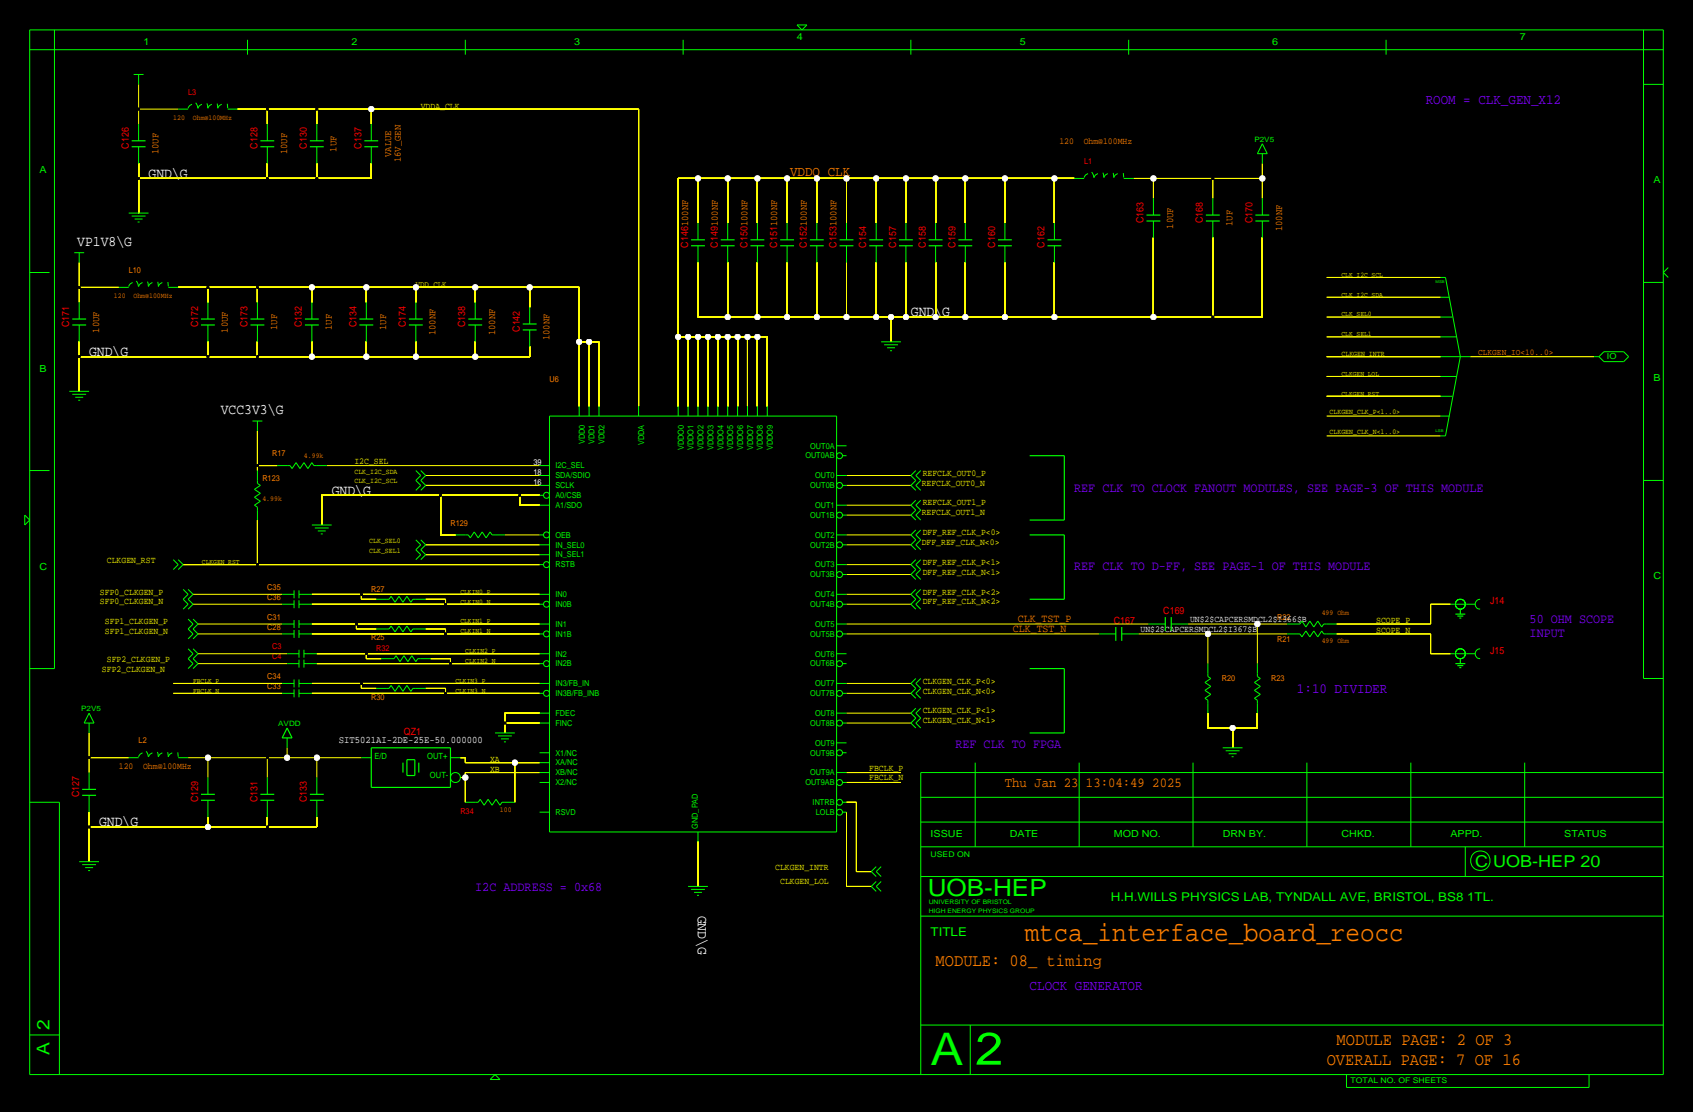
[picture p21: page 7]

REF CLK TO CLOCK FANOUT MODULES, SEE PAGE-3 OF THIS MODULE

REF CLK TO D-FF, SEE PAGE-1 OF THIS MODULE

ISSUE | DATE | MOD NO. | DRN BY. | CHKD. | APPD. | STATUS

USED ON | C UOB-HEP 20

H.H.WILLS PHYSICS LAB, TYNDALL AVE, BRISTOL, BS8 1TL.
mtca_interface_board_reocc

UNIVERSITY OF BRISTOL
HIGH ENERGY PHYSICS GROUP
TITLE
MODULE: 08_ timing
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

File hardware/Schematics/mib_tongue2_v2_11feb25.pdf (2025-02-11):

BP PLANE CONNECTOR TONGUE 2; Thu Feb 2; mtca_interface_board_reocc; GND; BP.DATA_IN_N<8>; BP.DATA_IN_P<11>; BP.DATA_IN_P<10>; BP.REF_CLK_N<2>; BP.REF_CLK_P<2>; BP.DATA_OUT_N<11>; BP.DATA_OUT_P<11>; BP.DATA_OUT_P<10> BP.DATA_OUT_N<10>; BP.DATA_OUT_P<9> BP.DATA_OUT_N<9>; BP.DATA_OUT_N<8>; BP.DATA_OUT_P<8>; BP.DATA_OUT_N<7>; BP.DATA_OUT_P<7>; BP.DATA_OUT_N<6>; BP.DATA_OUT_P<6>; BP.DATA_OUT_N<5>; BP.DATA_OUT_P<5>; BP.DATA_OUT_N<4>; BP.DATA_OUT_P<4>; BP.DATA_OUT_N<3>; BP.DATA_OUT_P<3>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

LSHM-130-03.0-L-DV-A-S-K-TR

LSHM-150-03.0-L-DV-A-S-K-TR

TONGUE 2 MEZZENINE MOUNT HOLES

ISSUE | DATE | MOD NO. | DRN BY. | CHKD. | APPD. | STATUS

USED ON | C UOB-HEP 20

H.H.WILLS PHYSICS LAB, TYNDALL AVE, BRISTOL, BS8 1TL.
mtca_interface_board_reocc

UNIVERSITY OF BRISTOL
HIGH ENERGY PHYSICS GROUP
TITLE
MODULE: mib_tongue2
TONGUE 2 MEZZENINE CONNECTOR

BP PLANE CONNECTOR TONGUE 2

MODULE PAGE: 1 OF 1
OVERALL PAGE: 1 OF 1

TOTAL NO. OF SHEETS

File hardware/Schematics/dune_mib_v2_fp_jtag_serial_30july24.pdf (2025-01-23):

## 3.3V POWER ON UART CABLE 4.7K 1%

I137


UNIVERSITY OF BRISTOL
HIGH ENERGY PHYSICS GROUP
TITLE
MODULE: front_panel_jtag_serial

H.H.WILLS PHYSICS LAB, TYNDALL AVE, BRISTOL, BS8 1TL.

1.27MM TO MIB MAIN PCB

TOTAL NO. OF SHEETS

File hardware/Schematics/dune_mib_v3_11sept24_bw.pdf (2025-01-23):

1 | 3 | 4
5 6

Fri Jun 7 16:04:20 2024; mtca_interface_board_reocc; USED ON; ISSUE; APPD. DATE; MOD NO.; DRN BY.; CHKD.; STATUS; C UOB-HEP 20; UOB-HEP

N.B. THIS IS A DRAWING, NO CONNECTIVITY

UNIVERSITY OF BRISTOL
HIGH ENERGY PHYSICS GROUP
TITLE
MODULE: top_mib_v3

H.H.WILLS PHYSICS LAB, TYNDALL AVE, BRISTOL, BS8 1TL.

MODULE PAGE: 1 OF 2
OVERALL PAGE: 1 OF 16

TOTAL NO. OF SHEETS

## ROOM=POWER

02. POWER | 07. BACKPLANE INTERFACE

(TOP LEVEL); MIB_HIERARCHY; 3. Clock Generator; 4. Clock Fanout; Wed Jul 3 07:32:48 2024; mtca_interface_board_reocc; SFP_RATE_SELECT<2..0>:SFP_TX_DISABLE<2..0>:SFP_TX_FAULT<2..0>:SFP_LOS<2..0>:SFP_RD_P<2..0>:SFP_RD_N<2..0>:SFP_TD_P<2..0>:SFP_TD_N<2..0>:SFP_SDA<2..0>:SFP_SCL<2..0>; CLK_SCL:CLK_SDA:CLK_SEL0:CLK_SEL1:CLK_INTR:CLK_LOL:CLK_RST:CLK_P<1..0>:CLK_N<1..0>; UPSTREAM_DATA_P<2..0>:UPSTREAM_DATA_N_<2..0>:SFP_DATA_OUT_P<2..0>:SFP_DATA_OUT_N<2..0>; DATA_SELECT_P2V5; DIRECT_US_DATA_2_P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

UNCONNECTED<91:0>:PWR_ON:AMC_N_ENABLE:TCK:TMS:TDO:TDI:GBE_TX_N:GBE_TX_P:GBE_RX_N:GBE_RX_P:IMPB_SCL:IMPB_SDA:DATA_OUT_P<11..0>:DATA_OUT_N<11..0>:DATA_IN_P<11..0>:DATA_IN_N<11..0>:REF_CLK_P<11..0>:REF_CLK_N<11..0>:AMC_GA<2..0>:AMC_N_PS<1..0>

05 TRENZ TE0712 FPGA MODULE

01. MODULE MANAGEMENT CTRL

TIMING1
1. D-FF FOR UPSTREAM
2. SFP DATA 1:2 FANOUTS

UNIVERSITY OF BRISTOL
HIGH ENERGY PHYSICS GROUP
TITLE
MODULE: top_mib_v3

H.H.WILLS PHYSICS LAB, TYNDALL AVE, BRISTOL, BS8 1TL.

MODULE PAGE: 2 OF 2
OVERALL PAGE: 2 OF 16

# MIN ESR OF 3 MILLI-OHMS ON OUTPUT OF PTH08T210WAD

# 12V TO 3V3 @ 14A DC-DC CONVERTER


MEASURE CURRENT THROUGH
SENSE RESISTOR BEFORE 1V8 REG
MEASURE 1V8 VOLTAGE AFTER REGULATOR

EXT POWER IN KK CONNECTOR

UNIVERSITY OF BRISTOL
HIGH ENERGY PHYSICS GROUP
TITLE

H.H.WILLS PHYSICS LAB, TYNDALL AVE, BRISTOL, BS8 1TL.

# 12V TO 2V5 @ 14A DC-DC CONVERTER

# WANT <0.3V DROP AT 2A


MEASURE CURRENT THROUGH
SENSE RESISTOR BEFORE 1V8 REG
MEASURE 1V8 VOLTAGE

UNIVERSITY OF BRISTOL
HIGH ENERGY PHYSICS GROUP
TITLE
MODULE: 02_ power

H.H.WILLS PHYSICS LAB, TYNDALL AVE, BRISTOL, BS8 1TL.

A
A


MEASURE CURRENT THROUGH
SENSE RESISTOR BEFORE 1V8 REG

UNIVERSITY OF BRISTOL
HIGH ENERGY PHYSICS GROUP
TITLE
MODULE: 02_ power

H.H.WILLS PHYSICS LAB, TYNDALL AVE, BRISTOL, BS8 1TL.

# SFP DATA TO FPGA

## SFP1_CLKGEN_P


UNIVERSITY OF BRISTOL
HIGH ENERGY PHYSICS GROUP
TITLE
MODULE: 08_ timing

H.H.WILLS PHYSICS LAB, TYNDALL AVE, BRISTOL, BS8 1TL.
mtca_interface_board_reocc

# ROOM = CLK_GEN_X12

# VDDO_CLK


REF CLK TO CLOCK FANOUT MODULES, SEE PAGE-3 OF THIS MODULE

REF CLK TO D-FF, SEE PAGE-1 OF THIS MODULE

UNIVERSITY OF BRISTOL
HIGH ENERGY PHYSICS GROUP
TITLE
MODULE: 08_ timing

H.H.WILLS PHYSICS LAB, TYNDALL AVE, BRISTOL, BS8 1TL.

# ROOM = CLK_FO_0_5

100NF


USE 8 WAY LVPECL FANOUT
NOT AVAILABLE DUE TO
SUPPLY CHAIN ISSUES

... BECAUSE 6 WAY LVDS BUFFER

UNIVERSITY OF BRISTOL
HIGH ENERGY PHYSICS GROUP
TITLE
MODULE: 08_ timing

H.H.WILLS PHYSICS LAB, TYNDALL AVE, BRISTOL, BS8 1TL.

## SFP.RATE_SELECT<0>

A

Mon Mar 6 16:31:19 2023; mtca_interface_board_reocc; ROOM=SFP1 04. SFP_MODULE; ROOM=SFP3 04. SFP_MODULE; SFP.RATE_SELECT<2> SFP.TX_DISABLE<2> SFP.TX_FAULT<2> SFP.LOS<2>; SFP<29..0>; SFP.TD_P<2>; SFP.RD_N<2>; SFP.RD_P<2>; SFP.TD_N<0>; SFP.TD_P<0>; SFP.RD_P<0> SFP.RD_N<0>; SFP.SCL<0>; SFP.SDA<0>; SFP.TX_DISABLE<0>; SFP.LOS<0>; SFP.TX_FAULT<0>; SFP.SCL<2>; SFP.SDA<2>; SFP.TD_N<2>; SFP.SCL<1>; SFP.SDA<1>; SFP.TD_N<1>; SFP.TD_P<1>; SFP.RD_N<1>; SFP.RD_P<1>; SFP.LOS<1>; SFP.TX_FAULT<1>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

312.5 Mb/S Timing Signals
on 1000Base BX Link

ROOM=SFP2
04. SFP_MODULE

UNIVERSITY OF BRISTOL
HIGH ENERGY PHYSICS GROUP
TITLE
MODULE: 03_ sfp

H.H.WILLS PHYSICS LAB, TYNDALL AVE, BRISTOL, BS8 1TL.

MODULE PAGE: 1 OF 1
OVERALL PAGE: 9 OF 16

22UF
6.3V


UNIVERSITY OF BRISTOL
HIGH ENERGY PHYSICS GROUP
TITLE
MODULE: 04_ sfp_module

H.H.WILLS PHYSICS LAB, TYNDALL AVE, BRISTOL, BS8 1TL.

JTAG CONNECTOR | EEPROM
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

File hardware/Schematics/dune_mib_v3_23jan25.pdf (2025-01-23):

Fri Jun 7; mtca_interface_board_reocc; UOB-HEP

ISSUE | DATE | MOD NO. | DRN BY. | CHKD. | APPD. | STATUS

USED ON | C UOB-HEP 20

N.B. THIS IS A DRAWING, NO CONNECTIVITY

H.H.WILLS PHYSICS LAB, TYNDALL AVE, BRISTOL, BS8 1TL.
mtca_interface_board_reocc

UNIVERSITY OF BRISTOL
HIGH ENERGY PHYSICS GROUP
TITLE
MODULE: top_mib_v3

MODULE PAGE: 1 OF 2
OVERALL PAGE: 1 OF 16

TOTAL NO. OF SHEETS

## ROOM=POWER

# BACKPLANE_INTERFACE 07. BACKPLANE INTERFACE

MIB_HIERARCHY (TOP LEVEL); Wed Jul 3; mtca_interface_board_reocc; SFP_RATE_SELECT<2..0>:SFP_TX_DISABLE<2..0>:SFP_TX_FAULT<2..0>:SFP_LOS<2..0>:SFP_RD_P<2..0>:SFP_RD_N<2..0>:SFP_TD_P<2..0>:SFP_TD_N<2..0>:SFP_SDA<2..0>:SFP_SCL<2..0>; CLK_SCL:CLK_SDA:CLK_SEL0:CLK_SEL1:CLK_INTR:CLK_LOL:CLK_RST:CLK_P<1..0>:CLK_N<1..0>; UPSTREAM_DATA_P<2..0>:UPSTREAM_DATA_N_<2..0>:SFP_DATA_OUT_P<2..0>:SFP_DATA_OUT_N<2..0>; DATA_SELECT_P2V5; DIRECT_US_DATA_2_P; DIRECT_US_DATA_2_N; 03. SFP; 08. TIMING; FPGA_PG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

UNCONNECTED<91:0>:PWR_ON:AMC_N_ENABLE:TCK:TMS:TDO:TDI:GBE_TX_N:GBE_TX_P:GBE_RX_N:GBE_RX_P:IMPB_SCL:IMPB_SDA:DATA_OUT_P<11..0>:DATA_OUT_N<11..0>:DATA_IN_P<11..0>:DATA_IN_N<11..0>:REF_CLK_P<11..0>:REF_CLK_N<11..0>:AMC_GA<2..0>:AMC_N_PS<1..0>

05 TRENZ TE0712 FPGA MODULE

01. MODULE MANAGEMENT CTRL

TIMING1
1. D-FF FOR UPSTREAM
2. SFP DATA 1:2 FANOUTS
3. Clock Generator
4. Clock Fanout

ISSUE | DATE | MOD NO. | DRN BY. | CHKD. | APPD. | STATUS

USED ON | C UOB-HEP 20

H.H.WILLS PHYSICS LAB, TYNDALL AVE, BRISTOL, BS8 1TL.
mtca_interface_board_reocc

UNIVERSITY OF BRISTOL
HIGH ENERGY PHYSICS GROUP
TITLE
MODULE: top_mib_v3

# VP3V3 IV MONITOR

# 12V @ 6.6A IN


12V TO 3V3 @ 14A DC-DC CONVERTER
MIN ESR OF 3 MILLI-OHMS ON OUTPUT OF PTH08T210WAD

MEASURE CURRENT THROUGH
SENSE RESISTOR BEFORE 1V8 REG
MEASURE 1V8 VOLTAGE AFTER REGULATOR

EXT POWER IN KK CONNECTOR

ISSUE | DATE | MOD NO. | DRN BY. | CHKD. | APPD. | STATUS

USED ON | C UOB-HEP 20

H.H.WILLS PHYSICS LAB, TYNDALL AVE, BRISTOL, BS8 1TL.
mtca_interface_board_reocc

UNIVERSITY OF BRISTOL
HIGH ENERGY PHYSICS GROUP
TITLE
MODULE: 02_ power

# 12V TO 2V5 @ 14A DC-DC CONVERTER

# P2V5 IV MONITOR


12V TO 2V5 @ 14A DC-DC CONVERTER

MEASURE CURRENT THROUGH
SENSE RESISTOR BEFORE 1V8 REG
MEASURE 1V8 VOLTAGE

ISSUE | DATE | MOD NO. | DRN BY. | CHKD. | APPD. | STATUS

USED ON | C UOB-HEP 20

H.H.WILLS PHYSICS LAB, TYNDALL AVE, BRISTOL, BS8 1TL.
mtca_interface_board_reocc

UNIVERSITY OF BRISTOL
HIGH ENERGY PHYSICS GROUP
TITLE
MODULE: 02_ power


MEASURE CURRENT THROUGH
SENSE RESISTOR BEFORE 1V8 REG

ISSUE | DATE | MOD NO. | DRN BY. | CHKD. | APPD. | STATUS

USED ON | C UOB-HEP 20

H.H.WILLS PHYSICS LAB, TYNDALL AVE, BRISTOL, BS8 1TL.
mtca_interface_board_reocc

UNIVERSITY OF BRISTOL
HIGH ENERGY PHYSICS GROUP
TITLE
MODULE: 02_ power

# SFP DATA TO FPGA

IC1


ISSUE | DATE | MOD NO. | DRN BY. | CHKD. | APPD. | STATUS

USED ON | C UOB-HEP 20

H.H.WILLS PHYSICS LAB, TYNDALL AVE, BRISTOL, BS8 1TL.
mtca_interface_board_reocc

UNIVERSITY OF BRISTOL
HIGH ENERGY PHYSICS GROUP
TITLE
MODULE: 08_ timing

# ROOM = CLK_GEN_X12

# VDDO_CLK


REF CLK TO CLOCK FANOUT MODULES, SEE PAGE-3 OF THIS MODULE

REF CLK TO D-FF, SEE PAGE-1 OF THIS MODULE

ISSUE | DATE | MOD NO. | DRN BY. | CHKD. | APPD. | STATUS

USED ON | C UOB-HEP 20

H.H.WILLS PHYSICS LAB, TYNDALL AVE, BRISTOL, BS8 1TL.
mtca_interface_board_reocc

UNIVERSITY OF BRISTOL
HIGH ENERGY PHYSICS GROUP
TITLE
MODULE: 08_ timing
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



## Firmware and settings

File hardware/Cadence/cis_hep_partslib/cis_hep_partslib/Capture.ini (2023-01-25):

[Part Management]
Configuration File=\\MAC\HOME\DESKTOP\SPB_DATA\CIS_HEP_PARTSLIB\CONFIGURATION_FILES\HEP_PCB.DBC
Connect=9A8D8C85869EA8928C949CA7B8DAEDEEC6BCD2A486ACDCDCCACADBDFA9A0BFB0B5CBC6ABBEE3D9C8A7B0DFE5E6EAE6D3B6AA99A8AAACDCDCC4A693A3B9AE949CB6B6B8DAEDEEE6DCD2C5A7ACDCDCCACADBDFC8AB949CB6B6989AADAEB9B29C9277798D8495CEE0DCB898A08D747295D3EED8BAC9DACFDBD5A57F90C4CAB3AD92747296C4DDD9DBEBF0B87F95C2DEE8EDC9B6D5D9DFB774728EC2E4DCBCB6D5D9DFB7747290C4B9BCDECDDCB8747290C4CDA192909A9675738898A5CFECE7E6E8EDB874728CC0EBEEE7D6D4C0C3DAD0A97F919B99979A9474728EC2D7CCB0C4F3B87F84B2D7B7BEE9B874728C958EB9E4EBBA747292AEA28844
[Footprint Viewer Type]
Type=Allegro
[Allegro Footprints]
Dir0=\\Mac\Home\Desktop\SPB_Data\CIS_HEP_Partslib\Allegro_Library\symbols
Dir1=C:\Cadence\SPB_17.4\share\pcb\pcb_lib\symbols
[Part Library Directories]
Dir0=\\Mac\Home\Desktop\SPB_Data\CIS_HEP_Partslib\Schematic_Symbols
Dir1=C:\Cadence\SPB_17.2\tools\capture\library
Dir2=\\Mac\Home\Desktop\SPB_Data\CIS_HEP_Partslib\Schematic_Symbols
[Application]
Version=17.4-2019
[Preferences]
CEIP_EVENT_TRACKING=FALSE
capPDFOutputFolder=
capPDFDriver=OrCADPS_17.4
capPDFCommandIndex=2
capPDFConverter=Ghostscript 64 bit / equivalent
capPDFExcludeProp=Line Style!!Line Width!!Color!!Location X-Coordinate!!Location Y-Coordinate
capPDFCommand2={c:\program files\gs\gs9.22\bin\gswin64c.exe} -sDEVICE=pdfwrite -sOutputFile=$::capPdfUtil::mPdfFilePath -dBATCH -dNOPAUSE $::capPdfUtil::mPSFilePath
capPDFPrintingMode=0
capPDFOrientation=1
capPDFCreatePropertiesFile=0
capPDFCreateNetAndBookmark=1
capPDFPaperSize=0
DoNotShowCMFlowDialog=FALSE
PromptOnLocalNavigate=True
HIGHLIGHT_USER_EDIT_REFERENCES_ON_PRINT=FALSE
AssignRefDesOnOccTreeCorrection=
EnableDynBundle=False
BackAnnotatePinNumbersOnly......=False
AutoRefTracker....=True
CanvasTheme=
CaptureTclAutoLoadScope=
AnnInstModeExternalDesign=False
CheckConnection..=True
Enable3DViewer=True
ShowFEMigrationAsDefault=FALSE
UltraLibrarian=True
SilenceBrowser...=True
DisplayCommands..=False
CheckReadOnlyOnViewActivate.....=True
IncrementalSave..=False
DisplayValueOnlyIfValueExists=
ObjectGridDistribution=DistributionWithAutomaticExtent
capPDFCommand3=
capPDFCommand1=
capPDFCommand0=
MergerConfigLibsInCIS=
EnableLegacyITC.....=False
DrawPinArrows....=True
IREFGlobalVisibility...=True
DockingPlacePart....=True
SessionLogFont...=[-14, 6, 0, 0, 0, 0, 0, 0, 0, 0, 0, 0, 0, Arial]
FlushCommand.....=True
ResetDisplayProp....=False
DefaultLibaryPath=
AutoAdjustColumnWidth=
DisplayWaivedDRC=False
Journaling.......=False
WiresOnTop=
CAP_DRC_FLOW_ENABLED=
TCLEnablePageCustomization=
PlacePartRefreshPart=False
PreserveReference....=False
UseCadenceDefaultLibraryInCIS=FALSE
CisProgressBarDisplay=
ArrowEntrepreneur=True
SaveImageAsBMP...=False
EnableLegacyDrag.....=True
UndoOnSave.......=True
CISShowDNIPartPinDisplayProperty=
HIGHLIGHT_USER_EDIT_REFERENCES_ON_PAGE=TRUE
MarkersOnTop=
EnableStartPage=True
Autosave.........=False
UseCadenceShareWareUtilties=
CaptureNewPartEditor=
OrCAD_Cap_Sigxp_tier=
ExtensibleFind=True
NetNameMode......=2
ViewerShowPinInfo=True
FillText.........=False
OrCAD_RegisterSKILLOutput=
SuppressMsgBoxInTcl=False
RotateInstPropInContext...=False
AutosaveMinutes..=15
EnableITC........=True
SetXMLReplayDataAfterInit=
ShowOnlyPageSizeSelection=False
EnableOverlappedPrinting.....=False
LegacySaveAs.....=True
SearchToolBar...=True
JunctionDotSize....=Small
AutoReference....=False
ViewerDisplayUnits=0
PathLookupTimeout....=10
DragPreference....=True
StrokeFont.......=False
LastFilter=< Current properties >
AnnotateAdditionalPropertyString=
HeteroPackaging=FirstMatch
ShowNetgroupInternalProperties=
CaptureAutoRouteBlockageFilter=
AutoRefOccMode=FALSE
orNewBlocakgeTest=
DoIncrementalAnnotationWithHoleFilling=
EnableRouteBlockageDebugging=
__CapRouteDebugDump=
GeneratePartPin2PinSpace=
EnablePageSortInAnnotation=
SymbolGraphicalElementsSnapToGrid=Master
SymbolEnablePasteOptMode=True
GeneratePartMinWidth=
DisableIsNoConnectPropForPowerPin=
DisplayCISPartPropWrtAnotherProp=
EnableFootPrint=
SymbolTextElementsSnapToGrid=Fine
FillRefdesInCopyOldBehavior=
capForceEnableIncrementalAnnotateOption=
GeneratePartMinHeight=
ReadPackageTimeZoneInfo=
DescendSchPage=Ask
CapIgnoreReadPCBReuseLowLevelHier=
GeneratePartStartEndMargin=
JunctionMode=OnWireBreak
CustomElectricalDrcRules=capDevicePinMismatch_capRunDrc,capHangingWires_capRunDrc,capPartReferencePrefixMismatch_capRunDrc,capPortPinMismatch_capRunDrc,capShortedDiscretePart_capRunDrc
CustomPhysicalDrcRules=capInvalidPinNumber_capRunDrc
capAutoAssignVoltageOnPowerNets=FALSE
capDefaultGroundValue=
capDefaultGroundNames=
orSIConnector_refPrefix=
ORCM_ENABLE_ECSETAPPLY_WARNING=
AUTO_XNETS_USING_GATES=
TransferNetPropToFlatNet=
orSICapacitor_refPrefix=
EnableWireLocking=
capDefaultPowerValue=
orSIResistor_refPrefix=
PspiceErrorCodeToSuppress=
AllegroCharLimitInINI=FALSE
DoNormalRotationForPinNameNumber=
IssueUndoWarning=FALSE
SynchronizeNGAliases=
EnableGlobalNetITC=1
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

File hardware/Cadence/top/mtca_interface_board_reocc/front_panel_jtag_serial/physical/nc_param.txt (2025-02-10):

INTEGER-PLACES         3
DECIMAL-PLACES         5
X-OFFSET               0.000000
Y-OFFSET               0.000000
FEEDRATE               1
COORDINATES            ABSOLUTE
OUTPUT-UNITS           METRIC
TOOL-ORDER             INCREASING
REPEAT-CODES           YES
SUPPRESS-LEAD-ZEROES   NO
SUPPRESS-TRAIL-ZEROES  NO
SUPPRESS-EQUAL         NO
TOOL-SELECT            YES
OPTIMIZE_DRILLING      NO
ENHANCED_EXCELLON      YES
HEADER                 none
LEADER                 12
CODE                   ASCII
SEPARATE               NO
SEPARATE-ROUTING       NO
DRILLING               LAYER-PAIR
BACKDRILL              NO
CAVITY                 NO
COUNTER                NO
TOLERANCE_DRILL        NO
TOLERANCE_TRAVEL       NO
TOOL_SIZE              NO
ROTATION               NO
NON_STANDARD           NO
TOTAL_DRILL            NO
SEPARATE_SLOT          NO
SUPPRESS_TOLERANCE     NO
SUPPRESS_TOOLSIZE      NO
SUPPRESS_ROTATION      NO

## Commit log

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2023-01-20 Editing to fix bugs (presumably shortcuts that are allowed in CIS but not DE-HDL
    [page1.csv, page2.csv]
2023-01-20 Edited top.cpm to add START_CONSTRAINT_MGR/AUTO_XNETS_USING_DML ‘OFF’/AUTO_XNETS_USING_GATES ‘OFF’/END_CONSTRAINT_MGR ( see https://webapps-pp.bris.ac.uk/elog/DUNE/63 ). Opened schematic. Saved schem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
    [expand.cfg, page1.csv, page2.csv]
2023-01-20 Replaced page boarders from CIS with DE-HDL ones that correctly show the page numbers
    [page1.csv, page2.csv, page3.csv]
2023-01-20 After first failed physical export. Need to change PCB design to only export XNET for devices
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2023-01-25 Changed XTAL for TCXO (item 23) , VDDO moved to 2.5V (item 22), Changed D-FF (item 1)
    [expand.cfg, page1.csv, page2.csv]
2023-01-27 Generated new symbol for timing block. NB. Creating symbol only seems to work on Linux
    [cases.cfg, expand.cfg, page1.csv]
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2023-01-27 Changed port definitions for SFP_DATA and PLL on timing and FPGA blocks
    [cases.cfg, expand.cfg, page1.csv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]
2023-01-30 More hacking with capacitors and resistors. Not yet exporting cleanly to PCB
    [expand.cfg, page1.csv, page2.csv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]
2023-01-30 Sorted out physical export issue. Need to add cis_hep_partslib/cis_hep_partslib/Allegro_Library/symbols
    [page1.csv, page2.csv]
2023-01-30 Removing modules with (incorrect) capital letters from generate-view. Can get correct (lower case) names using Linux with just the modules (not top level) opened
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2023-01-31 Replaced connection to SFP for auxiliary IPBus GbE with connection to SATA connector
    [page1.csv, page2.csv]
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2023-01-31 Starting to split LVDS signals incorrectly connected to 3.3V bank away from Trenz connector
    [page2.csv]
2023-02-02 7. LVDS I/O moved from bank 14 ( which is 3.3V only) 8. Moved 3.3V I/O ( PLL control lines, I2C lines , SFP lines) from banks which have been moved to 2.5V to bank 14 8A /16 Removed I2C extender.
    [page1.csv, page2.csv]
2023-02-02 18. Moved data from SFP fanout to clock compatible pins on Trenz
    [page2.csv]
2023-02-02 Disconnected VCCIO for banks 13,15,16 from 3.3V and connected to 2.5V. 6B -replaced VP3V3 with VCC3V3 for power input to FPGA
    [page1.csv, page2.csv]
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2023-02-02 Fixing bugs in timing pages - replaced 800mA 0603 inductor with 2A 0805 inductor. Connected decoupling caps to ground - instead of having them float ....
    [page3.csv]
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2023-02-02 Copied top top mib_tongue2 with aim of making tongue2 a separate board
    [cases.cfg, expand.cfg, page1.csv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]
2023-02-02 Edited tongue2 schematic to include just the tongue-2 uTCA AMC connector ( not both tongue1 and tongue2 )
    [page1.csv]
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2023-02-02 Placed connector for UART. N.B. Need to edit top.cpm to replace Unix paths with Env. variable based ones
2023-02-03 Adding a CLC filter to VIN pins on Trenz. Adding a 12V input for when we have the pseudo-trenz board ready
    [page2.csv]
2023-02-08 unfinished changes to power supplies to test merging sch changes in git
    [expand.cfg, page1.csv]
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2023-02-21 Added LTC2991 (which will replace the LTC2945)
    [page1.csv]
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2023-03-01 Minor bug-fix to schematic - replaced temp sensor with current monitor on 2v5
    [page1.csv]
2023-03-01 Replaced MOSFET used to turn on 1v8 indicator LED with the same one used for DC-DC enable
    [page3.csv]
2023-03-01 Hacking schematic to get physical export to work. Had to delete multiple capacitors iun power module
    [page1.csv, page2.csv, page3.csv]
2023-03-02 Editing top level block diagram (no connectivity changes, just diagram). Printing schematic
    [page1.csv]
2023-03-06 Added ROOM property to blocks. Deleted un-needed connection of 12V to trenz compatible module. Removed stray resistor
    [page1.csv, page2.csv, page3.csv]
2023-03-06 Moved decoupling capacitors around. Make PATH property invisible. Added back capacitors deleted in effort to get physical export to work. Exported to /mib_rev2_v{18,19}.brd. Printed schematic to hard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
    [page1.csv, page2.csv, page3.csv]
2023-03-06 Set ROOM property to invisble on a couple of straggling pages. Printed out schematics
    [page1.csv, page2.csv]
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2023-03-07 Added long net names at top level to make schematic and PCB easier to read. Created differential pairs. Still lots of DRCs. Need to sort out PG lines in MMC/POWER blocks - many missing in new design
    [page1.csv, page2.csv, page3.csv]
2023-03-08 Changed POWER bus to be concatenation of individual signals. Replaced bus-rip with merge. This needs checking! Exported to mib_rev2_v29.brd
    [page1.csv, page2.csv, page3.csv]
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2023-03-14 Room DRCs removed. Only 1 DRC remaining - mounting hole conflicts with card edge keepout zone. Need to check requirements of mtg hole and keepout zone before I can resolve.
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2023-03-14 editing power planes for DC/DC converters. Lots of issues with rounding errors of shapes from old design. ISSUE- O/P of both DC/DC converters is connected to VCC2V5_PRE_RSHUNT. suspect it's because o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
2023-03-16 Modified schematic to rename output busses of DC/DC converter modules. They were both VO<1..0>, which meant they were connected together. Renamed to VO_3V3<1..0> and VO_2V5<1..0> to keep them separat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
    [page1.csv, page2.csv]
2023-03-16 Started laying out shapes and components for 3V3 DC/DC Converter. IsSUE: C77 one pad is not connected to a net - should be GND. Schematic looks ok but there is no actual electrical connection there s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
2023-03-16 changed schematic to connect pad 2 of C77 to GND and exported physical. Change shows up ok on BRD.
    [page1.csv]
2023-03-17 Fixed the following schematic bugs
    * Signals into D-FF U8,U3,U2 all had the same net names ( DFF_CLK_P<0>
    etc. ) would have wired all inputs together. Very wrong
    * One of biasing resistors for D-FF input wasn't connected.
    * Diff pairs into FPGA connector inverted ( P<--> N ) AUXIO_7 pair ,
    DATA_FROM_UPSTREAM_<1> pair, TIMING.UPSTREAM_DATA_<2> pair. Pointed
    out by Pete Hastings
    * To Do: Clock to FPGA from clock generator not connected. ( Whoops !)
    [page1.csv, page2.csv]
2023-03-17 Connected clocks from Si5495 to FPGA connectors. Show-stopping bug :-o
    [page2.csv]
2023-03-17 Physical export to /mib_rev2_v49.brd after fixing schematic bugs. eco.txt seems to indicate things went OK
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2023-03-20 Edited stackup to fit PCBTrain's bog-standard 10 layer stackup. Adjusted diff pair track widths and spacings to get 100R diff impedances on layers Top, 3, 7, 9 & BOTTOM. Saved stackup details because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
2023-03-20 Changed CSet DP_100R to have correct physical dimensions on layers top, 3, 7, 9, &BOTTOM to give 100 Ohm diff pairs. Applied that CSet to all DPrs listed in Constraints Manager. (look like some nets 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
2023-03-29 Eventually unravelled the chaos of the SFP hierarchy to assign correct power nets to SFP connectors
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2023-03-30 Started routing clocks between SFP connectors and Clk generator IC but paused due to chaos with net names and diff pairs etc. SFP2_CLKGEN_N/_P doesn't exist, SFP0_CLKGEN has been duplicated on the sc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
2023-03-30 Schematic changes: 1. SFP0_CLKGEN_P & _N duplicated at U6, one needs renaming to SFP2_... 2. CLKIN signals at U6 need renaming as diff pairs.
    [page2.csv]
2023-03-30 Connected AMC_N_ENABLE to backplane connector. Added zero ohm links to fudge MMC reset line if wanted
    [page1.csv, page2.csv]
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2023-03-30 Fixed schematic errors:
    C192 is attached to unnamed net because there is a break in the line on the schematic
    C179 ditto
    C44 is not actually connected to GND even though it looks like it.
    Exported to
    hardware/Cadence/top/mtca_interface_board_reocc/top/physical/mib_rev2_v119
    [page2.csv, page3.csv]
2023-03-30 Fixing schematic errors:
    C52 is insufficient voltage rating C25 ditto.
    Replaced single 470uF cap with two 220uF/25V caps.
    Needed to edit PADPATH in CPM file to allow Allegro on Windows to load the new footprint (for the 220uF cap).
    Exported to hardware/Cadence/top/mtca_interface_board_reocc/top/physical/mib_rev2_v120.brd
    [page1.csv, page2.csv]
2023-03-30 Unbelievable amounts of pain and suffering to try to understant the issue with CLKIN lines being defined as XNets and not Diff Pairs. I think(hope) I've sorted it now. At least Allegro lets me route 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
    [page2.csv]
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2023-04-06 somewhere between 123 and 124.brd, all GND nets got accidentally deleted. Reverted to before that happened. Re-routing diff pairs to SFP connectors and placing components - WIP. Gradually correcting 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
2023-04-13 TP9 and TP8 are duplicates, TP7 and TP15, TP6 and TP16. Removed duplicate test points. Exported to mib_rev2_v187.brd
    [page1.csv, page2.csv, page3.csv]
2023-04-13 TIMING.UPSTREAM_DATA_N,P<2..0> corrected to UPSTREAM_DATA_N,P<2..0>
    [page1.csv, page2.csv]
2023-04-14 2. Swap polarity of CLKGEN_CLK_P<0> and CLKGEN_CLK_N<0>
    3. Move CLKGEN_CLK_P<1> and CLKGEN_CLK_N<1> to J8 pins 55,57
    Board exported as mib_rev2_v189.brd
    [page2.csv]
2023-04-14 Replaced P1 MMC JTAG connector. Swapped recepticle for header. Refdes changed to J13
    Exported to mib_rev2_v190.brd
    [page1.csv]
2023-04-14 6. Replace SATA connector carrying Ethernet with four U.FL connectors (since these are low profile enough to fit underneath FPGA board
    exported to hardware/Cadence/top/mtca_interface_board_reocc/top/physical/mib_rev2_v191.brd
    [page1.csv, page2.csv]
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2023-04-17 REplaced 470uF case-E caps (C17,C44,C77,C80) with lower profile 220uF caps
    Replaced current sense resistors with 2-terminal devices and increased
    resistance value
    [bom_summary.csv, bom_summary.xlsx, expand.cfg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]
2023-04-18 Tidied up power module schematic. Placed low profile Capacitors ( replacing 470uF caps). Started routing
    [page1.csv, page2.csv]
2023-04-18 Changed one pin of UART connector to be P3V3 (to power daugther board with SFP). All components placed. All pins connectted. 94 DRCs to sort out
    [page2.csv]
2023-04-19 Continuing layout. Held up by inivisible shape that was preventing production of manufacturing data. Much messing around. Can now generate artwork. ODB++ looks wrong for bottom solder mask
2023-04-19 Tidied up daugther board PCB before producing STEP file. Created new BoM after the schematic changes. Still need to run netlist checks on schematic
    [uob-hep-pc072-v199.csv, uob-hep-pc072-v199.xlsx]
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2023-04-20 Updated BoM (caps changed for low profile etc. ). Sent to Newbury for re-quote
    [uob-hep-pc072-v199.xlsx]
2023-04-20 Added zero ohm links to output of upstream D-FF (U2,U3,U8) to allow them to be bypassed)
    [page1.csv]
2023-04-20 Changed ATMEGA128A-MU --> ATMEGA128A-AU ( since TQFP version is available but not the QFN version)
    Realized that I exported what should have been v200 and v201 to v120 and
    v121. Now exported to v202
    [bom_summary.xlsx, page1.csv]
2023-04-20 Some messing around to get export to work correctly. New package is much bigger than old package, so challenging to place/route
    [chips.prt, page1.csv]
2023-04-21 "Glossed" board v205
    Produced artwork
    Gerber files
    Drill files
    Router files
    ODB++ file
    [art_param.txt, nc_param.txt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]
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2023-04-28 Exported BoM with the six zero-ohm resistors added and footprint for ATMEGA128 changed from QFN to TSSOP
    [uob-hep-pc072-v205.csv, uob-hep-pc072-v205_28apr23.xlsx]
2023-05-02 Exporting Gerber files describing 'hard gold' areas. Sorted out minor bug in artwork definition for 'hard gold bottom'
2023-05-12 Responding to issues raised by Newbury (inadequate spacing)
    [nc_param.txt, uob-hep-pc072-v205_28apr23.xlsx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]
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2023-05-15 Trying to remove DFM errors flagged by Valor (looking for problems in response to Newbury complaints
    [nc_param.txt]
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2023-10-19 Exported front panel design to Gerber. Set pin numbers on MMC uController to show on schematic
    [art_param.txt, nc_param.txt, page1.csv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]
2023-10-19 Re-generated *.drl file but this time with Auto-Tool selected in Allegro. Seems to make Gerber viewers happier
    [nc_param.txt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]
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2024-06-07 Replaced image on page1 of top level schematic
    [page1.csv]
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2024-06-11 Added 3 pin connector - for 3.3V MP and 12V payload power when on bench
    [chips.prt, page1.csv]
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2024-06-19 first item added
    the 2x1 header for shorting reset to gnd
    [chips.prt, expand.cfg, header2x1_str.psm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]
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2024-06-21 Three issues implemented in schematic
    Continuing to work through other items before doing layout alteration
    [page1.csv, page2.csv]
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2024-06-26 854S01AKILF Hidden symbol pins!
    Hi, not too sure you will be happy with my workaround for this but whoever made the schematic symbol has hidden the power and gnd pins. GND is fine but the "VDD" rail will not short to the 3V3 provided. I have altered settings within Concept HDL to let me use a synonym (which does work but not on the logical net set by the symbol) to short the 3.3V and VDD but it doesn't work. I have used a ferrite bead to join the voltages together and some bypass caps.
    [page1.csv]
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2024-07-03 Hierarchy sorted - net names fixed
    [page1.csv, page2.csv, page3.csv]
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2024-08-19 routed
    might need tidying but pin swapping complete as per requests
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2025-02-11 Copy standard/alias to archive_libs to avoid error messages from front_panel_jtag_serial project
    [expand.cfg]
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2025-02-13 Removing front_panel_ethernet_jtag_serial design. We won't ever use it...
    [expand.cfg]
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2025-02-24 Replaced (incorrect) yellow side-launch LEDs with one blue one red. Rotated switch SW1. Exported to mtca_interface_board_reocc/top_mib_v3/physical/mib_rev3b_v225.brd
    [page1.csv, wurth_smsw.psm]
2025-02-24 Changed R60 to correct 2.5V voltage (was 3.3V with previous value
    [page2.csv, wurth_smsw.psm]
2025-02-25 Fixed bizzare issue that one of the two side-launch LEDS (blue/red) got given the Ref Des MMC when exported to PCB. Fixed this by editing the RefDes in PCB and then doing physical-import back to sche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
2025-03-10 New Red/Green LEDs with footprint
    And corrected schematic for 3V3 on buffer/LED supply. The forward voltage on new LEDs are 2V for both red and green weirdly; used a 270R to give approx 5mA drive.
    [led_dialight_591-3xx1.psm, page1.csv]
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2025-03-11 Reverted back to 3V3 led drive
    Still wary of the 0.8V across the diodes when buffer is high output; layout needs implementing but the diodes are in position.
    [page1.csv]
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2026-10-05 Committing end-of-day work. Working through issues
    [chips.prt, kpa2107lvvbcd.psm, page1.csv]
2026-10-06 Changes responding to issue #67. Board exported to v229 and layed out.
    [page1.csv, page2.csv]
2026-10-06 Changes responding to issue #79. Board exported to v230 and layed out
    [page1.csv, page2.csv]
2026-10-06 Changes responding to issue #70. Board exported to v230 and layed out
    [page1.csv, page2.csv]
2026-10-06 Changes responding to issue #68. Board exported to v231. No layout needed
    [page1.csv, page2.csv]
2026-10-06 Changes responding to issue #64. Board exported to v231. No layout needed
    [page1.csv, page2.csv]
2026-10-06 Changes responding to issue #73. Exported to mib_fp_jtag_serial_31.brd
    [mib_fp_jtag_serial_31.brd, page1.csv]
2026-10-07 Copied schematic symbols and footprints for various switches into local directory. Edited schematic to disconnect backplane JTAG from MMC uController and connect to FPGA module via switches. In respo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
    [cas220ta1.psm, chips.prt, page1.csv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]
2026-10-07 Routed PCB changes associated with issue #78 (backplane JTAG). Exported schematic to hardware/Schematics/dune_mib_v3b_7oct26.pdf
    [page1.csv, page2.csv, page3.csv]
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2026-10-28 Replaced 220uF input capacitors to main DC-DC converters.(in response to Erdem's review (issue #80). Some layout changes needed - capacitor footprint subtley different
2026-10-28 Adding schematic changes for replacement of 220uF input capacitors to main DC-DC converters with 330uF
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2026-11-05 Worked on BoM, merging some duplicate components. Replaced U18 PROM with larger capacity. Added details to ECR spreadsheet
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2026-11-06 Corrected a bug and merged a duplicated line in Cadence/top/mtca_interface_board_reocc/top_mib_v3/bom/mib_v3b_v233_cleaned.xlsx with the aid of ClaudeAI
2026-11-06 Updating manufacturing ZIP archive with bug fixed BoM
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
